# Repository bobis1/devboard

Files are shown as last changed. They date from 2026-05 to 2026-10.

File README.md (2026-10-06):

# Eduboard
A devboard with an inbuilt screen and a software platform that should help beginners learn the basics of computer science. This is a rp2040 devboard at it's core.

I made this project because I wanted some experience working with devboards before I start something more complex. I also wanted to make something where a microcontroller was on a devboard already.

### Pictures

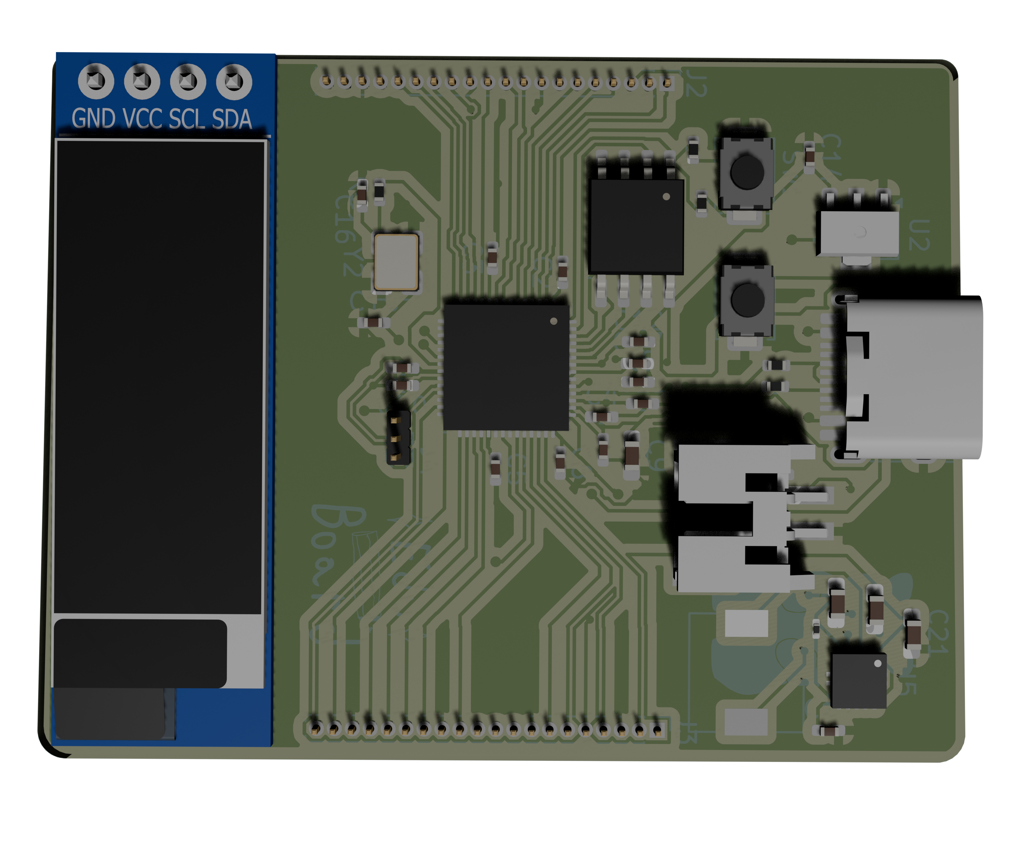
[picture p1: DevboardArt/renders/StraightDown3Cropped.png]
Render

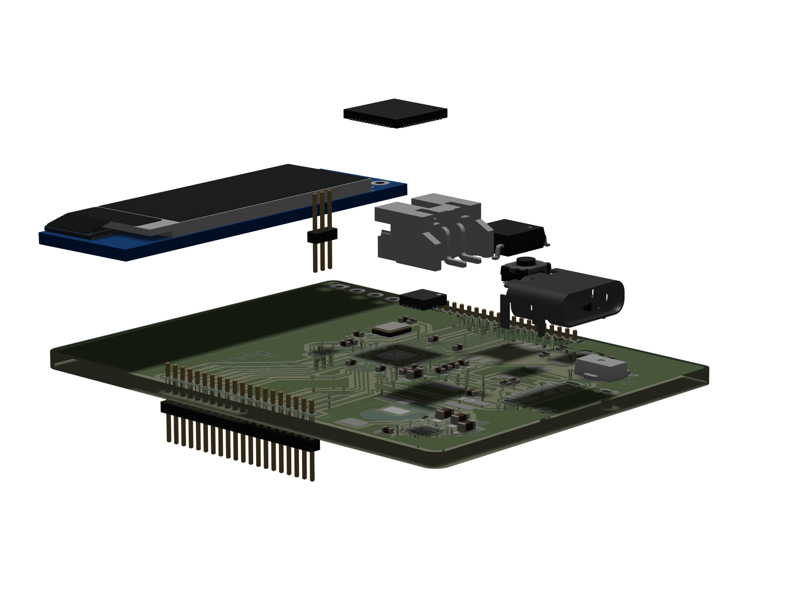
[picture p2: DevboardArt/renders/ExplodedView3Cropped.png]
Render

Above are renders made in blender.
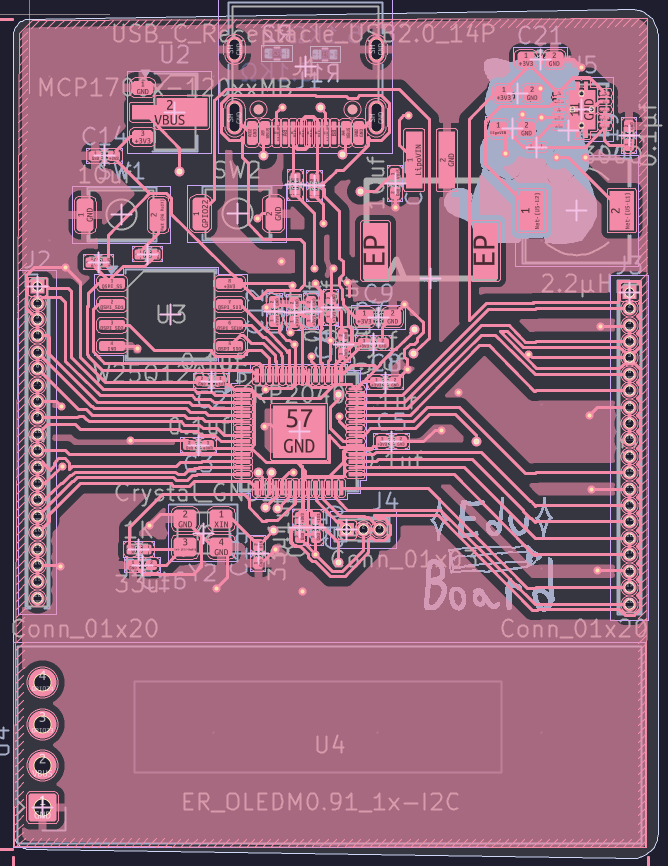
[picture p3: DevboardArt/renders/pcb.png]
pcb

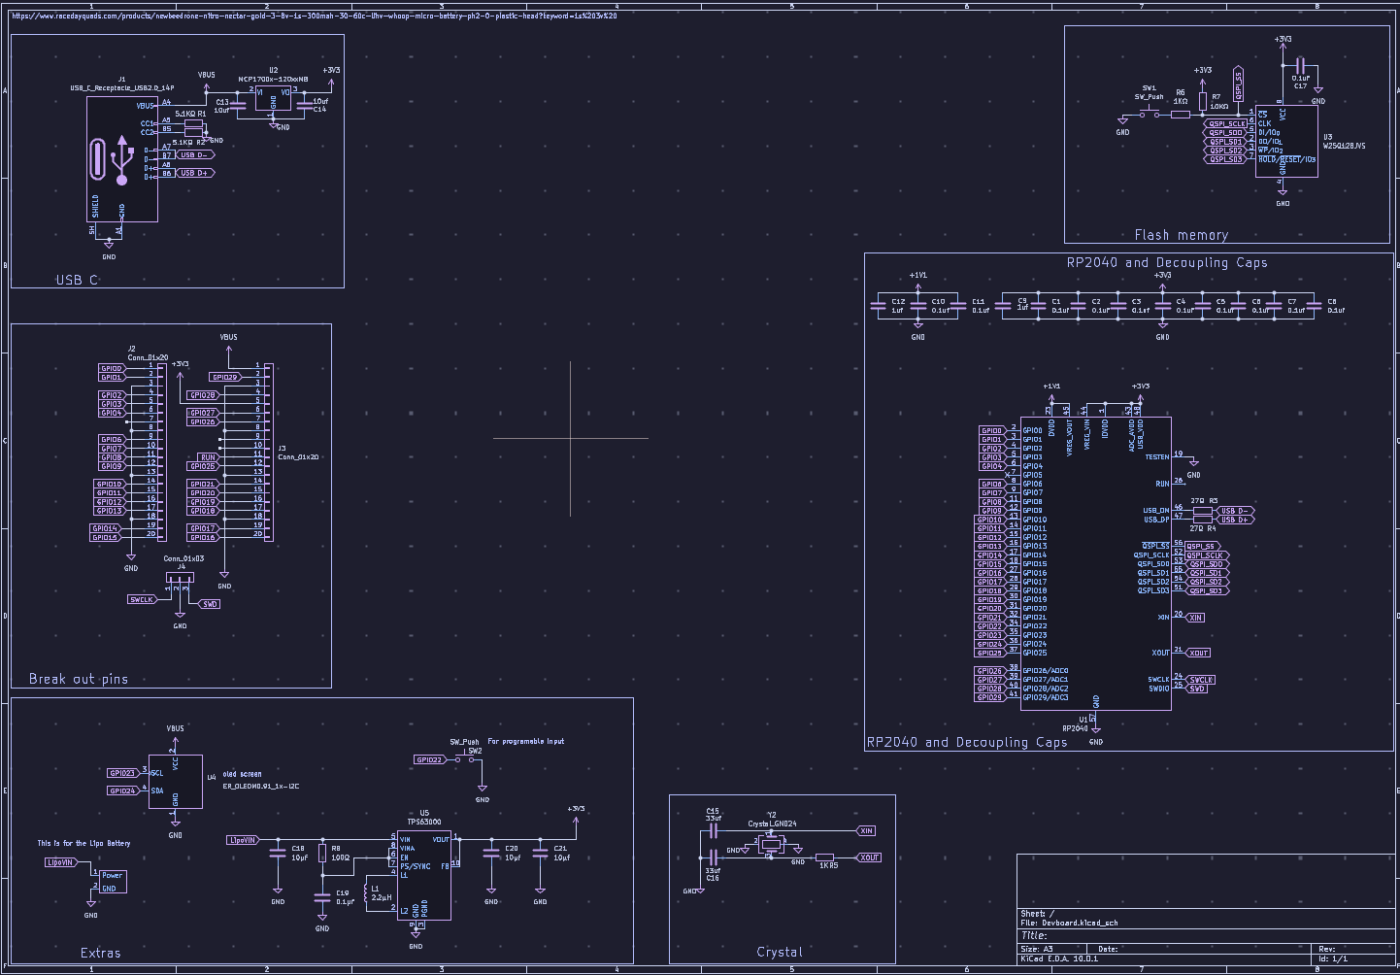
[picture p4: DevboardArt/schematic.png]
schematic


### Assembly
The assembly of the devboard is relatively straight forward. The first thing you need to do is you need to get a hotplate and some soder paste to carefully soder on all the SMD components onto the pcb(This will be new to me as I have never done it before). Then you need to soder on the header pins onto the pcb by placing your sodering iron on the joint between the pcb and the pin and putting solder into that joint.

### Flashing
The flashing of this works the same way as a normal raspberry pi pico. You need to hold down SW_1 to start the flashing process.

### BOM
This BOM is for non PCBA. To be clear, I plan on using the bill of materials labeled [BOM](BOM.csv), [BOM-PCBA](BOM-PCBA.csv) is a BOM if you want to PCBA part of it.

|Reference |Qty|Value |Footprint |Datasheet |Description |Shopping Link |Unit Price|Prices|Notes |
|---|---|---|---|---|---|---|---|---|---|
|C1,C2,C3,C4,C5,C6,C7,C8,C10,C11,C17|11 |0.1uf |C_0402_1005Metric_Pad0.74x0.62mm_HandSolder | |Unpolarized capacitor |https://www.lcsc.com/product-detail/C1591.html?s_z=s_p_CL10B104KB8NNNC |$0.00 |$0.46 |Minimum quantity: 50 |
|C9,C12 |2  |1uf |C_0603_1608Metric_Pad1.08x0.95mm_HandSolder | |Unpolarized capacitor |https://www.lcsc.com/product-detail/C59782.html?s_z=n_q_CL10B105KO8NNNC |$0.02 |$1.06 |Minimum quantity: 50 |
|C13,C14, C19 |3  |10uf |Capacitor_SMD:C_0603_1608Metric_Pad1.08x0.95mm_HandSolder | |Unpolarized capacitor |Samsung Electro-Mechanics CL10A106KP8NNNC |$0.01 |$0.54 |Minimum quantity: 50 |
|C15,C16 |2  |33uf |C_0402_1005Metric_Pad0.74x0.62mm_HandSolder | |Unpolarized capacitor |https://www.lcsc.com/product-detail/C76930.html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 |$0.01 |$0.54 |Minimum quantity: 50 |
|C18,C20,C21 |3  |10μf |C_0402_1005Metric_Pad0.74x0.62mm_HandSolder | |Unpolarized capacitor |Samsung Electro-Mechanics CL10A106KP8NNNC |$0.01 |$0.54 |Minimum quantity: 50 |
|J1 |1  |USB_C_Receptacle_USB2.0_14P|Connector_USB:USB_C_Receptacle_HRO_TYPE-C-31-M-12 |https://www.usb.org/sites/default/files/documents/usb_type-c.zip |USB 2.0-only 14P Type-C Receptacle connector |https://www.lcsc.com/product-detail/C165948.html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 |$0.17 |$0.86 | |
|J2,J3 |2  |Conn_01x20 |Connector_PinHeader_1.00mm:PinHeader_1x20_P1.00mm_Vertical| |Generic connector, single row, 01x20, script generated (kicad-library-utils/schlib/autogen/connector/) |https://www.aliexpress.us/item/3256811704196969.html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 |$2.36 |$2.36 |Minimum quantity: 5 |
|J4 |1  |Conn_01x03 |Connector_PinHeader_1.00mm:PinHeader_1x03_P1.00mm_Vertical| |Generic connector, single row, 01x03, script generated (kicad-library-utils/schlib/autogen/connector/) |https://www.aliexpress.us/item/3256811704196969.html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 |$0.00 |$0.00 | |
|L1 |1  |2.2μH |Inductor_SMD:L_6.3x6.3_H3 | |Inductor |https://www.lcsc.com/product-detail/C52722262.html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 |$0.04 |$0.41 |This comes with the above 01x20 pin headers|
|R1 |1  |5.1KΩ |Resistor_SMD:R_0402_1005Metric_Pad0.72x0.64mm | |Resistor |https://www.mouser.com/en/ProductDetail/Vishay/CRCW04025K10FKED?qs=s0g2FHNyNFj8r6Uw5EJZ%2Fw%3D%3D |$0.10 |$0.10 |Minimum quanity: 10 |
|R2 |1  |5.1KΩ |Resistor_SMD:R_0402_1005Metric_Pad0.72x0.64mm | |Resistor |https://www.mouser.com/en/ProductDetail/Vishay/CRCW04025K10FKED?qs=s0g2FHNyNFj8r6Uw5EJZ%2Fw%3D%3D |$0.10 |$0.10 | |
|R3,R4 |2  |27Ω |Resistor_SMD:R_0402_1005Metric_Pad0.72x0.64mm | |Resistor |https://www.mouser.com/en/ProductDetail/YAGEO/RC0402FR-0727RL?qs=UOUeRUa%252B8Wlb37UyFHw9Bw%3D%3D |$0.10 |$0.20 | |
|R5,R6 |2  |1KΩ |Resistor_SMD:R_0402_1005Metric_Pad0.72x0.64mm | |Resistor |https://www.mouser.com/en/ProductDetail/YAGEO/RC0402FR-071KL?qs=V1yeUXFNrknDEmWLmm5v6g%3D%3D |$0.10 |$0.20 | |
|R7 |1  |10KΩ |Resistor_SMD:R_0402_1005Metric_Pad0.72x0.64mm | |Resistor |https://www.mouser.com/en/ProductDetail/YAGEO/RC0402FR-0710KL?qs=I1mnnYJTTsxUoNwrUsQExA%3D%3D |$0.10 |$0.10 | |
|R8 |1  |100Ω |Resistor_SMD:R_0402_1005Metric_Pad0.72x0.64mm | |Resistor |https://www.mouser.com/en/ProductDetail/Vishay/CRCW0402100RFKED?qs=OlqPY1CiralT1EG%2F62gJpQ%3D%3D |$0.10 |$0.10 | |
|SW1,SW2 |2  |SW_Push |Button_Switch_SMD:SW_SPST_TS-1088-xR020 | |Push button switch, generic, two pins |https://www.lcsc.com/product-detail/C49234124.html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 |$0.02 |$0.49 | |
|U1 |1  |RP2040 |Package_DFN_QFN:QFN-56-1EP_7x7mm_P0.4mm_EP3.2x3.2mm |https://datasheets.raspberrypi.com/rp2040/rp2040-datasheet.pdf |A microcontroller by Raspberry Pi, Dual ARM Cortex-M0+, 133MHz, no flash, 264KB SRAM, 8 PIO state machines, VQFN-56|https://www.digikey.com/en/products/detail/raspberry-pi/SC0908-7/14306009?src=raspberrypi |$0.92 |$0.92 | |
|U2 |1  |MCP1700x-120xxMB |Package_TO_SOT_SMD:SOT-89-3 |http://ww1.microchip.com/downloads/en/DeviceDoc/20001826D.pdf |250mA Low Quiscent Current LDO, 1.2V output, SOT-89 |https://www.microchip.com/en-us/product/mcp1700#Purchase(3 leads, SOT-89 packaging) |$0.51 |$0.51 | |
|U3 |1  |W25Q128JVS |Package_SO:SOIC-8_5.3x5.3mm_P1.27mm |https://www.winbond.com/resource-files/w25q128jv_dtr%20revc%2003272018%20plus.pdf|128Mbit / 16MiB Serial Flash Memory, Standard/Dual/Quad SPI, 2.7-3.6V, SOIC-8 |https://www.lcsc.com/product-detail/C97521.html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 OR https://www.lcsc.com/product-detail/C97521.html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|$2.62 |$2.62 | |
|U4 |1  |ER_OLEDM0.91_1x-I2C |Display:ER_OLEDM0.91_1x-I2C |https://www.buydisplay.com/download/manual/ER-OLEDM0.91-1_Datasheet.pdf |SSD1306 OLED module, 0.91 inch, 128x32, I2C |https://www.buydisplay.com/i2c-white-0-91-inch-oled-display-module-128x32-arduino-raspberry-pi |$2.80 |$2.80 | |
|U5 |1  |TPS63000 |Package_SON:Texas_DRC0010J_ThermalVias |http://www.ti.com/lit/ds/symlink/tps63000.pdf |Buck-Boost Converter, 1.8-5.5V Input Voltage, 1.8A Switch Current, Adjustable 1.2-5.5V Output Voltage, VSON-10 |https://www.ti.com/product/TPS63000/part-details/TPS63000DRCR |$2.00 |$2.00 | |
|XT1 |1  | |JST-PH-2.:JST-PH-2 | | |https://www.adafruit.com/product/1769 |$0.75 |$0.75 | |
|Y2 |1  |Crystal_GND24 |Crystal:Crystal_SMD_3225-4Pin_3.2x2.5mm | |Four pin crystal, GND on pins 2 and 4 |https://www.lcsc.com/product-detail/C13738.html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 |$0.09 |$0.47 | |
| | | | | | | | | |Minimum quanity: 5 |
| | | | | | | | | | |
| | | | | | | | | | |
| | | |Subtotal: |$0.00 | | | | | |
| | | |PCB Fee: |$0.00 | | | | | |
| | | |Shipping: |$2.00 | | | | | |
| | | |Tariff: |$0.00 | | | | | |
| | | |PCBA fee: |$45.96 | | | | | |
| | | |Total Price |$47.96 | | | | | |

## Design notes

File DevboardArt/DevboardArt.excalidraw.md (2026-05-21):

---

excalidraw-plugin: parsed
tags: [excalidraw]

---
==⚠  Switch to EXCALIDRAW VIEW in the MORE OPTIONS menu of this document. ⚠== You can decompress Drawing data with the command palette: 'Decompress current Excalidraw file'. For more info check in plugin settings under 'Saving'

# Excalidraw Data

## Text Elements
## Embedded Files
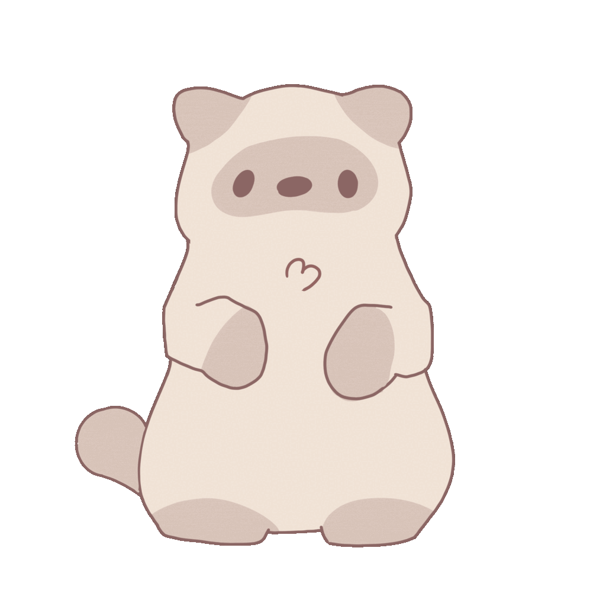
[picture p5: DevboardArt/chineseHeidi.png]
c69bee7dd71ced548cfc6c9a045980190fc850d2: 

%%
## Drawing
```compressed-json
N4KAkARALgngDgUwgLgAQQQDwMYEMA2AlgCYBOuA7hADTgQBuCpAzoQPYB2KqATLZMzYBXUtiRoIACyhQ4zZAHoFAc0JRJQgEYA6bGwC2CgF7N6hbEcK4OCtptbErHALRY8RMpWdx8Q1TdIEfARcZgRmBShcZQUebR44gEYaOiCEfQQOKGZuAG1wMFAwYogSbgg2AAUAMwBxNlrJAGsAESaAFWxsJsTqgHZNfABFACUU4shYRHLqwIRPKn4SzG5n

RL6AFm0AVgBmbb6eAA4ebaOABgBOADYNvqXIGFXr8+1znkueF7vdjY3E/4PCAUEjqbgXHaJS7nRI8DbbRLrRJHI5AyQIQjKaTcWGJHZnS7bS43K67PrbIHWZTBbjXN4bS7wj59XbnXaJa59e4FARQUhsJoIADCbHwbFI5QAxIkEDKZeMSppcN1lPyhBxiCKxRKJHzrMw4LhAlkFZBqoR8PgAMqwGkSQQeU0QZh8gUIADqoMk3D4POdrsFNpgdvQD

rKQLVWI44RyaESQLYhuwaiecfO5yBquEcAAksRY6h8hNIAANCikfTMABaRkwbHoAEF2kIAGJW6pDACqnyrEB5AF0gbNcBk89wOEJLUDCBqsOVcFbak61Rro8wCxOp36wvMcTxYcTzi9fRMGExWJxwWygYwWOwOAA5ThiHFko6IxK7E7T5gtNJQXc0GqAgwiBTRhA1ABRYIMiyAtckHP0hDgYhcAA4gcS5S5dg+HhzhOREgSIDgmnHSd8CIthukA1

BgPwUC/TgNgZ2yPIeTAItiwzdiwHOdjEOLTiJleBkjiJa4oQBI9TgeYpXhRC4JO2HhfjJbZ+NkoTijxI9tluXZ2XObYNmuI5yVk3idj+U5zg2FFjlhdTiwEiYtLAPFLg5DkCOOaFrhkni8TuTY7m2K4+muPTTg09i3LiIy+kJY4LjE7DzJ43Y3kuE5dheI5dmyjY1JiwSeKSZSir2d4WSK9LizAbZ4iJHguVU8kStcsr4hMxkTg2fczIpHi6TOPY

UWRfY0qciYXOKOLtF+AEJORDkNmkob6suHYcNOPp8PTPp32i5zNK6j5+qhS49r29kAvqz9tERCKmWuXK+mRdqTtis7GX3YlrrZRyLPWbqcKOCSwccjq5p+i7/vOG6gbKvE9L2UzIpU2rpuKWaOK6y6Adujbiy+BbDpeRIEYuwbobx+q4jha5erhAa6uLHD4kOArD0x4qvtK+nHoq/ZWRatriYmfZtH+A5Kb+T4PuxsBcbcjzXqK4l/jW/yJeKfrH

r+O53gBI4sdp1XtAI0yDk8mEot1sAGTePCwsOqH+c6+7tvfHrDkinWLL0x7POOf5EtMz6ZtOr2GSuBKJPewbA62z4CrCqE9ndqPvq93T9MM4yI4dzlts5IrVvW82eNeYyzjJNbebZiZNm0QlWVem47LNj2Yfq14vhUj5KcSe2LMO6Wjmw5FTYi+2q/q5x+4OP5/Mn9aLLE+JkQR8HPwc47s4F4s1iF5SarUizsMtz8kS/TlFfn4+8X8rkuSuEkps

vvpLcn25Tb5w+nsn7X1Mu8K6YkR4Bx4sSbQ5JvhwguCZGmPc6bHySKFfKB0joO0pplWy1wmbIkZJnA+ONo5oJ2KceBdl8FJ0CkZS2JlThwi1pXFBblnBxHevCYkLxP70O/usFSr195KxVjxZweD4RkhuHfROTdtJXAngjFknwDjYMfhMSR8R3y3E5McBEo9AqIisvsRKw857sIkZlMkSkbichuHQ+6D12TrF0v1RxkcyE52Pplfqvx0xmTXlA5xW

xbKm0CYdPypDlbkK0ZlBE5ivwTSJBfYxjV/G3HTm3LO3ij7xO0JFex4cnHFkRHSRK9kNFWIXplPaTMrjrE8TgkGplcLCMhjE8RtTYHGW3tCE4gM7plORNLKEEkCHElZmIuJxRtGm3Bq9AyWCkahIWkVHeENRGaLmZlBZBCDKsh3qskZ8kjw5RZLQrxsSfEFIuACBIiJPLa2GRMSmdIVKeRuK/cWOywDzJhP1fckkXk4LZKDCuOs/naNRiPMKuFmm

X0yo5YyU9bhsMAb3XxWUB74QZHwtJ9VTbbVsqjDxRdoVcIkmZT8b5okO0SpQhGCIcldNmf8pI6ZXEtU+Ii4aW0jLYS+EiZBmLUFaLxHhU4S0u6EuLESHRhcHnqNyTc/Jcyl4hVXvSwO/c7L7Bdsctlty5JbzCkEnVPETKwIkipK5MyTXuTeP7IqBckEKMdv3Q6CME4PxqWUwpiU0Wgosr8baHIuSM1JNc7pAbZEa0ZFJEJ7MPKv0eQ4il/qJgM1+

gTBGQyHbHHiIyI8LITjVLFfNKq8JIrktKdmxqxlcprU/PfUVeSgHZtgVCOyLNFYWRUgtAy+Lo0OvVWAOIu9hEHASP7V5xR9zS3vjhPS+VUkxvZXEQky9CRPX7YFFOfwzgrONeOvBYDoSHC+EY+6RwbV13Bna91Y7O3FDwfC/y8I931u0t/fKXx/gU0sZWjKBs7h/DMqyZ9wNv60M/J3f+G7HXIs+DCAhdtk1vLpIiZtmwCVIbPfEAqu1sHAwyV8d

4ex6V/MyscDGhJ/gYfne5LYRJ3lHqJjRodZJrospITgupelPxrQMnhTjWa32FKEYlIyYssbA0nQkNKMIRUEdfWATK0J8LrBpaO4GeIImvUOPm8TIH6pbBaiiAqH5OlgsKdSwk5IM6mY7ViiYWwS25XBspcWG9W79V01NP5jVcp6QmfuPTPFv4TJk1yE23czPysKTCSe75sKTTlRMOkvLvJ7W/WptzxRGr5V0cpf9BaLLYc+H8L8dw50vsK2AOk1V

JIcgi/w+qjaqPbFdhW1z4rijYf3HtRjkDmNbAikdEKSbT3qcaldTWxIESqYdplIunketyYAf1tyxXkkY3K0TAdltlIEJw9siTDVCkMg5FM/dgsjymWHR/bbaq5s7CpiPOLsqPV4mWZTcG/UVWzca41FqiI7KmUhcxmu1kwp2XLaq2NExGpsgRyPTyJSPWLyyv4xHIOBuO16Z+FkQ8mMOxx27E42UDKFVe8jvWkIETSRU/Iinf2Ej4WlayhrhOtjI

iKsKtnFkT6PtC1e+rXHPkkZOVo14VOPj5QKoh3n80BnmqOW7ZjOOATDvY9IpHm7ClwhuMzamHqRImVsgyaZfy4hfjMu8YjwOHavGyv5K6LxNi28u+VOEItqq+cCtLLkfxyThUl5dtWqlNYzcLc6p7vwXsFcJwZ0ynw9owh58d8kcPwn49V8Hhxwb16gbhD1zYu6Vt/JRmJf4jv8urdbicD42V7U14WrIz4Lfr2YcZ7La25jycd9OCZOR92ksfmwj

PSPiWu2MzN9M0Nlsk/4cL4LfRcJcSRfqrRxknJWoJZ26Boy7xP3LeF11XPQP88Xbn5Jw5b8nPZ7OiIpzJkfvr/ZvZ+EvXZfaUthui2T6ze0azCVSz3hwnNxwWlmOHZH6nwjpxTzclYxHneTwkb2BjeFNj2FymeQxWP3M0tinhaj+DjwsnlzWgl2A0IKSwSC/Aihfz7mLXBnJD2HelHWCw+02C+24RVxF1eF10WiPA40N0dWKzrzJFZwnzlx2DEgd

xSSC0uw+S8m80bgpzd0OlFnTGczEPHRGh6gIU23Pmxw5zwhOD4xc1AMJz/UzyEx83kwkTdyHgjmkPbWsLcjvU5EOSQI0J/nTCKSaUzXvzAC2h80nlOzehkI1VbhcIb2ryj1eHrnhHOQy2x3l3fGpyV18JrzxE/FshLz73+VeHVljmKWaVyNbgMguBZEuWgycIWhRE8iAyhSjziGMguEcwqwaKhBYVq1nlaJCIeja1qzZBwm6OYK5X+guC22QMCjC

QpkUnRSKP7ndzYLJEpiUKGK2DLiQVjxDWrmlit3lh9yGLBxRHJFJ2gIoOuwQUimoMGNoLeXmyuh61Sky1NSiQsI1gNwJ1VjpAuHwkOBmJMNd2bw9wiiplOKeN/WSxlluETQOK9mOHCj2DDgqKjzvSRDE2AP/ydQC3gPMJyKjy2lOBmNtSgyLiwK5neCjS2JhInSSNQ1S0cIe3WEz10L+ORh2BqmYV5SpK6lujWlNjuF7y5PpnQWtyIV+Pjx4U2BZ

ABBlLtz8Ta2hDgLEzxMnVO2Wlsztw8zgPJBYXINA1UnfFwUMUeI8LKkbUnmhDuAgRvW/xuwBB5l+V9z/WPRfjIKROLHAKMn2AUjbTmPpi2lpRRCPBHnUIsi2H6nLmWPFJJi2kSj6XJ2jJ5O8htgsUtIZw0x0nejJOMht2iKJ0m1hGm1BRo2fjEkLh/SJ0WVygNSowIKtN3z333DD3JAKlL062dRRMSRdxowszJH3HZF+AGOY0ain36NnwZKliU2U

halPy1wdknKeWnJoJbPZmy3bgMkLIVlrNR1XiMnWAHMuy/Fbk/WnwQ1ZN9IvJ4WTy/3czyNyk/Eng5FTKtW7TVJMjOA1ITKfNgU91MnhERnG3TMH1tjG0fL1j8UMS/HwnXQdgs0YK5CbOzPZXhEen9LiyujFKb3Sw5EijZGo0u2tXkMOGq0QQFN30KVqwuKZn4z+TuEKQOFsl+FYqO1A2slsnehBWbJzKdkMnslXTSKbyuByjymVyP03JR3kj2ml

xdxz0LJsgRzvwZIREDX2DRIISx3jy93wmpWh2goamRS/AKkOAjT5UFi+Bwnfz/mkpzOMhYvCWG0Pw+KdR8lGhOL9RCKDigxwlhGCWYyClD1Cgjw3MctgxeAbMYP4ywJUg+lOFGnpJkqKy2jUgig+AKhlJuOUvhyqT0PUxeGb2EXwikvcpx1JTljb2fT+QkkKU8ja02IqtWNLWJHZHjOMteiamPLMmygLwEJXyuFemE3HK6o8wRA91elYOnhF0lQo

sShZBERAJzJLjZB9RWzmu7Q/WrNquUO/leKDT0iMiQVRAkQM0gL7XcNWqTK3x8iCop05USm1jLTUtSrAHekejXjJKiW7IoX8pyiuuDOLE+rEiMh63+DuxRBFziAbmpWFL/OMsOGbxMj4qKM4R2EPGhAOF9WuvZRbgoxMkNP5OhokS4W3R2jwr+RbgVnhlAsev82OA4JSpzPJFooRhp3KuxzwW/J4odPQsdQignk/HYKJHHJF1MuwkF1xuBubjpE5

DRxDmaux3aMCT3OhPeqFtwVE0sLxJPg2P3F/ILWppC2IU4oXhrnkPGjXRZvxpjIZCYQepuIKkISas4OcgHCBDgECHXBEHCDYi4lkkEMNvRhakih6wjN2CDoNmhHGVfP8jZAimuGjtjnGQ5rtgVLOq4khGHJ60khmIW2js20TQ1PWCkOTvYhrhJEOl/wgxHiPGjuWmegotpIW25GztuD2jOBFLC3YpPGEkDX/ngyRBeDR2jryxJBmJ3jhHenHtHzV

NhD+AKIRnHpSLb0LLjnB3Hq93/h5RKyim3sfTw2CjLPwnHouGI1uySmIwruzsShDsGlpQRD+GjsBPTB0N6KuA+Ffp3nLjsj2nykqlfsgUfTr0czOHjEruvmrqtsnh/KjqgZymUl+gSHyiEVvoHpOE2DCkPE5AjmJFfoNRLuPvOg2EIeQf+FINuFIcIYVj0kJDEkBPWFoZDoYePRhHbswfLmHOocSSuFfu4b9iBzcUuAEdHKEelT2lEcQcEYA0kf4

Zka7qswAz6VegEaUf/SyUAwQezpniMmUa0Y5B0a4Y0ZwkMbUcUf0c0fhG0dfpwcQRhGIthH2HUasbMZsaMdce7vcdUeMdNT0e8ZUdscscCfMb8csgCYMY8Ysd0aNlCeifCfknsdskcesxUl1iSfEpSdwRDhccQeSZbScfSbsaycKbSbyd0YKdSdyYyZO1KeqecdqbBpqoaeKfyfqZycaZKZac6bacqY6aKYqcwaqd6aGf8ZGcGaadRSzyZkF0wSz

uGYGfKamaWZqe6YcdGaabiaid8bEZJzkb4ekd0fEaSsvX0cOGAfWE7qRHeFPwWf8d/vgMd0AbGYieIsNovqWlyn7s+JgZqzPkeU4d+Yfqc13MVPHroaLifvBagcOiQfblURqMgbvvsgD28Lb1nthaHrJDMqt2JCOYHu9UvqZmvs+Awc+MOGmYMlWnAW3seb3q/APthf+CuchztnZGynHsOUORtx5X9LnpAduDWiJsAfHv2YjspewnT3Hpmf2jwkO

hnuRYHraSIYpnCkpiBcsiUlDqukAwjiLuxfDy+HktJuzp61Dri2WxUQJdNVwO5eWgR1+B+csjCm7pUhym7yVxTo0ZUhG3egY0SaOJ9YIVNl3Xucsn8QoaMYSAAc/BTseYeXlL6uvCgdq3EZwkZdemMmjtztjhajwi/S0pzYtfhHGn2hiYHtynpalVp2YdTfntub/nTAHlqfOieiKWWS81smjul0Fcx1ZFbfea+xJwKjTiVdNW3mJeHluzOHJcsnf

Jro5bYoxzsmjoBAKZrM7fDcENzYGVAQ23yjXYbbEwZAWzIagZw0pdjnBk6JHm3aygvoVgorMYQRzajeRB8zFoudTZLe7oByPEDbWnfvfvEnwXhBTsvtXWyleOHMA+mfGTHOESWRToIVQ5Dcil+HGjnZEh9akLuAziKm9cNdxYkhTtjurtjoOHZHvdEiHePXgNemw4+zda/Glys0DeSbTk2SJAbqgcSU7qBOXnTARCLrbaaRajzpaiLt3Y+GMlHxH

iLrXqWJwiWyY+LsocBjLvqSLp3tdUPHtOUh07iYGUVxt3PbNZLaTtpquiLubsjruBuF1wNaHcyJZACtqbOEEY/RNfvZY8zkWQRhfINfheRHQyWvHZddRf87C6C747+YhrsnrqY9HuA/dfrxtkboTZeA93zdqabs7o+FbsWsbvbdFLVOZBs6ge1cfV1cIrMhK5gcinfGIsI6q7TvJggZa8Df8iIaKgQNG2S9IOZ0o3AXwnvZGtzqkY2y8kbsg+ui5

EnlZE1ZKNkYinQZkUboKYPFHuUjy/g+yhFrUk5aq784ZHlKJsbq9OWx9iela47rQ/Q7RKw8bp9dRQMSaJe6sfnve8nhe6U5Ukpsc5e+xcx3fLHqq8XeHvelHt+EbqQY+DVaug1bh6u4MTR2RBR6G7R8WnG/I74XT3zMM6q7x+GsnkJ+dZKMTSufozKvnUp5ZaTuQdp7y6p8Z8K//RZ8fYB+Aqo1x654Mh5+VxlbTqnoVfw6LtXRfneitawgg/Fcz

mHhjZ7au8RAGnzUKiDs9u3EIH0EnDQgQEqB9uYD9u4DogYlPEkFCHaCwCgAABkZxSIgIQIEACgABfJYIoEoMoCQFSFoAAWWIHoDEAACFlA7I/eeBCANgABHUyfASoJ0KYcQdAWYBAeYcgRYP0FYNANYeq8Gw5MGsyfcIEVMVADyAiBuVgqVCNIEEEYgMENAXKba2uWtBH+tKQDELEKAbgPxGlD5xGykDgakZP5rB25By5DqrkIEF0fkQULUcUKUO

UWUJAMCZUJoLMdUTUUUBf3UcgDgA0I0TIbvocC0a0W0ZP50UUcMbcAMD0L0H0af2/oMEMS/x0CMYQKMGMHEBMJMFMHEdMTMGqFzD5gA6p4MsBWGrC1h6wTYVsO2C7A9g+wmKCAMOFHAYQ0Am4CiH6BnDEA5wEgBcAADVlwEEYgGuA3DkRp+afNAbwFM6hZ7mZ4O8JeDQCXIbw54e8E+A4Avg0AYXQriZB/B/hgg6EU3s7zAjEDoI6QI/vBFmgQBk

IqEQQXGCwgqdzCwKIiA7zIhbhTwYoaiFQLN4IAvazEOCKAMazcQ+4fyS2s9HsruVXgxFZolDVloAEMCNwXAgPwaIB5ZixlHHAPCCTolqKd9CTl2QFrjocc1WIqDPkdID1U4hILPIxV9wh4Fu4xc2ma0MghszahVMAtgRCGIg2QFpGHIqlRpA5lyTFEquyVBI3FEqbxRCtTTeBJpwYWQqCoNX0bJRl4GtHMgKiFQBEbaLVBaFVDcGVEI6+wIDv4O1

wrc34f+f8tpC4RRJ24nVQatg1thCtohZxHRDrU5J+FiQaBHUm9RzIgxNgfNbIezi+r31DgeLenOylGTepBUPsHKudR0QSRp8dWCKpuiCi4pQ2a+Laq6j2Dg5P8duJIC3hwZjUtqmcV6itU3SaYFu8pcoR1mATHoaURtKwjmThCWxQ4rIE8suS2qvR36qlYEY6lOCIjAuurV4dcIcQqJ4sJw7ESNFk6jYwhcyPEMCQizeU8a2I7+O6ydYGI6h1wk4

J3S7pGpjKLUfzLxVZAbEd8wCarG0hlo8i70iMHrP2VRFk1nYyUTIqJTtzy04Q/pbdNyJhoLQTygRXSnqUKSLJISpwQYQzVyiTJ9ydgidMijFhQhdykIrRPbi1FsYdRvuBmBFAijWYWi2ue0XAkdEYkQieEShKbERBqEg8C8BmMBSlYOFSR46UZFg2RGUYjRGor4KG1CzqEa88tNGMdX0aIUNR7Ib0Zjl9EMkR4UmRjAuWOEq0FoqHWwcZQBDdp0R

7xcsTLA54rCa8mmA8IyHXLo1Yad7FdM2LaKIixRGoj/I4MGRwjThHkA0hVFYSdil0+KWEakNTx5k3Y2UIGgzWfpsgUoFQxItgTzrxjLUoYnYCNXejj4GR46dKq6MQL8FZRa4+CvWOMp3oDI0vEcXrXaJSQbxm4kItFjgL0MbRFVWGgiSa6I06qtFb4EtVsw5jKxZo4yntjFjsg5OVlChEmIZApi3SvlZ2IyAdrao/qdoreFK1qEPDHU/OOFiWjrT

li/oVbfYFBS4yhdPOoperBqLcQxslyWI8dLDQHaQ1IJ9E4FMZEOh7CO8HwvgjeWwkIxq+Xwy7PJE+Qi1vcxZDGrSQUiKEox6mHXMChZichFK1wq6Mkh9HBEGSJ8R7L0X8gMUEhEqQAhDUKJjD/kVZcJFcA4p60DMAGEYdyMpTho2QRmQybZNgTHA6RRZE8YpJQxUItJtZE+ICNY7MTFJYScuCOTpRYTqRNw60aEICFhSpMaGHAvTS2qIELKGaHyY

1mcAhYiETMP2FSOKKM0Qp84jhM1nDywh5WExY+PLkiE/EFhOkipKFjDg0J6iFtTGmJHeg/IHK7KZwN/GVzDwliPpWQg3Hfhr5oUd6GEJ8hhBRFApghVGHnUuKhTsp82RBFMlUkyj2p6YBWHWPfE6TUcWDM/LNPSJvBfyKIJoT5R0m0ZHccLC6XNKah1YoSl096ifC7yTwZcQw6WLc14Tu0Qi+tM7ttJaglCGiYUFyf5GVruCSi40I8TNXulEhOpx

QlCYWPiAzMnB1U2QotxNwX5npWwkBIaIITtZOhawyaudmWmE4ea8rEeKJnRkxTXyYDKillPJmwIAO8M5au5N9ZHgTq2k96rlNk5chGOl+BeEFA5HoZKJyhJqOSWcb2o0RRyW/GTM8IGx3wGbFcVtQ5HBQmJpU6BPSGagRFRh+wkURyISIhEtov8T/FtQ0nvgAp5oymIBXLiRkQxFCYScbFElDEUYrxJKCSPLEMTFyesmvPbjRi2ImCCE60dFV4lR

48En6L8NeV/Gai8xQRRmarD2T3FgpA1WUY2J7E84a8E2IxghVtFzI/xs4p8eZKLE8YSso1OiVeMPHx02cfsr6XHF+glTtcNIzyXLG8nWyDM1RHrtLOuHQjHxgErcS8DKx6RRCTcodPxM9nVid2EnGVJeKFlEZ6kXMhOVrNJB4RUi2Y64Sk28a/UEpjWO9L5BRCd0yxfhEUuyTpIKTGs38TrmJENSbSapsCHhPrganvUmpRkaKoHkEkxF4Zssbqef

MJzYY2s/rAqejRrhcoCZEMrgrdEcxuigyfhL9IPEgr4Tx0MZdYaTL1qU8ns+UbeeZJsRsFKktOWeXfMxkMhsZ11LXqeG9oxg/a8ESumuwE7d1NgXmHSkx0nY7Tp2DFcGI3VZ5GF2eK6GVixz9YEdA2uHARQGz4WosRFTaMRRch4qCKZWbeUdgfLCwcg5Fj7B3P7AmQqLiKaipRUxyPGUtXYpwKVr91hby9hJqSaViYtzoGLzFxiu+qy14wYcfUFP

btHZ29FLd/IArSXkvRFaw9YWx7ResK0vRz1pm+4FhMvWW4eTWeKURaMdzvq7srm+4W1LU0rwzNUG788zoSzoW/weMekV5vLjs5AZZ28hc+oIxI7vwbWlkSHji0AZ8ICGWLIdiSx8xktz6DSpbNLl0Vc8r6TSr4C0uJZtKb649ApXbCKV7BBlAnQpTe1GWwshlcKSZUIqvbQhqWCJQ6IMobZLKzu97SNFSw6obLVl2ymlisumVrKdltLI5fsuWWbK

FlYxA5ZcuOU3K9lscdZacrvpXKnlhyu+iW05Gn1Nlnyk+ouR+VH0P8cWf5YfS9JfKQVsLX5cCoAagqqGfymFZCsBXgqEVHypFfCrPqQrtmsiVClm23pYqjMcCPJTanxU5LcVmKpRtisJXJKsllK3JdSpJU4qiVdnAkASrpV4qKVrKslR8oZVUq6Wi7BlmJA8V+KQlAS8JcErzairY4ESq5aEu8VBLhVEqsJVKvFUL0lV8q3wSKrVUr0/FgrbxZyF

FY6qvFwrfVb4t8G6rjVWhDJZ8QfpCt8ElqzxejD1X2rDVjqi1QarNVGq7V7qwljaqdXerrV5qr1aap9Waq5V2qjVYqrDXSr/FWq6NaGsCXhqQ1kahNXGuTViqFVqqqNXPSiVlVIamysTt6kAZQh81OaotbEp9WlqYl+a+Nemt8GVq81Kq42LGrFZWKzFRiipZT1laOIkezCYLuk2o4xdSOUDH2fZDsiOIAlmvJAawF174B9ehvShYECEH0RdBfoS

3swGt6YA7eqgp3surd4e8sBVAiAAAH0Ng+A64M4AAASfQaPvQAfAAArSCO6H0DOBJAiQB8AgBzAJ8gQSfGYHMAWBOhs+qANYAcBYr8z08URctY8FpBqwwygVDhuO2BD380ACqBduDQITDSO+mIbEHGDdmq8Oiqc08FSBDCj9iEzIAURGiBb+hZ+wobfjqHQDShl+8oVfiqBXBb9tQ5QPUPv0NDGhj+foc0JaGf4X8wwGER/tRs9D19vQaAH5lRrd

CCbygwmogX4EkCkDv+foRMMqD/5phjBJQDfsAOoXFgIA4AysDWDrCNhmwbYDsN2B4C9gyFJQFAR+qoEYDpws4QDRAAXD4BFNq4L/ugPIHbhKB3ADPB/gXIsCGBXAJgRitPC3gLwj4Z8Mn11xrRmcjIPgf+Bog6CRBm/MQbBFYhoAEIQIGQfryoHskhUzJZQX6GIiO9UATmsrVREFDaDhBjEfQdlsLCOptNwkUwVlHDwmjCZFuKyGVg3G21HUQU+u

XjlETO10cVs9wbDXOR7t8CKxN4Kfjlmayek5yNekDIdmyEQU+ifmuZJPg3xhJxIBmSdKWT6oD5Ncy7DjiBTg5gSewwatTkJCDy9qIRJIs1yeSYTgFsRXRG7QG3RjAKu8FIisK2pacFaLJX+W5DWwXEqpRkmKWFiIpGiuClsxeiQvLGRIUSPQ8WUYWLw7LopHKIWNl3TxKlLs94phbuOx0Y0UiWqXyPxXZQpw3OEDOCT4OwnPUpR6GqnY6hMTjyzZ

1ibAqnHwU9S2d9uKtoVzPjrbdkRGe4rOkQXqYHogJIviCRF3/Je+wKU0c0NOExlP0TuD+QruNy7pRZkuxrEWNeoiSCFBSarD2h/HWzssGcc1tMIkQWZp4xmemjXkmkAc3YQIvWqxgMloNF51su9KdipnDyrhC8bOc2yhBALi5h6NSBJDwno0wcbhc0f6IUiJRsqcVCRI2nljU4sy5kxdErjFzdyF4jUGTMLr50sSptw291qNtT1VFyY4M36QyUHS

jsBo+xUnR8hXT1TRx2IvZALkuEp6F4dIZZM1xrLx7s5u0vOf8nJG0iBJoO60sWMpiliCRvenklm1o6Pa69dIMOA7maIfkF9XMJmB2Kz2CIaotw40tvon0Ty7ck0wnnXjbkU4ASHBWymft9x3pYxjjQ0XuOPjZYmYreLHTvMJwfAPJfwiuQvEESEVkkHQ80ayEaJGFvsxuuZIInuKT7wDkqHun1xsna4mRHcByQULPIeQeEJWWGdjm/gstYJ+Y7mT

mQ5he4m0KQtA/iG8wGcxZIRAyBWIDK8Nb5Wib+GwVhBuTsFYSLmGZC4MU4PShybnE/LINbBy0GyFEaRgkQHVDEaw7rcZSlg0Sw9FOSacvtIPsom+DBcmMGM13OA95TCSbBDXUPIZYMtzZ/D3uPj3jDYfUFXSYeILZRE4QuaSXehuz3USKDB33RJBbTHSVDmNSJA9RozpV1gNWeKdrglH1xjWp5EImtDeAshJqKUmmf8if2hHjKMRhVkzTFqAHj4A

qAKtbkglMUgoIQ+4ejVDLPV3h329TPrEjJ/w1ErBuZGeLYzGEkZ71fWH9vGQ/zscYRQeJQYJ3RGEk8lPCIyGUMi4toCtVJE4aXnmYtgL7dWGtt0MmymkAVSnT/pQIHS7UPHIuRThTgYwpu400igXsaoIxEZuhm2arz4TgxdSpFNfaqIlZSGhZS8TWJBnbykUmRQJdVplNMJJFfyVM+IUtt9JYl2CoUZKhVRtmusIal0Ww0gq6OMZAygsp+CUUTqZ

G9dhOMKI9DMq4VLKDO6kSUTKzYRHsFZS7BpRclxTijTc+XIlouObD2UGldLPpx4lsj7jlsZthy3N1QS4g1DcxJsEO3s55ISEjGM0ccprYKJM0+SZ8cYQRjUxhJ6Y41Vqj9UK9jJ5MfyeL1zZJy6E9hnUYslu5QoADE9FBPmxshUG5IT3IVLWA6RS29cDXVPs6zNZPgo+aajArmo1xB9epnRHA1sht9OjnMN+D9IqOg4xDq0N6BtLuOWGqiUc96VE

fUoWZnZMBpI0cVIJqkBTtmyABQt9o+1DBvEHtpB3Rj9sjIKdQFczn8hSobGZHWVjJi+zUci6srJWfiyuaVn5FkQjrn5DrOPtesRSXjmayyZcdGz7ZgepxwbPeYmzfHTs/2bbNqd5e+dMBIlCLrjnPIBdKc3xxnPbwKu05qxROeXMLm7Og0HYceWnObnLiQHETnxxtU9Zvk+ZK1S62PPiRgV55muJedPOL1ROgrE8wfgfNHmQl/uLw6HtE7vmion5

yrmawLUZ5JOESu1ocgdZWZ+o0nBZRSPk4ecGeyyqVggl85KdHsKne7Ypzx6IcTRBkCXm21Lq1EeztrKNvhfLo6dHm3MXYc4uOqLsKLBnKi3QpM6FRqsOnQFVZz+j/nezVylIqlETW2sClo1Rznd04vjKBLXhjjp0tc6iYFOfHCSx9CksedZLkGdzgay85n4fOKl8Rt53eCmtezUXAdV7li5mt4uhZS2YRa1Z0dbTWlDGCV3sWFclMxXNro1067ZV

uu6Tc6E61sjDxBu2DSmCN0LXjdeu8GRlvQRvPXYTma3P2Btyq7bMe6ByJkI3RitHo4rRPDuvtyVmi1INWrU7rqzwwRKHuj3TDrok+5us3ujDWxcq2wbiUAeCQBHhFxKJVLQeMPUK/qu4aNWuUzV+HiSE2IcE8rXCmnhzykUcz8OoiyxforbVeYO1LigTm4qcXZqGe0ShtbC25bPYY22NIRfBbZZUzi1q9PHmkrkwdW3LXV9VrxYjZDdxK+HW4CPF

CsDwfLuIGoudcnWuZnQOvPXgBHnWpnk+aW1dVbxt728SIS6sIHuoKCe9IA3vdALUHaDnBSAmgTsO0GIBHAAInYZwDmCOAIAWwAAaT6BWgPN36+ABf1T7p9KAAG1YHtAWgc0fyvwopCX1WA2zhOImK6EcKdYSxENEm7gP8FgTQ8RCgekoOiCw3d80ARUZ2NIlxKvI3NQ/YjfSFI0aTAYB+UTW6Hn50aIADGpfk6CVAsbiBCtjjXvwP48anQ/Gs/sG

CE1X8RNN/MTUht4By3Aw5/eTcbcU2f91wqm08OpuTCwB/+rWiALprzD6awB5YYzVALM2wDLNCApM8gPICoC1BmA08NgNwHoBcA7QTzSQO82VbfNp4HcIVqhDvxrodAqLfeG4D+sQt0W9gZwN4Ak5mUcnZLQINS31bTw4EDLTBAkF5ApB+WuQWXwUG4QuchEMrduuTvqCSgmg2rQDZXXkLGt3towRQXa3nJfWlJWsn9gbKJ1wF52/uDrEqkmY8Slk

iHHhlr0vSRIcFfre5QZhiY8CceO3I0RNEksl8weLBsLb3jyzPye8LPO6fglvI5CXexUiIepOPR/cdGG+2veljsUv6blc0a8dUgcM1JyJGlCNkz3GUTZI6UfUga6meXh8fY4hbdKkkz2/7q2wB9WM70ohSTMBfieSAtSs7oxf6DkVlSoPx4vgQx6M8qcaz+iupWD5fFKgFk4zN08UcaGOSyOSxiClGIhysbKg7FzKXIjU4eUWUbUztfo7LBzQJAxm

196WC606L9EekEeI+9yoImo6KjfcYRYyMSM51EpksQ8+Ye3rPR5F9K1u4aYolgJ2njx4B2Gpgr0R6OykSQPyG7uwU80FrD5YGMigWoNkqTyGaY18F11FES5vOq0+zEnJxYwawJ37IQciH2FJTDBg4/XQTEHomTvwHSgWPepN9ElcR/KL4QHRqwOyaFbBSNC5THklpmpPZEGiKNjUaMa+qqGAg9OFpG00HV0rQ/Jl97RoN84M9mhGhHQ5Tt93fPNl

Ex+C392aCUc8gCzM0wnksNY/JRYe1l2Q82u9oQgJMMHNMM0h0xlFox5QWDgz9mNdOmceow0PadahFdYfIZn4omcykfNDQfIoO+Uqmlo5XyEP1axZMkLESDN/Hs07Bzznga2e75SSZWdGJGPj0ZJFlAeiw+5me02QrikJ9TIOjLLWxnT0ZUx0rlgczOF0z8VeN4NrLs2EQ7ZIkA+RryhlVenMlF1ag8in5Flvx4uemIS1uDUXJ2IkKgewcc33yRjv

EuzdgneEC8tcwxcpAnnRk5K4uCXfw82hfU1p3+5jAVExoZPjD+hCWS+V0QWONMB1SI1gYYM4okEEx45xkg4K77NHQxS2NNU30Mn2YFmW0xpLZk7a/sSEzy1WIHQpwIslskiZNtbgGVZtzGUmINGNPivsU2p/aOqOn0ixR2RhyY8fBjLytoFcJ7NAzEaNF7MX/yDzGZHvpP3tI6VCGG+Q9HuCwcR4qafweBjy1R6Hsl2ftM5j5FODQc54sLWVnQFo

Uk5PmTG+LIPRKM6sWp+domwDO17OHVQkqaTfOBUCu3Ph8xlJK8pdHKuaFHshEIHBdazGQRJ0U/2Nz3XM24/XQXDqNPMnOZUXANDMpYKm8gYxyJiO+cxF0UuS6OR6nZOfp12vssSRzZuidTriweOIf3L9HdRp4g8J97nD8jLj63Z5bWYRS32xNd7ucpN8gqaOa6d7nOIY089QkZ4KSee7OoKjMZGyGS/UpkEK5cEC8VonVP5JNJ0deQf7n08uBcmn

vmizxvGAHQ0QKmAoLB1snE75CmGqucckGCJNTOMdS77cpaAydW9pk9pS2uplsU1Amiz62pwCVe8XP5xO4TzrLwahiaPDpY9p71GsdjUzxPZ157UvqJNnxPEOpdjULw9kihefzzEOsP13S7JgnUasolQaqxwaRuu0xKNGYmfJOn9qw5QxaLGPi7lifZCY3At5nMxJbwHxTtQ4gDh4S0TkTqsX3WQTgZGetWkOFV7p/11P7K8UcujzASZpuJKR/rt5

AKg7hpesCV9tGER+rHpVmT1o6z11EAydEucxtEkp3nw6VQKXNFf3Zy/D2lxT2lp45/fKHhViSX7Xtp+5TqQeIITOMkOymeN5pmctNCqBlcA2tNFt0KVgei6Rmbx0xMSdHtlUxJYMN72jCobmW0UiBt4KxLbmL0XfA5tIW4MHM6e3jbAdhOJIILSnVK68UAQKzwDu1xnjju1acvKxa4imlScoGlUPC8k7u1McbGmF0UthcA75WQXhV5RQD8qvr0l6

apCJanQo4Z0KzAP+sx80BiefKzLHD1slBwsLnVzs5yc5NcFeS9nz150TqzyAsEuQLy1l8ibEAZUWZODGWC4p2SYHJW8ekDCzMywsHIOOxFzTgRbU7C/XEoviXha2l6ZDZefHSXkDLQIat5zFnci3SevlkWaL6vxb7a106047SPE+i2r4N8a++ODFrnExbhBGcu6jF0Nlb7N/GcLfdv0K8PJt9O+zO1vwVO7+YsO+3fWRD37769/++ffFnR38H/t+

h+/fpnEP72fN/h+Xfcf6PxH9j/G/KLmv/+LRcN/p+9OJvnXy6wV+WtZfKv3swX5l/K/yfpfpX9ayl9H0y/1f+X9L6r9y+zWlfmXsX6IuN+2/Ffzv0X+7+1+m/7f/P3hZF+kX5fw/iX6P5b/j+nok/kv9P605mWnT8/yX2P5Loj/tOq/jThP439T+1/2/xf/iGX+z+iLR/nf3P738z+z/J/i/wv7F+n+D/6nWEOv4f/i/L/L/+/2L57/l+a/UvAf3

39/9d+P/or6ABDfv34gBZrBtYLY3zAjg0+DPHT5lkJZu1yUcmdCnQxWgTqGwIgO3npYHQSev1CRQObDao3iI1GTw9sVSp1JSiUcjeYh206q9YG8RvCbw7q5vDzY/Wm6n9YVaOgkDbFAINqUCHqxAOjYtAuwGwAlgAAPLVAzADwDtAMAKQCdgLYEKCdg2AJgDR8uwInx42v6pQIZ8xNjnyyus+tBw7Q0PElTU2OfLgiMIuSs1xPMZ3n6B18DfKgAC

ohorJwg6TcJhpd8//MViowvLvKYlARGiPyS2TINLaT8lGjPzy2tGovyMaK/H6Bq26/Kxqa2u/PqDcaR/Hran8cmvaC22ltnfys2UmqkFJBoYCkF+gkYMppJ2CGs7aaaZfAAJ+gntiAJTeBmkZqQCpmjAIWa8AtZqICT1vZpjgPmr3ag2LmvODtAS4O/yb8Kmm0GR2JQGnY98GyHDDZ2rAowKoAN0AXZsCsWtwDUWiCF+AV2CAC3ZfWNdqIL12Bgj

lpN2KEAVqYQSeu3YEQCGuVoR2lEFoKD2egixCj2hOK1pyQ7Wox46ewTqXA6GSbs9qMs20v8JnQcRlpgjuxlCJCGQnkKyC3ix2CHA7wj7vC5GClCBXg4siHtw5/wF9Ec5/BxuHHpIUX1NjR5eZbu9QlE3hHXD5On5Lqy4OYxK+4Mk2Ibk5c0xcIwiL0bBLeLtaM6L66fB+jkGIJAABhF6HE9pMsK8eYAE/r6MCjlu7sobwWDThUwTv3DIiWbGg7mi

eqHhCt86bu5AGYKWHyagukMvSCKkGXkKJvIa2BnbJkDgUqEi0aiAihYmLGIf5h0Gwvs4jSZuhV73Qa+qFzeGMCtCjy461Ju4GhoyGZSDGqDG546S8kF8gH4wMvdBBGuHudo6QnRBKby6i6Hii4Eqzol6E4+tOgxPStZIOhVWVbHk6TuAYddj3IJOkUSkw4CNoRRCHHtlI0iZPIyAcSZUPeJ7A7oS9LxQFGAnSYEGUG7I4McxgO5ceXRFDoaYYOPY

EWmCTjpJTaRBrFTNhHzj2iRkh2Ce4466KG+Kj6MRqm6vwY0lvbbuW6O6zZuQHu5g7EcsKBJ+OgQsig5u0ZPeI865IVO7rIStGqFFYXxoa5Ke27kKZUOj9gaFOUwiPixI67gmEg2w9BDa4rk94uXKshQeusi64jwcxj+QneDoQf4yYX9I7EV6JQwQylWFaE8E7Yka46SYhrajA6eIfVCk2TaHHCbGDbmBioUKTghE7ErhI3ioRdGB15RkUWGvpeY3

9pcZ/SjaJniBcKslFhbQiXIp6+mUYa4FmIqHAuHFAJwG8ABkp2hc6BCzWNqEbw4UjcD98tXn9It6kCK44OwxKOli1o9Jm+Hv6sBMh66u4kfLRZCSdDm7Qo6YujDR6zGGZD+E4Jr17naFSIg7muEwCiCQgdpE05qRxBLdDlk2OpPDSwC5LN7KGFkQ4bnGT4ZfD9wEDoZEyRbBtgSG07HniTQgrcPKSUUzxn9KCI5DtzYTAnkFJikROkkyLusPYf5G

w0vaH+6hRmoqbAFsUDkihoms7PkKmhsBhWI6K8hpfALEYjuc4Ru3kaFhnYNeqPqMgTJjOgsh2XvlGVR4WKBHQI2GIu6pwfLudqEGB4Npa0uDsDcAmu8hO/IDul8oFzXyxTgNF/o+LEsj7u0KJfJNexYNlCwISeP7hGU80Q1SXWqCqO40R0PNRIdhL0uwa/miocDDpgKMpgoNwApr1J/oySAwy6mp0Z6FEuexqlHnStUCiGnR+Yc2wk05on1KBRaw

pBEaeZSO8ALQxIS9JYkw2J5HChyKBB4Du4MZl6ZR9CHUhpQhZhJ7uCe8n24nR9CDGRKyn7hCFRhe8rMaMO9CGDjbw5MMV4TSXQotRPIa7m8gMIgqnpBiRFMVTCO0YzoohrYDGPdre6aMbEYrwyxsFTAxRNJFCtoEjjpIX6vMcF73QZ0VybiQaNF0hje9AZN7NagdBew2qYdFKKR0a7Iz6V8xmIKprsG1k/hMI7IGuzvsvwsvBIStCjFYMK6MHgxr

shrOdAnUOPj2y3eX0TMQ7Q11odb/Aw6DPREgmZibGfsDNs4prRP3pkKVSESg2yh6VGCpxTK2dDdZfod1urymwpAUpxl01KJPykB2LOQE9YlAT2z5mzIR4ilhPbFj5AyKop2Q5spZo5zskHImXH1mKnMeRI8oVrmLjKpuMKh1s2dCpwM8XJrUS7kBAazydxOLESqM+qkMaxL0O3vEqEUEODUQ5sc3nTbVkA8ShZdwdkFFBMcSeCt7AUs6HUptxfse

kwBxb7BaxowbfEei7xR9PvGOIh8T+zVsTuNZgRKVbPyo1sV8cWxYqnllNwPxFKk/HvwxbPmb7eAHB/FXcX8RWymou7NVAFsCIEWypsMqsZiFsPWDmzgJwCSLS1MtiMZwnmLeBFqVszKtujLi5hNAkMWSCZzg7eaCTgmYJYCdgnwyuCVgmIJJCYQltx+CRQkoJACZ0odwXyA5A5s9CSd7d4dVmTDEJGCbQmWQCCTb4EJ3Cc9oNKrCUwlEJ5CVwlYB

Qif9EiJbcSwlSJFgTImSJjCfImVssiUonsJR3jtLCJyiXQmlK7rHSoNxxHHolL6zCbomZs/QiYnpsRieYmpshiWYnZsNiaYmCq1iTImOJ+ibQoJsdpMQarsM3lUqdkM9MKiPWoBM9Yzqc6grGfW1dswHrqv1t3YcBxQO7zA2B6uUAtgyELgCdgDYM4DKAFABsA5gTQOklWgF6sIHtAwgbby8ap4D+oSABNv+pAggGix5LI7br6wJUwalBo58TlCK

h/hG2IChWqLNtYFnA+IGTFgSq6p3zYaqAPVQiIQbqwZi2w/LSA+B4/ORqy2ptkEHsaEgMrbL8qtmvwb8GoNEHoAnGjrbxBJ/AJrW2yQW/wLJgoOJrWB0moEFW2htjbbHJp4HkH9BZfD/waartlpqAC2YF7bpmhmr7Y1B0AuZpwCVmjZpICLQY5op2XvJ0F4C7QIQK9BXmg7YDBFAjRCVusElzgzBkwW5wopMWhwJxaJLDUKRCywasERJkALXZQQm

wU1q5aSELsEt2RWooId2xwd3ZVaGgjVpV2y6pcFbBSsepi3BvEO1o+whDprg9OpqJVCvafMUiFbWv7hfbMEUkNF4UO9wXVhDS2OlS6CqdEa8HdQ2nizoZhlIWSHEkT2o0T74aMs2ETYM6DQ5KpsXh6SKkF4eVGmoOsHC7FkSZJMiloy7u1r6I1rgMmSx98qhjShCruyk2o2DA9pOhXCK+QRkioe1rQg1WMJJ4UwMBNijOkYW5Bu4w8mlismZGMzI

04nEealOox5OmHBUn4lVDSieUU6ifIA3r9ijGUcpgY5pf2O+Ch4CZprqLohih27Gun7Cy6pSZUPFAweM5Mp4nYGyCZyJGg6I1QOGZHjyKgazUETH0wFSNlwYEqHu9RbohIX5Heuf6Cyyj4BVNgor470j3hcOb6FYLGwuFC2kCUmNADINpu+B5DU8ZiClHqUVkFMTY6YaGAjHgGsuZLNYjkFamLOHmC/DIuK+prRZQwYZrpN8GeF5jrRhOl9Tgyhs

rG5voT+gSRh4sHgySZuleBq58pnqL0iYIjkpdgpwmRIiCYx5mM/AbY6pEJGFikqLgjW0Fob6QJI6iCLbVi7JoaQsmuGe5iNoCQEfJCeB2mThGResIIidRq4Xp4gxL3ttFIUT+oWbHRB0VsLy0hsPJSYenWCJCYIlNJumnC6rtpZ72HqMpCnSz6VsK+6mRIlwjyK5JOgJaZUdbI2pGjoDEo4durO4Z4oJHbiBhn6JBl4kPWJjS+Wi0Io516z8Lqkm

Z7UVkKwmXEQi6To7FM2mFSIGsCjmIekX6ILEuYtXLFkvSe0hOpTGXQ6qmwxjxAoabogOyqpWeq4HCU6nqPoKo8NDV65hv+jOm/AEGFRH1QxVEzBvkh6XjFxQpLmSxUOsXnnyzmmZEg4MGOkKSBN6RRPVS4EZkHHEixWTs/AAM8EcWCjJ4xICSaus5HUjaWxaplntZwsuBjb49EWDo7EwnMCHDQSBhyJmRfIchh96AkZdGa6xVKbA6wRpGs6zkLhg

5ATZWmYNhWC1CNyZMUSRFJHbaK5LYG2kV9PlmUulMXCygeUmS4b0U/nn0Yoy0kElSTZnWP1JsYQISeEYU+nrPrpOHxiuRp6H0CiFMUHyMZiuZRRKZk6Es7F66pGl8ruhjQd2SuR1ItRHgEVO5knZAc2NRh9LKZ26VdCoxTFAsbfAp6VDlYZ4CEaY1p6lP8H2ZyaVJn/BacD6ZJuGlECghsIFIkZOw5zHeygxjlC6KkZu2Y7DsGZafamEm7JoVCUm

UGcxSze5SPIbBYsFEyDhk72b6T6eUoUYTEUUaeFl26CUIFSsxjsPxEqYT6B6l+mrcNaL6KSue5g/CxrMuleRRWI2gC8AooiHCuS6N8y9pwWM1jaUgOaGgSi4se4bqU5Iqkg1ZMrrBhUInDjbkNQw6Zzi7pW5MHB2pXUb5SwYeJpIZ4kYaBdb7RV0eIT9Ss8D9QSx7MJOigO3WTzLRYZZN9GrY81JjitSRuSibTR6IlW6xef+tejwoJecFhYkK6PF

n72B1OdKv6GuZ1h7yDCt0I+hJMMW5b4v+HBm+ULhguzMRdGROg7E8Xt+lj5kICzjVhEpLERzZ46L0kV4u8M6kkw8uOjBfYYruZLr56BO9GpOo7NLRjpjlC4ZLIOmI7mBQEovoyielebtjj5XuJPmFSIMA5AO0x9oSbP5PqEE7BUBhD8B8GT2epQ/5KkSxHuQYOAfgIesmdSZE6VmG84z2Q5Ka7vk9BiAUVi8BfSK/YNiDLZfazOXAVromBTgh/i/

6Y5mg4+Bf0LX6+mHISAYXJiFFoFXmAQWUF9CK6lSh9OimkBZfeaLAD5kUSAgpM6uY1ENQe8j7LBu+jkrg7C3GbAVomVCGAYMoTJsIgJeAhb0kIU9+o45ZYHNqSCusNId/nbiKhTGYSEwFMllDhShaOHuUk5OnD/h7TrtgHUl6PlARhRRPzgfQtKHNGEmB1JVCxk3Jkw5lyoeYoXWFO8EfaqusNAtgIIdBTzIt50hWRkLop0hsY85khXvAiUAufFA

nmhhXLFIC43lQrpmtwYITDmlGQwpD0tCvmZ1wCUMKyPefzGm7v0YkBBzEWwPq3ig+sjL+QhwZ8dnQGGX6M2xi0nRERylKNSuwmQ4Q3OgRFm9iU0Uk8ZZlRwY8Q5iLzwYawhFB4+qLAT7sczZsRStmPHGOZ7mQnDuZHmT5leZnm35nmwfmL3hxa2sx7LsWQ0IFoBYSc9PrAFPQ8Af96JCy1uBYs+0nLcUTx9xXxxs+cnH0gecrxUDgywUFt9zs+7x

T8Vvcfxd8UvF0FkCXSWiQqCVvFwJRCW/FUJeCW9mnxRz58ckAUnqfoOlrawoliFjAHIlpXFAFolyFriWolSFopyElWJeiUusmJdAHklsOKSVUlBJayx4lxJTiUMlRJdiUQBtJfiUklLJWSX0lz0IyVslvZpSWclzJXyWsl1JVZAclTJRAFc+IiKpyc+WTNz5ylyJeD476yHMqX8+EPoL58+CHJqVqlu/lv5v+d/jf4r++pU/77+n/mAG9+2fvr5p

+Zvqn50W1pZn6m+kfkH5J+CfqxaTI7FiBaWcnpQTAsWXpGxZ+lfHFxbmoPHCBYhlucidY1w/FmOSCWHHDGUOcYlrZwiWsZUmUyWLnHJbKW6ZZfSSWWZWayKWbnIbTOcOZZmVFlMlqpbGsEmRpYk4WlslB9qIsKFwGWQ6vmUhcAXOFxF0F3o7iFkfXB2W6cCXKZbJczsWlwfsg/giaQclluax5+CJpDwjpGeHTzJYM5dJBzleXE952WFXHlarl5XG

3Q2WzdGuXblbXLZZblDlh3SCszIHqz1cbXAr61cIbBuVXlPBDeUlcd5eeW3lOrPeX6sjljvRNcOTEJYWp73l+VdcjdB7EeWA3IBW9cwFV5aAVPlq0Wjc4pSrzQV/lrNzisU3CgqZc45fQSTlzivTaG0feWHAnkgSVII0Bs6m9ZhJFwd9ZRJrATEnO8nAYUCJJEgC2D0AJELgBVgtQFABsAbAPgK28F6g2AjAQge6BHqFAEcAqB0wBUl/qGgdUk+g

CMCjJdS18mnC3AhgUBrvktFFhB+wzRGui185tnnxZCAwmM5OBwyYRRNQ1RLdaJwdAl4HcAghKPQAMNuKAitQzNpck0aSyfRpL8TGuEHrJUQcEExBXGofwmg+yQbYv8CmqkFnJkmhbYnJCAFkGv81/Hckf8+QbCmPJamr/wvJJQe7blB1wRABDAGwMwCSAk8LgCaA+ApUDR8+APoBDAMAAgBGA7QA2BCg+gE0FBJwKacFYC4KbHb4APQbkHECDyfS

lDB/mmgCKQRLgwzopLgTaz0ChdnMFxgp+TQgJAeKUylMBhKRsHiCrKWSmngzdgilt2CsCnEqC/1nCnVa5wYwFD2JQExBXB6ZtGnj2d7tyziF8uvtk8EhyIJ53uoUCs5w5NxIgivkopkiH0MW0cV7Uk/ccpBXpSIehoC4snl1BjGHDBeKWFhxBcDRFHOcWi9R6GSlnRpHrlVR/5qIeAg4ZP2S1qtwhYQEibGlWB9gzyQNcwSLYaNc4L6Ob0ItSnZQ

aemBfocNadEBil3m9rmS5Josjn2LbgZioop7LeHtahDhBJipZSPqng42XEpkOpt2OUbuUoyL+YBIU6UiHHVS2fvZhihwBRTX67WpJCw6uuQiIJURfBCIDu7kWNxRSRRBAYG03ORhnb2Vjmzm/Vu+KxKjSTOT9H2hCcF84yuUjohxaYcOova9IFmTKHs2VDBDqE5DtR96k542Pp6RClEUen610HNbBZiY4R6Re4CCgIW6SgYmXAeF4WQfYy1+RimH

X5rUdabXYPKZdV/SkqAK7tksjjpAOISxgEaJ1h0DflZZtGL5BTOC9hnXpCEaBXm1kJcArn9Z/tdu5amfRCkZjwQUK4iBpHtUlBHSALiDR+IGWY3W9SvJjJj8F87qGQhwgYpZn61ntaPXiR64Qt7RZSob9AhGeDhvBg4GbJJSapOkoGE0FNdR6i2RocmAWoFL0vNT85NUTwat4h2SmEk5s9ZfAUe3pN3nAIabk6HAxO8HEYUSYea9JpY++EKmnRvG

dQw+EAEZ2GaipBFOLBUJiDcojRP0arTskOhJyE4YIeKJjNuKaRjQNIWoW1lvIoyJDE7ak6JUiuU3BeMJ/iraOBjPRV0s7BXWKZFPmcGwcCJjiOpBVGHrhF1SIVOOoZGtCJ5GOe4K0YYDmUhLOxEpej75nDU1AamwmMWiLUvjjmnaIuOV47kYa3IbkoNXDcI0fO0kRHUKNUGVJCNEfUCzGP1BSBFiywv9fMSToeJovW7hRjMsjMNbyH8CxGE0JgoF

1f0sijvkDmYgV969yH1TzpK7ouQe4bjeGm+6iykY3+hf0lwhHexdWUiom8lNSxsF0DVZCx0Ust57aQ0mahzxETWTOGY1b8DmFr2rSSJgN1V2fuI2MfWsjlkYGSOhpMe2jfnJ2RCuZJk4IflEthI8gOU5K5NyUPk2BQ7mexSdczpk5JVs+CDY6VNk0mJjgh9DRwj2ioDTTFxNEorLAss5MedqBNCIcnUhN+nh7h9RMRYNqzh9SIrgEaITTYgIFP0X

giG0HjOAVoEf0ayAdpUNVzq6N+ZDnkWNORiqLlEj+Sc2z6ZzbrnrsKMgCDFpQ4dojlIY3PgY4I7NsEahpomYNoRyQSGAoHh7kNoFkuPqfI3kNtcFl7BUUsHvBS0rLk5Ic8INYvVeOeRIXCqOkTYb5aE+NU45MiswtDxT1yTfpDhuv2IOh9IiTf01XiqdDE1OhUIK3Cxp5XkjWBCsNLXANN5udpDOhCyIE6qRkzfEAbu+oTPZFiuuFjI4RvLY04Bk

5IfpjoIGUoS29SNIiXmnRNETwhuhx9du6oZ+yFvm0xF+niKb2o2T3Kze3wEwWSxczZQwiwZYWq2cwZ9YLXgoIcbGE/ReREXUzNtMTSKrRcZBtkB1sZDU4rpoRKGSaZerZp4OcXtQNHKieWIBgVZHoY7W4uHqFfB8GsOV/l/SFtVcwcNl8IuI91STUPVSYpjbyl4kJkWYxEuI2WrVLoWNPK61km8M8wYu5tQbU88UecZETYIEdOEZtakP1BHC8+sW

BsRw6ESDheEdUkS54+bLc48QEIDVZ/NgQiJCzo1bYkbjwRJEA361PUMGkltHqFyDxA6AeznHN7UstBLI2bfO4kxsnIB6qtGbZ2RRtDKP3XJR2TYQqBtt9VFh/izCA/UR1z5EtAbphUkzD2YosHmzp5gQjvXV1MdVlkzpONGG17tg2ne2+wYacNAAkQhA/koNH7dHWwhg2GIYBEE2tCgOtgWO5Q/htRM/UQdj0I63AtxVK1Cj4yequ3AISdcC0KoP

BG4YlNFkmib3tYWR9na6bjQh1V1UHbE0NQhTeNDmk/7e+30dtBYx1OUDuFFn+N29exGf6PHrF7SZK6KDLHutrhx171SFL628d7rRa0uSRWYW5WoWJGhiuebHYpKPRzDj4bRkLTi+YqiEhYNpnIukCQZ4uXCIly1Y9YZW31ISbdw2SwJsmFBO1Nze1KJI9dL8Fe5HCbaZe4g9YZ0gxUGVLAOckCJ/lydGbdaGbOAGRph2OsEvZ53uzbOfhL5iZKXB

zpceSSGS23mA8TeuWJGuQpGctYbCNIulAOgkxYcB0jBZNwURhNEKBYVIJABUTgxEhetTmSCEzRA52K1kqAGRAEEzVqni1nXjggzpDFCgaO6R1YpCZUSnfdAF6gYjdj01KaThyGIl3sM2GhzTIK6Yh9XSHjTddhTC2cwTeXe7fVCRs2EmIdpMzy9iWqSDVHNPbjySLUW+LLlR4nMCKTl6UGdyGFQO6XV2nCyWHqEKtUWIAToaz1AnXGuOBB9VpN87

o0SbYgqrzUxCKYgxgIxWWfiCvyQ3cAXjpyWFPkfIpaKjAmd4BpjQMEkOly6BRckjIWFChsC7QPt9hQbBjsf7WHkZIeTsFCTRy+HhridXVJQhaUTYZqTYEH4DOigZL6WxTPYrbc/Ydw78AW3mik0uWh9NtZGciexCoky3qYpJNQzAot1T0R2Wg4cXJLwjimpl+EronwzahNeOJL9CK4VBm6ShZoaKHtlRF2Tnu+XtcJLcgJAK3WyyKI+jIgCkebJa

NAhTWJCxi+ZtSyihXL5ZCh5nkhmqeA4mnL1wqXot1iZxuEGi/NJpnY61owRlfVDEvupcig1zYRjQ8dr8nx3jpNcHLBSE8XUJKIWaHfHqKYx6GFjMeKMLgSGkN7TFkGwt3NK7HyycrmIi5kjmMhd0ImSaZJESVKTW0dj+oAQIE7qYL30tzzcI45pSzkQizuVHoLBmMDSO4Hd97DidWVpF5IkjoSrJjRigiSbFA2oh1oidQjeKaZoYtoY6lI3DQZNq

ezGZ2CgnlH6qrtlh9c3evh2SwvuiTjYQFDn5iAYU8PbLY17MCbIRIDcms20x7EThSORpFGi3/Q8BBFEctLFIXybtqRi1kEhpYVQ1JRAteaKtGUekmGa6NYqY2Dy9PZjl1I7zY42/Y+nqlD5EWhdEYBOs7Mrotu5Inij7AwdWB6Nuy1blFr2WJJegYcFTUxQHGRxnkYc1OXtfBwoacLe7RG9ToxJ6yBTqfauhrImHnWocRgtwVNA6AzArQeWHDVMU

n2R8HetCIp+jkwgcu/YES7BiiRWY+7gOhVYBXJiYppzFJd5PGjHT66GYw5O7XRGe8gETMh0ToWh7yA6fpmkUvuvATUsXMU656iUES0YSiYmGexFhu+CJCzMLKGakQDAqMRRbaN2jWGWRk2G6hOdvpKSQNZ1IQLmMGSYgdyKpfgyHi2qbrqGh1ta0Qn0CUSZKfTmGvYRRkWEemW+2VGh6GTz9tu+Nli7ccCNj2EmPbejm2db6KS64YVGdUNLoizib

Kaw4eGZ5QSNcLKXsUNbXrBmCj2ArVkdoTT5iMtY4e0STUBMkiaKF9oenCtZMZpY2owjCp3W+U3Qypy9DHOcVj+IqNHDnBYSfYPKUZHPXrDONA8Bf29G1OURi4dl/VahF5PFOI1DhTsFfoeD/xouma1mOePVZUoSuc2HhCePQRv2J/XrBP6LpGA0rk5JrVgLd07QJT9S2lpC7Nh0mbLD0DlLeZjzYYja5HhZQ3gdz46Cg0gqtheBHvork0xlfHFdO

aYLahQjnQeTMdZpJpGADtFLC5QEDA0VjXGvTXdIQD5lUnR5Z/mUyJ4ES2KK0MGNEUhk7c7LQ1CXyNRMQq8js5NYUtou1JeEExmCrrUAjGmKB1JiYQweSjNpbpCMaGHyOO7QGmugqjCcteQqNzkuBN+IRFDUEq3cIWlDAX+Oj0GrkYR8qA/1muYeYwbBG5oQLnFU1LDZ0F5ZBvFCFMUg4+3y453RXWzkMaf3rgdHqHnx51Xw77njpt1D8D/DeJPVQ

M8brWR1/6mQj8BojWWXn3Hd++ivkPVMhZViM1R3FTnjpSkYsRfhxcM46XE4yTmkIizXO4XQdTWOyZpwDWV13KkL9gsjxj34XggroFfcl3jpSUehG653VLZSDGXbVnoGYNRDCGMd3VOBgdEoTvHr9wSYngzJtw0EnIMKc+YWKsNB0PEWj6twI9D5Egov61lIvurtA7jyHRZjRUlOcO1S6hBr72yOrGBcKdj1YgtmIk2OnuNOYw7s4WLCtXEVHDQsH

cZ3xy1suNlFj3rZFD0gCdC+QxRynmthnABfSCOVYk5HxmGp5vfSBWebo2Dik+2Y0RmNETNGa3w9GSNZgOcstVHh2uIzp2RDj0Eo91s6IkBnjgIQQ1lnYYhDkCjE18GSvjOMWEE05gRZMAlTA9xss7DJk0LcXDFuE3bz0VujVNVHIdlutWnXjF8klIf1tWbBhEuyEnf1qFkhMhE4tWWEyK5KeDkBJM0uEFJ2VYhBmVhZNSI0lglZ0WDDkzdwXQRKI

iLCLoMGhJcOHAYtqRvuONDRw01jWFhkFwWFDjWB8hF8wUdOO2B19lBOs0aJq7rLulWKSSZ4yLRkPsoT+lHKeSAjZFPRR84ep366NEzyjKN34SnAHA8zj4b69rqDGwU9UWFkXw4yTtGNbCplKlOFSpNhBgTR9tYsKNMjnFL0IR9PHj3v9QxNhgjUQHd62k2k9RK1b1ynliTBQZ2K9VRYOkKxzVjQ4f6KzorBFbUMoLXUgj55NY1x5vyjLuNM4TD9t

F1+iXDZsQS5eJJ9SjVznjyIhY2Yf30g0LWZMjehPk7/roxAGEb0IRFYZ9V24pJAUTHUi0c3BJALVvO0KGZplhCyYBDR9T24+kNPA6TZ5IY3nIoclPnI01FuHVuO98jz0Mo7JgSDDiizWeik992qs0eBn00yZLImzQoZcji1F50MjH1O+inOyPQoZeEXOMg0LtKGLRNZTChuL004ezgdN740sfJOY5NE4GLfZo+iyDSwF/X30w9AlJyhqGtZHzNws

WbF3kCF+sLlPP0D033VVEYtPW1Hj7mDzQt0F7ZhHYE1LFjMkjyFI+j4a2M8UAtwdWLtD0jpk4uHE4GOD9NjwQEfmyFhp7eRlw93qQ4NRYq5CQ0NtBEuwPCFGpmzS1ojiApESDXQn6NFEQtC3Vgz0RuwbkT2OkLR/sd0aPkMkWOaZ5wo60whH9SCCLHT5TpFDRE9ezw83CZdRxh0ZdDlwz0bGpT+o4K7NaUyibPkgMDtmj6EIGfgC4yRVBITjks8V

NEoOkDjTn51Juyb+IkQudPGRSQMkhmDmA+pQRyk2JUjP9rEVn0U6tjaPMm5sYrUa3d/OJgEktUEkBHJjRRJvCdz6beIQTUYvITA5tHyEZhnD2Iyqb2YUw50MbwpDqWzCGCo0HChdwscWQH1yka/mKF6YotyrzKbSDG7QU0wfkAk57XaORR5UJ2Rl0fY5FRLtLLtnWa6MbUNyQTJXVYX4gCtLu2FSg0YmXKoXo9SYWT2ldjpXQfLRHRm9UEtFji5G

Y0tHJGHuOVPDDR0TOhRzRRDAj6I1MdZNr5RCxq2Gz7kDCAfhC2DVThDKOAtFIL5NYjHOorHST14tVrb9i2QgBDlCQ4IU9SbZYv8FE5Cj7yIBS2IkeVRNr5/8yPWALiiJHMjpoOYSZr6Y7dt09uYRJKnnDPMu1Hooj84K25198Ogs5ppmV/254XjcYhUuEaMSNGF5xAL2/Y9vRenOTwWBNj4MTi84hr6u+lDMk92MUzyJuXi59m04lo9wtFYmmOHR

oE2ncYilG7iOZGEmtGA5HAd90KGF4E9k+wXtEiOSYWktXCMdT1jVo2vlhi3ipxOBQZLfXh5YXc+ITPw2ltZARTtS5AUGUZAwfmehwrDUs5LAJBnKnzoOPsOyYx0wphF5ESChFZzbaUa1OOd6O1RfZyOUxTzLMOk11ypEBpfr4zyy1hReGYXS24cw6TN5ArtDw3+g5ZdRE6HkGkTpoWi9YBNlgQJMjjAMnOYUO24yTfOE1K5TiuQLkiNzUELGZzbA

zzGZTp2dI08kYo40s4jdkWbUCYI0PVFu9qRiQPAoXSwJgJ5B7YBOpGUbtg0CY4Mb/DXalcygRrY+kMuN1DILa9OQ5mOVSi1oAM/LrqNtUB1QxeCo/rD2xAHKvXzEeZNn3GNpFJoRZL3rQ8iM0eaP13RGsOGSh9LnNQkiKQuDsWNkGoxrXOC1ljS47tUG41k535DkKKktu1qBND8y0oyv189goZfPzE/UsJjJz1gwwbsGs+pTBSzwVMxTI+uxh7Nn

oUjtDwwxv2Jzmuu6SwwZVYthYitkY+2RZ1YONGHbkguBESN15EUtMf1DhjBmui54eHek0JIKWCqPgGeCFTGyxlTYSMOIy/bY7MyyC8E5OUPjk+GVkxYjexGUBTR64ikHU7OQtdUODbojdfejNKOjAhdrU1cFC5mvbk/VPPY2rCLmETU4RNIOkhNl8loSrd4onqKYB5Y2RhYkB+MdN24B+oc1G1ITQKiYBoMxKubodmf0msLGOJjQRY3TtNM7EI5N

Bwb9loT20Z9PIqKuv2SmUW5u4K0CvNtNzokGw0L/+X9iZCzU/G1WZ/hF3ENjXkNwRnjC45SFp5MA/VQQIMiJGtteAMLaZArgUD+EZwB4P+vViXhKpIywGs2Ug/h7ouG3Ken4oH3pdOCD+EWsG3Z1N6i7SPcP/5W6NRzZdUeF1MMc+Pf/ndj20rV0KjJco5BR6HM2hveO3uF8hfdhYg+MFD36zYgz0oCOytDEVKF/TIMwq1hj4rnUnDPViF1KNDHh

cDt1RJ0hi8XJotKQyBt1IhtfytgZsCHk6oziRkYw2o47QqO95rWBJO/YUm0puqLRVEyb1ImHZJv9GidHhMk9f9grRt9Bm34h2oAObK3IYeoowW5z2kN1QSc7CunV16gFJSvsbGHYxuprfadph+wdrfRvsRFG6LUd4w5NlC4hMZm1g/w08hYVKpnXQGtwb7RJQG+DSoS53moqgyBsMw1kEJ0KjJ8FrCjcKc3Bs4GDDBW3uu4rQlvfrjNef0QbdocQ

QfVNlL3VYYVgotBfrSqUd1Nzw62MhMNGC2zq9IsK2RiEG9yGKHedLEvfJgwhGWRgGEIS9SM49zRKAamjV1p87PNTQzNDyxC6v7SVBwkD2xoBeHP6wDFA9EHH6Kv3qHEbe9TFt7d0yvA9wg102JiwxxucaPiycA8cOa1xLKNwhTxpXICQdEWcfAlbxk0JGgWJI7FYnnb/KU94fgjYv/GnWgViIj/KcbAD59mixYOZNFCPiDVI+1UGRydK9HF8xqcw

5hjsP+QpVKWClKpUhxE+LpdEWW+LvgmXhwTnDJatlg6uwnNQIDF2W49zVhZboVqMM4r5cZXEVz7FWrH+XOW7YqBUUM4FWhiIVk3Nz0kys3FGwKKC5E0lasc3CoiTCUZWFb7MEVjZSjlqdVYxJW6sFOUG73dEbt90m3KUzbcwnPOV+zWeOlZHc43GlaHcRpk7uo+Du67ubcUXGdwkNeVirwrQSY91z+7N3MEZB7T2xhzo4yXK9w24ZVpNZjGwlDHv

d0ce9Hvd4Se39z2M1VkpjNlFVv9wjOtVunsJhgPNnsWp2O5nv57EPLntF77CWXAZ7ee0DwV7te1XsF7y4nXvF7WrKXut71ex3tN7De4Xs1W9ex3Td7/e23v1Wle8Ptd7Y+1ntd7IPCPTtWwPK1az74PB3S5xYNDjycKXagTyOQAuyTzdq5POvtp0u+1vv77H8Jvu9qxPPBb9WvCufvtsl+7bt9WTPANbX71PA/tX7HdPfs8Kd+xfsv7n+zfvf7LP

F/sf7/+7/uAHnCgAcDIr+8qzv74Bz/vP7IB0/ts80B5zzvMAvDgRC8xPPzxeY0iJlaU8GB4LzYH6a5PRmGWnuwkT0eUEQeKswvIQfysxB4NanbsirCxfcdByNZ30324opVRmigoreY7Bwwc1xbBxoo8Hqinwdw+LB7wdcH/B3YqtqkrBNYtqY1lIcWKEh7IeGK0h6NYN9ch+VafEpimoeTWeiqodKH8h4SyaHeh+oeVKhhzYraHph+2oyHuh2YdW

HErEYfmHkh/Ye2H1ipYcqHdhzYduHLh8ocKH1h64c+H7h34cGHjhx4f+HXh/ocaHwR4EcRHihyEdBHMR1EcmHkR94dxHvh8kfRHqR+EeJH8R2kdZHGR8Yfy4FhzkcFHSR5kfFH2R6UfdoJR/keVH5R9Uc6HAR0Uc1HeRw4e1HLR80fOH41hUf1HYR3UeFHXR30e9HVR20cNH/R0McdHWh+MdOHnh50eDHrR5MexH6RyMd1HrB2IfCHhLCsfqKax5

8QbHOihwfT4qx7oo7H3ByIeCHBx3sfaKxx+seiHmx4cfXHuxwIdaKQh7cenHNx/McJHZR+0fTHEx18dTHoRzMfDHPR+YeuKSw7NYmKwJwr1CqdiuCdVQmVGKzQn7is4pdS01iCewnYJ8icQniJ76puqquwGM1qyqhmpNqWan4r1q21sSfzWuaqSd1q5J2Wolq1J1Wpcsy1ryyF6QilrG2mzJwyfcsTJ2tYcnPLGyfcnS1gsoJKXkPOW1E89EKdJK

XLIKeZUwp8krxK0pxKfMsAO0BgcsmyihYb0yPiQfvs3aUKytxhLAX4susdGOrsq+jLSpcqmSmirQqAiRzZ3KFyr0o7S/Ss0pYs8LHakYsJB9gHosSLD/S3eTyK6GTWBO58yeezijURD0/9LmpEqZpM3Q3MhqPeyWyodGAyzu2iREzveY0HAwYcr9B7E1WaDH7DpnCPi474MfpycxJFSjN+zHMxFiQzoSLDJAhsMTDBEp2xvDCIxeMOzMEz9MPTJM

x2MqPrMxgwQIe2d487YnARWnZVv2oKsVA+wmDnIsMOdjQo53BUox5eKFb5mfRe8DFmiDNOec4s56/T5WeGPBinY65w9ybnacD0rLnu56jT7nTHHTWoce50lCnnG58eeXnr9D6wbIPqES53nX3A+ezwG8Zgz3nmuEUh+nn5wdDfnz526yvn/54gy/nj5++f+M2OxDhhdQZ5BdSQwsTBeGsC2K7DgciDJ1aJcFxGWmv0aF5kRBIup/4zYX9upheoXH

sTheu6WFyReEXeFxEzznAEkaeIMJPKGxrcsiK/QMXZ3LcII7noVWZsXCHFhcq8tF9UcHyvRfxd+nNF7+R0XujKJd9QAl5JfpzvF0JdiX0l3xcKXIl0pdSXKl/JdqX5F71ykXRFxJcUXGF1RfyQBFwZe1nxl7hemX+l+ZdaXFDDpeGXyW9peUXFlw5cmX1l+dC2XTlzZeOXrl71BeXxF85dWXfl55cuXgV25e+Xel/5dkXIVz5fBX4V0FcBXsV6Fc

xXmDGZeRXCV9FfxXyV5ZepXmVxFe6XOV3FfZX+F1ld5XRV7ld2XUXIlcZXpVwVclX1F8VflXMl+JfJXql7JeoXLV01f4X7VwJesXnuDxf0XXF71fMX/VyLzcXQ17ow9XTFxxc8OI14NdTXa8DNeTXgbPNeT0o13NcTX7F0tfrXfV+NfwW4YYeC5QLF7tcC8+16edcKe14sqnXR19yMuSh1+2znXN1/RdXXJLA9c7Xd18dcXXt11cz3XB149dvX11

z9evXX1+9cvXmDGdfA3AN6DdPXJ159ezw4N5dd/Xz1xDf+MYN/9fw3QN6jcw3GHBje/X6N4jdo3sN9jeA3BN3jeY331/jdY3JN/Rdc8w2IxwA4LF9TdXML5AOdFxjN1AP037zDTdM3MZyzfQKdN1Tcc3rN3zfjXDN7zfM3It7Tdi3At6Lfc34t1zfs3xGJzds3/NwreC3ktyrfS38t7aaq3Mt1LcS3Ot+rd63mt4CyG3yt1rca3pt8bdy3Ft4rdC

3oN7LdK3wt7rdW3jtwbfO3dt07cO37t67ee3pqEMXIB1HKOc83Jty7dm3wd+ELlx6PitDR0ft5HeJnbuBHflmUd1Awx3id3HceuSAbHfsJKdyMVp32d5nRZ3CdzncF3Gd6nfF3aPqXfR3hd/neV3Jd0XdG3Nt2reh3bt8jf23tty3ce3bdxExB3zd13et3jd5bc+3vdx3f93Dd/rdN3g956F93Y9wPed38d7XfV3yd1XcB3pN3De9lv9P2VJcKHL

0XwV7RcOrvbcEgXHTeXENQEvWRFXQH7bpFRbwsBW6mtW0QVFXEn7qUdoeojAHAFWCQQd6tcDQQtQDmA5JowLUD0Ad6pgC7AF6rgBCV+NqJVE24lVJq2Ro6p/oLa+CPJU5SfiElCXE1RLBKUaVgUFWWNFK5EvM2vNs4FcCCGatmNe3npMkhg5lQdB4oZLDURxGqQVslK2TlWEE12rlRrbuV2ydrZxB3lXxqJBhydkG3JQwbfyBVD/CFVhV/lc1VKa

DyYUHxVpfL5ZvJyEB8mHbJQGlUZVWVTlV5VBVUVUlVZVRVVVVUgjVXrVUdvVVua+AFCniPMKWQLtBzoB1Vl8K0JDBhQvVZ1XwlkADnacARdsnyh4XMIeDjVdWsynhB01VlqSCeWhSmLVBwctVLUq1RVptVkAP3YTV21cmYj2+1dXCHVWqZ9s3Yv48wQsurTRUuepCCBqwibcnpCTih1YvNowbmi+R1ko/DSz24ySWejXqSpIMtOhrS6AePBN2Egx

TgbUqaRQYdpNRBsaiJaMP1GFXQs1vXDPSKHBdw+09emBo8sFXjhd2iDQgIDSNH/ZL9jrlzoNOBC38gCo/8Ncuj6MKEchrPW4nOWlD2KLZ6zZcSyC3zaLyyabdjbpttMsbWUOMRry2z2Z0IEGa+Z7LtU60JI59ZHc6FTw4q960nwi5DkPTTe6zURe97Ug+JeUxE36JS1U/aaO8mVPU33eZQsClBhjMBATnPQFXQIU4idk+ctxhdUZSywr465zAOIa

E2OGUI9pPP3n6VRJzLeTy2aDChUD6zGO0UxEgJtGzsRpBggDTo5KhCoqiDutLRrpn1Qtb4M3VEcRnzVQUzzFUxoYqkp5oDPDExak/7ijWTjPnfEPT002AETuIvOhrLTih7hdoyJMhBo4fbOQLZ6GK16FoNIst50GTo4IinY6/USs4iXMTRjRYRwukMBFLhr+YrbZ5Kcvrsf3YWgmyDiJ0QItZ5MNPEKLwsC0cw0PBDAJR2CveLzjq2I2heQ647FP

IY94kdBvZMQ4f3hKAjTRhbZq2Z7kZQSZG+RqdTo3vLZUbDaivRkRW//Su5gb2Bg1bnjlagcb7BJPWr56mB85/ahnnqnFYSeuz2trjWB84b6GL+NguGvJ6Q1ZOFSPi2aD9OT/CLK1A2eQojN8N4UTkyKPqhXWLq7ORp6l6ZwOa5IMQAxj9SbmGhZxLT4yN/2apLBOzzWTlK/XTuoy4YuSSXfAsZQpSxGfzTycEOgprXmaWsYO/0KrXhjMaYQ7x9jC

22uxEQ8NJOPtrErggUvzfVQ5ywQbZViCY3CDZh3v9MJnlIumq+GPTGQ4gBLGbIWTyTvrxcHm72IPM0m6Do5wgQsITJrpegMMg0/CKzhdUiq8MTzqNMyobduDhyHLEW1xOlslUEQM+6JuS+0Vpkk3ZGbPnH9WJMiDC2+N96d6/v1fPcb/tC19tWfNiBDuK/MTMy2DCG+7jBerGw6zQ4bCAoyO5Be7FwYhgglpe+vbJh0T8PZa6a9Q4aMbP0iU9kvt

Z9jS8GiT1uPq8NjP65ehGwymy+kbIfSMs+ZjZNsPQ8tqElBh5jpoyhqZNKq1oPOwsvSuSXyB3bORNPDuU61HvbnG13SL2ImTBHoDz6YUPpFeGKId45HByBrLUOQE47vEtdbKnSfn+AXSZ8hK5JCz/Id1DNcQ+FPkaU8FB9DduO2l4MKe8aVagpwbVGZLuCt68XksvguR1JqKO8+x1e6H08cOcwMbNi2YfUYV9Pbw7EiTOYUbSJZY5rvLcrhHG+jV

Mb+YEyCJOCNXcNVil9TLiNgPLA7opu70oL76TiSaGom+BCFmPZC/zq2DOsswTGw7NzIWEbcL5Lxzgu6hLEdWIabYYyxlD3OdGPZ+5uaJpBi0ZhUmGgPiJX2D9AoosID/G1sBCHLuvZEczJZPBoX/r3w+W2e/buWwyiv5dxYadJOyUCwO7FYvUM2i8vPzpqIu0fvYNqrSPz63XT6ESNvPmzcyDxHNfxWc2EIiuYvKu3fikthiGQ5S5j9boAWL5bmD

FkTpjpZVHSTBmvscBa8R1HyKm+j6/og7hJ6HT8JEQL5g8DCle/PSyPuCSv1+84IveU+mnPzgIxOAMY4910GwMrc2/ZSgv3LDBFjHQbpKYQbZL9C/Tv06EWYY/Bl8/RDPwRvMrOS9gT/wgeWD+6Bc69yvFHGcF1kSN+P2iRlvWsr+YDQAc+doF6WaUnlaRQsCGmMfqf5m2VlvEZv1TwtPxqP0/Vjgj+HPKOEyYZ/YP9VY0zqIW/BQEB8ztoeYbF7K

la1P8OQsFfzf+fPFqOL117HkyyJ89/fr6Vb0652OiIOMcAkbj+9SCSAFTh0lW8/ZlY4IhL+8tEOFFCtfYJJIwckNXwB1fSrP/dKsZ7XRG1Si8hQWsNEyO8QHODS3ak/7h2z5oTEzbP06jWiSGRlvGSKp/VMSvqXx+zC/gUti54E1NQoYtZrfN3JDUIjlgG8tXOlgbGrrkZJEP9McmxMb6mU9Y+sbB5FjcsUTIM8/1sM8KEKJBxdFU8P7LOZjlp6J

75M89xBujoQoDyMnevuI3yDo5cHkBJdiOQCZnoY0rrAFt6cHtsPrNcFMig9JyOORMo4od5vtkLpQ9ACACAiEoRCKb0+8EkR54iKRBVAecqEsex7lnAl42HNw3CkiAFECJBTysmQiGEjdEdlGxkdrGxAOFmZUsDBwuYCnR9uPUlIfFvcoKn5Zd7ljs1TrjtrigPQOzunRU7vjs6OAGdGOPMUuzAOYH/PYpBONuZDzABZafGcUEAiCVYSl8UnHhSVJ

SgKUMSjKU0LLz5N/GaVDSrhZjSsf58/F/56/Kr4tfLn56LGH43Sp746ds75cgbb4A/BZwPSp/ogysUCAyr6V/oP6VSCIGUqgcGUG2NxYwyrZwGgaGV1VJxYWgZGVwyh0CeLF0DpmI0C2gXxZugU0D6gX0DWgVrt6ovL8xgb0DJgZ0DmgaMDZgSMCZgT0C5gUsDhgWaxGdnGVkykbAIYGgsfypFwMykpYyyvmUKygrQ6yizt+1I2VAuCPtV1pzsu6

Nzs17jXQN7s8sHgT9066M8C4uH2UTLJvcquEOVasCOU49r8DAxMJtUKnQwJyvzsQQYbQwQdZYfgWhV0mOCCfgYuUcuJSxMuIiDcIMiCEQUPRZyrlwUQZiClytiCMQXGQ8QeiCTyoeVhdhuVSQfZYRdtOVcQUiDbdpuUyQTuUCuEeUqQZm1dysyDyQWyCGQQeVOQZSCOQUyCuQSSCeQeuVGQULteQSKCW6GKDuQfyDJQYKDpQcKCpQaKD5QbKDFQf

uVlQRKClQcqwsuESDbdlqDaQSuUKQRqDfygaDVQcqx6QTKDTQcaDjyhaChQSaCLUrqC0QXSDLQSyDBduqDbQaLsnQS+UauG+ULymqC9ylaCjQTaD/Qe6DAwc6CzQYaDgwXKC3QSUQwwVGDWQZGCgwdGCPQeKC/QaGCkwQqDXQQmC4wSqDMwS6CUwXyDswamCQwfmCMwc6D7QcuUcQYSC9QRWCOqNqC8uGWD8QR3R6wcSDNQaiDywQSCawVWCfgbd

5hysCD1SjqVVSjTt7AXUUM9CwgMmPhVp+KfdQkhfctqmiBr7mwFB7NRVuAmDYIAJ2BEgJIAeALUA4AJ2AhgEIARgOmAHwBeohgOcAI+MHwuQGA81AoTZM+KeBANG9ANGoPJi1MthyWBABS+JIgkyJRgsqCAsWXOpV0grwB/Nrg80QEMl+bGXxr4P6w0XujIyHsnwKHvmg7fNZVaHiFV6HislnKsw91bJvx6HjslOHqUk7NDw9rkkckIqgI8zbD+C

Lkk/xeHuFUTbJFUJHgUEnki7YZHqUFTwMlVPkso9MqpcBsqrlV8qoVViqqVVyqpVUQ7Po8e7IMEOgjgJXNAQAcbGY9E7DFUonlY8aIFKFfzHCxpNC48wtFMFu2H6B5IW48cQOR9sVF0lCAL+AUtD49JqhAAiUsQBMtA3ZtgkE9ZBCE9itB5kkbhAATggY8+7IyldIXE8IALtVZqi1pknil1nquM1NWjEQdCCosFRm7hUagjREjDrhPcH60k3AZhf

8KvJ+5gAkgcDS40Zgi5P7GqRIvjcQ4jB7kXNrNtKGGjB9NjAR2SJJx+DCfZC9Av8ACLcIGYkh149H+DCoU6hiofqpEQvxBWARN4Dtmyk5IGuwZVECgxfoGxLtklRrtkrx62L3FK3rToc2GPFRpjQhr4uXEm6MOc12N4Cflk0gD5OODteCEliKtOC77r48r7uRUb7uwF77mAB4klwFaKugBrgNHw2AH0A71H+B8BJcAhQIQAL1NHwhgC0BCAEIAqw

EcBsAAABNc8EiVdQKQPLPg98MCaRkfs4VQCmCIPCAzY0OCjsEbLgYPc2wmRTbBwNKFy6VICEgaI4yEDcbZ+gUypoAKCGWVah4qIMZgyaOfhsPBh6hBNZIoQzZJYw9CFeVTCFmgbCF+VHIKp2QR7m2IiHUaUR7kwkoD3JSiFxVZ5I0QpKpACBR6NQyACMQ1R6sQjR4cQ7R7cQoFJh2BzS1VQx6CQ+cCVVaFJiQix78QySFUCAPCsyOSETBBSFaEdF

KqQuMBh4IpRLBLATaQyuwOQ9LTEpGaqkpHYJmQwrRLVSyFPgmyF8Qs4ID2GcENaPaqKPG4JuQrEJLtYUxFPG4hTSAlzo9Nr5VCbzYLvMEgOdIFoqzGIhdkeUioxG4jEIaqFBjZ2EbhBohupCJrFPUyDubEmax9RNB8FBqaxfVeRt6PWg4OfrhQOLghs9VfDAtQdz+YfrZTLEIjNYfYAmvEXCk9Fny8DAQoSiN0QBpV/7s/ZH44/T/7RiP7BOYcb6

Mdc37XwXia3PIxiUdGz5aICpAYxAzrRiUnoJ0cFrY4EaCh6a9aQbPpL6qIdommUbpnTHf4sSYWRLUZnp/PGMh+FPtbfCE7BH1S54h4ImgYrJUQrRAbJLeDVjHGQj6tCOsJdrbhwpEeJw3TMHQTTK5rWzN7qDwRMI7hbAwNUdqbDw1iId9foRcLFfqzhaxyivQKDxrPKa2hM8h7INbzWbYJz9SNYQfNGBEMGe8IotVJxWsdMYpfM9DLzVXi9pAdDg

6crIKfVsgXkQYwEtGUK8ib6qFvWtY2IdkLYQT+bBDF2hRIW4yhrMBGFwLpqhoCOQ2LRFa5rW6Q3wfMZA/LeCBIAAYvTWAiecFVqFSGIx0YTMQr/P0RDvEWCfCBYZ/Ye+D3TOn4sSFEbHzWj54ZbAi2oclzZPOhxSISZDSkWLyWNFbQZRRDZbCGnSCuUjZIUaYzwYQz4BeWaaErDUyWNJ6AHvKOFbCCbCh4XYRT5QWwC4bV6P/ExAokNTyCIlDJjI

T759/BZ5oMX1j7rdzqNUeQYKjPvQHIZl4yhPt4XEE+aGjL1I1oF2akI/2CPYOlaafIajlfKfL15UNiIzLlJvgewIYNBdCNodajZpIcJJEJpC9fLgZzKcD5apCGpJQ2/KBoXZy8Io6rNIo74gbDDqcGVLYShOHpv5MQy/QUqHFPLybz9BTArRdzgxbGIS49U3Ay/F/pnbPrqzfFAhlfdNLiRE7DwEV8bSzEuHmILv6yFU3Ay5TxHsoWRabfb4ZNYf

marLWerrPX8KG9VQpFYLeA3sU2Ql/aMTYhIViqhUl60gnbaFiS0STQCT7t/bBgKUEbbRiEaBR9LCbHYXeBevGL5DTJRaYArtA59eT5h5OlrkwW95QZdkyQIaVbx6S6aD/DBGCwW2CWYfqJtjdDCFhJv5N4NfrWfV5ZxQCbDCcJSDNwjTCMIdLIntR/4+uc8LybHsi0kHJx2/X/T+DE6gtIzfpk9QcZkdHvoQRcAYDRB9iOLMBYaGLjx6/N2HMFDK

hmzFfoeYI4zz/GV6d6QwbufMgxGTQS4EIwKCEGDlFaDPVB4MEBKdbLFzLdPRC2IpigTpb3BPvafRDDaWbFYM5ZGokMgt9HfqpGCZycxCb4aYTTAHaDiYCo3bBfGFAarYG9Jc3H+G+UfoxKCOdxPfQCiUNEnpNSaZrAtQWwA8MLwlrHmTdfE7x7faMgVwteFDLP+R59JdaS5YT5NIELZ1UND6/tAd7sZFfDAA69ILuYaiMZSXK+vE85/LNDwBjG7A

j5ERzy9X+B2oy7CfUNuBpPBL4NQKwSq8DpLpwzWgTYA+RT/XXJY5LDhlYclGDo28aKZH/pDfdlgmTFNKMoC/qLkb17RkWDrLYd2ZBwrkJ5kTtjLw+wprYADDriJZaE6aGKMwOcTjYIKBeQHtIhFHMgSRGhDR9ZPKvTaeF3ifTyS8akbudHaDITO8TbkK3IXo62o7fQuZ4eEdZHuQJbhOZEKocU5G1Q1IphJdgGaxRk7aWHWKxA7OhevGqibsAUT3

scOIwcYrTRxFRLOna1hOsfAIA+Z2KCob4BZIR7z2KOHaveFOgexaNgo7PQHy8LqF2A/lKBWQ2jriGoqoBQs4jgxor2A9HbccTHZiYvSyXA8J4A+OCqWAhRhNFaHzeYWHyg+bHaWeTego+XxIkcbopoXTM65iaQH2AvO4Y+QYr6xNhoawbopcKcDCzeazDOAyDiuAzQFczFwE4+NwFjFSegTFTHDE7fHxscL1hDmesyk7Mcwk+JcyF0DcwCcLcwHm

dnZ3mPTou+Q4q/mPYonFAIEcGHjEusRnx3FJ1gPFe1hPFdLHBAwEpwlD4qQlUIH5YkIFIlGEq5YwrEAlG3BglIrFlYkrEIlArG1YjEoRA8Up9Ibkp0lLkqilHkrtYhCxtYnLGVYvLFdYs7idYkUrdY4UrslVrGjYwUpNY3kojYinZRAhUqyldCzIlaIE8+NTgoWRUqLY6UrzYmIGrY5bFKlCAJU7MwF9g+NADgoXwf+IAKF+b/x2lDIG2ldYFDAg

YGRcE4HqWLsGpcP4G9gxsGtghsHKsICq5wmXbRWcKwJwPXZx7bKzncTkDN7HKA97ZfaHWRHg9WUA7AHRA6cKXA6oHfA7CKGRTMHFI5LHIE7onGE6QnH1SBqHxShWGWpPQBayUnQlisnVaz8sRU6ssUAGZwZHFyncGQKnCNSZqFNSw42A7w4v7E67AHHHzasEcuB0EecRcxzmSaxpsSHZ2Ja6xkBWdxZxOBizQ1OyTghaEfWS+6RJDdRrQhcEP3BJ

JP3coBCAU8Y5gd0BCgHgAcAEYBSBTADbAI9QPQ/ARDAZgAlgZ6Ep8CB5Xg5YBs2T4ATwCBBQ4FmCKYkoAvgsCZssA7S8IZhHfg6wKC2FlC1vDnpQw//iESNxai2RGGoAZGFUPJMRow2yq38BCGMPXGGRBVh4OVaAAcPImEJBA5I4Qvh54Q3kAEQ85KZBEiFiPciH22AsBSPZmFu2OR56aBiHpVJiEsQ9R7sQrR5cQ3R5DgIWGtBK2F1VMWF4CfQB

NVciHmPEWHtVBFJLQLGS8CZSFKw8EBnAVWFDVGwI5ZWyjQgbx7y4qap12Q2GBPclImw/YIWQmfwWwulKgpaJ72QhfFOQhJ4Owg6rVwdrQr1BkJ3yL5Af4eD45pJkjGvY9Z1PRm41rGmpSVNlYVrChDTUBHCRvJUKTQN150bQai8uaqbdtTGjvPAAhCERjAmvVrZo5VNyvdB7Cw3Gd4JtQKJNteDHuYeeQ2wDYalbLDIh6WxEY1fY6k4ETZ0dKDDw

4bRHGRTUTCkfeEphCiTOzf1EmISaA1WZWYDuP7Da+KhpduI4QVIlMJISfvJUrPnr30CHC45Ojo6OHUaC1MIg7AyjavNWvD3ILn6akZGYb5QjL8EqggIGQtCZ5fRFm/FGDyEgTLswM5C0GBmZyEidzvpLhCBjHt5RhQowAAu5x2RYCghrCTqUEnJH+o2Vw7iQHB8EigmkoNigoovWB5EGNjX9ZjYn1YRHrpNZF6wO3T5SA7RvouVr7jbiTAbczAmp

apYho2OG1EA2ZQZFnKpQUFHewsliWo8Lp7AU6SK9VrZ9UPtruTIOAKQVFAGvfWo10dWZlPbLKQOSxEZtfSDCcQ8bnjLoTYLIAmVE7CijokuBHIWKFbI8/4Pndgijo0myrvfWoNIB9G1PBCK0YWqDWReonfkDD7NhFuAOYQWZFojhDyQDlj8ZV5EfUPFqXFStEphb6R1vBCImyR1EcNOjoAKEF4UAttrsOMgi4Fe1pCNGyiPVDeDrhDZTtI/jpOle

iZttELCGKR7IzE64Q+5GyKTbBeQXrSupvEzeajGXCikoVXoUExJDWExjpRRRhhh0DtFeEiLA+EgBGhETTAuuFd5REueR7Euhq1kQkASlClrodJDIK/Udzg5IHqmLeTqDGDYlLRIyZucFmZJE69CWLaNpWGT8LcbCNpZEltrAtGBBlkMkiiIj2rzEkDF31PuFxpK/77teuDQEwb6+WBqi5ZfX6tbPokU2DSaKIFGCGVRrKP/FjyHCRH6kLYCQA4aN

H8ddYnuTQaIVQS7JykzAkwk71pXwBWDaYeOEEEpwlZw0dzOEfKjyo3f5WE96aMdbSJFeHBGKSP7DAk20kGhTeCJwAij2vdgm29LSLtENgjMol+E9ycMgGjA6ajGOjBZQujqThRljKohCLy0TIhT2IIm7/GEQDEkGix6C6KtjVf4R0VokTE/2SOIBp44NTvCSSL9ztZSz4lYLzxm/YjKQ4beGPtRSbj8FiZ2NU6QGIKuF/jVMLlrf97ZSPxBuwILp

vjdkyTLOKEdkj1zpZG7oJjAo4BsAgF3hNEwE5UlZnZFaKM2ftw/RD3SgydbLY6EDQEQaHgEfBcko1LrqBwebAS4sxqQoxSQZIQ1by6VpIq1ORHluIWJlGTr6dYDZpKYSF6NSNCQMzQOBXOfckSNa4y9rFqYRDC8hBeduEC/fwjVEj1DaDJ3Btksjq/RWTrY6TCiYKQwxfE2KJ1yLGruUTCgQmImrmta6ISlG/rIZHRGWWWkiAow6LAST2L6/aMg2

IMGCeLdwSRzNLA2GYsj6wQgbnk3CnKvFwmOwZ9FSo6frdRQAjR44lFXfP+zLYOdGgU2whsUt/F2dOyLKrCikoNA6ghbdzpxMSKHrwxSS8Urjb8Ut9AijP+AgUiOp/oK4bropvjfAEHIKvbdwqUkua5DE1wJvdslRhMilbovVyM9BAG/k7KTRYWwqhE+4mSwe8JO4MYajRfmY+k1bC0YSMjWrE9FgUv95npdkyGKY8kqTfKLlIaagXE4Ibldfz4Pk

8MgAU0vI9UZdCfNCyKEIPujqEyWDRg5P45ffSIViQVAgEjTBWCVBhKIgKlj6T+xzMBbZlQdKgZ+KAGgUrYYDbIn6fdN77/ILrAKkUdLhdItAuwWAFg/XIyEFAdBF5CMmduLcksozMJpoflFm/fVLMIuuHeuZxqYIVqnQoKNwBUQuYFdFiiEeR0kDk/6ABTTH6HkP6CmorZr2YLqT8bShFYRdCnjw3yTvuVFiXwhdDIUBZyRNUrAfzf1GDoF5hbPB

sLFoKHDF/StL91Bl4WtKMkkUwhEGwdFG3tbwl/QXwkToPPJDwTjpm/FbhHITonAtKrrmoT5C6tJVLvkGJaMI5fKrQcuqGE6GqgIDewV/a1GDIS2o7Ey7pWcWPKsLKtItmVgZ+bIebK/fexu4BGTQYmIRLYfVCStMqCUEA3JVvLVz3ENijjkgdCW4JtDjkwoQDqQDH004ODQcPZbhfIVCb5ZdY5TALAmQWpqEmKyCJwfMk4IJMgRmZ+RNQeGRPjHX

5JSbBEIfEGh1fSH7BOTNyVY1YkhEZ3SuoQuFwOcXqocYD71w0zaXfRgbDYHjhLIvia5KIpAfw30L7jIVBTjU542yLWA/VPobuQUMjabTT63rRqktuUkgnkbMmafeNw6mcxoZuLeBGmUQnFyJORSEFT5CE53KvhO3oaoldBsbJOlR6dWklpYrAv6NuZlIN8EtjA6n66PvTmEQyhyUn2knYMOp5wqPCEGR87FLQtBZFEYgcvO3ouGdCQCeSOmMkZyk

lQmqG+4aMrfwmpEToDnBJQT5YnoxdC54dsRM/emD7pBSDNtI1Z16CdIGoT6rCDD7AesGGnx6fDKNEiGmlLcEak/IfR6iMfAp071x74F6iV9OvRqfB5CANZ6mqbQVw4rMPKkwN0R4E8HokwCzB2ze8njpBdwnvNzoCOEPBwEBhEwU8dIt5czHDk71weYE2AyePVGboCZwnmQJFxhELA7wL6I9E+EShka9EN0uam/4EpH30h/osIEwnT6SpB9zKSm9

vJexsUBpZNU0fjywFyk0YeXAqcXiifk3pzFoRxjBzbBSSoM+ASkztLy0WthsZXNboiPBR00odJDUGT7YKRIp8IDAYJFMKLPLIRa1rP0k4DPNFlQS+QK0fmSQksgxSICJBAkW5G8iXeDrEXunrORBokLcZy46V1AovGfrEEcMwamItBLkwvoKGM6kM2fOn6M5T61bQciupW8IDoeZaAhVJGnPWFoScRc7wTEqk3CAuY+rWd7JYUBRZQxwaZwUdY4U

sgyQFbvCHvbKkHiKDC9fX1ZLtYtRSLVhZLOMPC64VeaJMmKjDdA5wViCjDu4RankyOpFSiRb7vOGdGCdSQnYKLrA8oJNFa1fVw2MbIhfIlt7FM3SIebNVzBwfoSe/UhSoY/bboYi9gVXBmxrCOWA9sd7wUMvgyPoF+ImnN+LgXF1gbAtMqNg2EFWWE3byY6tIpQAKxK7afAq7ZqzO7cc7wyMHFl7AfYVWGfac2JfaQHDfZk8I/YMHEXjkHcXgPHT

g6vHH44LHSpQxqIk5xKRk58nCnF30ObzKnEnGfEb5mbo5HE2AthotYHaypKVHQ1QAnEdnPawQs8ehanV7RkEaVT6nQkCGnOo5IsnjgmwbQ56+AVRMsD5T0sPBRSAvlS70fFk4szJR4spNIksz4hYs4lk44ylk8qNlTkqE06cqJlQ0qJln0qDlSkqZll0ss060s9lmMqNlmMsjln8sllSCs407Csvlmis7JTishllis3lTSsyVmys7lS8shVmZKLl

mcspVn0sxVkCsqVm4s/lTUsxE4sskVlys007Msi075kFFTmnMFToqAFSWsy063Kc5S7KM5SPKE5TvKQlivKZ1l2sp1n3KR1k0uL1kvKG04Osv1n2s55Sus/1nBsiljjKYZRzKMZTbAyNnWweZQRs2ZRxs6NkLyRNnFKaZQJst4hJs9Nkxs1NlkY8Nk5szNlpsl5QZskZTxsgtmls5NmcyXNllslNmFsvNmVKGZR1smtlVsptmVsiZRZs4tnlsqNn

Zs2tkVsntktsvtmds3tndsodkDskdmusktnjs/NnDsjtkTsrtmzs6dljshdkNsydnLs/JSrsotlzsmdmbsxdntsndkrs+dn7s9dmHs+tnHs7dmns7HIns5tl7si9n8yK9lts2NlHsy9nns69mPs29mNswdlbspdlPsu9kvsh5Q+s207es65SAcwNmeskDkWsuFS2s2FTH0KDmIqG1lmsq06TYeDnfKaDlAqBDnWsyDnociVnGsoVnysjVkqs9Vnc

sypQGs7VkEcrVnKsnlnkc/DmUcmVnUc4jmqs3Dk4c7Dmss5jmGszVm0cojk75Bjmsc0jk0cvDmcc4lSEctVlUcgTnMqfjnCcjjkSc8TmMcljlGs2Tnsc6Tk8cijn0coTkyctjlkcyTlqc3jkqckTlScpjlyc9Tl8c/TkKc4zkacxTkGc7Tlcc1TlKcujlWc3Tlac5Tl2czTk2c0TkkcxzmCc+zkucvTnycszmmcozk+cylmmslDnoHZA6YHXniS7

dyw/YrY5D+JIFX+CNjDgoD6iY01BnWA7jhcNBig4yugn3eaHn3OXG2wlaGK4+cFbVRcE7QiADXAFsC1AIUAwAHMDMANKpQAYPjB8TQB+8CgC2gDgBHqZIC42YSpW416E24yACAaOuBfScmBXAyqR0CF8EcgdiJWYYTB6BMbg+4oKpKFMtC7cQBZB4pgQ0iZlD9zCCFmVG0aUPGCE0PdGF2VePE4w5jRJ41CEEwtPG62Hyq0w/h654t0BCPDIIiPQ

vF0wyAAMwmKpl46iEV4soJswioIcw1Ko147mH14zR6cQnR48Q1vEgpSx7R2ISH6AUx694qWH94gQDWPJ5AWUUE6RaMfFMCF1nOPJWFqwsvgX9W0y/kefF5cxUD+PYyGFgY2F7BeQShPc2ERPGHnWQvfF48+J72wjmHH4kwQxdZ5A2CNpkxpcZA2ZYuQYdS37/UjwTDxV0kppGkTBTVhYseLyDdUt9yUk5JbIkolwKkfuFZOfmYbEH8mk6QXnC02Q

lS055qFFTukY0SSCJU9RHqYHqIIjDqnqSXqBRItXrbQVpaTzcjpkkQjonomsSlvQn6TESMZj/Vul1MdUbj9bTDmUlMZYZSuGB0xZx8tREydDO3BbDX/G2Ut5E+wewYAMsgyjtTkwGTAdrPtRc68fcAwRpAqEyvFbn9OBF6GvezBLoyUlnPQFYoUgiTy9bHEHErDBSYe7TmbMDwcbZ6gmInbq+vNf7evJig7EAsw+8y9y14W5h18l4xYUAiAc8wtB

gMmjL4E6ZZf0bnmwk5qnvIBIZFzbL7pGWElpM+yLTk4LBuyK9B21XXJhoXfTV6C7q+UeNzf03fBYkDqIgMtkxXrWxmuEkPBjwwMmdYdfkFbczDXSDJGCvXyhz8136wbdzC36WoYHk4ZYsZTyGsLEYZG0hxnTLI2AWEKKENQP1KLcWNbw5FGRUOcVFQ5Upx+1WqnYPRvnH5TrAIZE5GPIj/rXwcTaj8mD7sRQtH0rfuAD8tUQamPcYgUAXh9IxJy2

bepDxwwybXYCrbz0rJyq0Ceg5bSrDzLQhyNUI/5ZOeO6w1GOFZZTNwYFd+nwiIXKgLVhZPtEmQGUlMaEjIqYlE5LzQUgxG/6SghmrGb7NhEuDwoSxlO6F3kQjZbL4DF7zhU5TwhYclqkM4sh7jNrBNccgk8bA2Dc9dJ6DZOL6HyEd5bCEohbfe0ZTvRxEfie+RZISFaBwTpzw0iPkYUKoSFWL/G6oPlqhQsqFksJmCXvBCn4eAUTYCktICdWRFCj

P3HpZFhYSNAo4Vo7z7sweZYHpUUmr/cKKxeaH6nsaIaeUszrKTQbw+jNrDTDHbR1IEFGJrTqkgQlJTF0qMIxkVDDOE9dEIiCaDCCiymVCjmzQhKJEr0k0TVQSL64RRLgc0Z+nW06SohC15p25UXnGC4vmCuF3KJkwIQq5FyJeQw0KhKHXRqCvH48kc6QxknhpazSBTp8l6Rg4boUNfFBY8OKyagU7xEtCj1FttIWwOkjWlaIaUyGkUPSwk7LBTwd

aho6BsmdtHfmBwEPCyYCGGlbA+wMEHJkoE/BA4kRgVN1ZboVQBPnx4RroIkEEbtafew8kSNKYvMpr5C3VYPYXRBpwxoXbIq9CFcO/kAEcmCKdQhloAyIR01eIWc9N2qQMx1C+6SjDeM2bpBQW0yLxOjaVEA3wGEuBzBwKsYx/MOko1XghJUgAjvwQL5vvdQU2jBciDU9vpUUNRFNM/XS1k5kBhEpTFGkm55IohmJtLcVJnYRJGafUMhlpNDCsCpD

yO8oVJ9eC75F8mIiBUHRwICv0SFGZcT5PBoj+IfBrH8kmDxublBxIkGRd0Sam+4c9CaJRprtSfoWsIrPSd6T6Sg/XURjCvzyxebXpuIezYnTL6gokR0K//FGR2kWplZ6JKIjkCBHtSWdBUE2TJ1Q9IoOwjgEz0Rg4SKUXEvnORYTqYdRFxSNBUEC9nucdGBEBajgsgweLS0EKBWnG+K70O+KY4c7w2qK7wzM1QEF+NuDIMRzFHEYTGJclC5Y7VMW

o4yRSY+f04uY1sXiY7syrYqbHVA+UiVAlkGgcR4FfA94HvYmkG842XaUsZCoK7aKwaMc3bxWE7je7HKwXcXvYt7CHHKsTqzQ45HjwHbhRs4lg78KHsV7Aj44Y4h1SA4bE4E4rE5BqB8UknWnHvM8nG3ssnF8sD8VSnenH/4SQVU4n5mAspU4As1U7JMdU4gs5lhgS2wGvbQlhQs8FnpZUFnjIaFkIS5li7WeCUv0VCVgsuXQYSr5loS7CWQsvCXp

KRCUCRdCUESrCVESzCVIS0iXESwsz4SmiXISnCWwSwiX7WeiXUSyiUkSuiXsS2iUUS3CXkSliVcShiVkSqiWcS3iXCSniVMSviUwsgSVsS0SUcS8SV/M5iVSS2SXcS/iXKSwSWsSkSWwSqCXAsreiQSrJjgS3SVfM7SWaYkg5AskyWr0YyUanCyX6S6CWmSyyUQSoyU2SnSUwSv5n2SwyUSSsSWqSjyVySryUKSySUoStSUyS7yUqSpSXBS9SXSS

zSV+SzyWhSz4hws8ZAIs2FlicbU4JSiKXySzlJTqGXE5c+qH74tdQFcyiq7qFXHbQtXESAMKBHqZgANgS4DR8F0BCgEsAtgS4DEAO9R+8DYBNAMrkSgDrngPbrmaBEZJSwO0gPIFmCYILpKjcrtJ2kShjywRsozcnEBHzFcYW8QCE4gWVbSowfhTJJGGbc6CFWVHbmx46jT7clWyHcjZJsaHfjsPWILp487n3cy7kYwtIL54u7lZ40iF22aKql4q

iHFBWR7vc95KfcrSDfclR7MQtR5sQ/7n8w5vF8aYHmU8sHniwkSFQ81qo742WESVGbJZuBx5TBROKj40LQY86qFLcSmC48paF6QgyFGQ2arE8ylJmwzfEU82yG74zaqoyxyHOQ0lKuQk/F3uW2AuCxjpMkPvjyjIpEhSd+oh8ypTNEc2mc81DjWQaZHxULBiEOL8Z+bRpAMdTH5VCX2p3pMqGtQ+QhMyrhCbfdCWEfR2qYwcZ5N4dFAPBOkmw9FB

gP/PFxfUJZ6eEsgwgxSjDwU8MYO4y85KMjQzzUx3rhdFwylhYbCjUwAHYMbsrXkvl5okeOBgrFt7N4FaC39QWo4GfGkkjLp7pkllH29diQZ6cok2TKgityNpkgwbuhxUzp7pwONqquOlqVwzWAAAwoRD9Ab6UInuYvNOAE/jUdGkwMGSr849Ie9R2VNUwQy/rR6oQKW+lWy0NAutIka4bKCRyEEP6HImVyuBbdAD6cQW7YRERufDnJeoZyLzDfKl

yfSonsUi2YpeEiLnCwbDuCq1GOwfka8iid409ZkDbwav6BwGMjiFMHqByxVzso4SlSZJqTLIROHhzBkhr6R9DKE2uqSoaqCnvZEWb9XAggZUCZ4fJBlXIgPqHgVDakChFDrSDHJASFCgZM/1GfUNtxxzJ/l/yECHKi8ArGzIzCyklNLlDIuny6IWj/YTpYfSSoSd9UaYzC98C5jbCIioI4CVCFmAIIFulaRAvSbEeLbUiwdE6IXqD4iYFraRALrD

yOuWVCKjiulRIwBRWyia7aLKVCemL9PUdz4bIEhiCxOF4eIjC/4JuUGhdEkZ2OFDBixBU/pFTi9C4oCDRIRANM0Jy8Kg2kHiNGCg/S+CTSBQhVDcRULIIAqxeGBA408RW4MfFFgoKuiWdaBwv86/E9ueKAEyHiYEk6nQsURJRc2WLzGBeBWjfMXolUI0XGtLoQSbMKFNI3VEabSSoBUUUiTy03li0W/llPTYhjyddZy9FfDG092VVZAlx5Q/Z5XC

7AnOLBGakdO3q51EKEhU5xD24T5jqK/Xoc6RLawDQ6iPfSojEKV+RuyrxZ5ufYlWK/XRXOA/AmfN/JjcgDjTvW9GuyDmz4k8xVjcwEjaiJEkjIQAjHCzBoKU2fL8/YpUXkGOmi1fTCeGQFpi8wsScoIv66ffTCleDojWSIkXRiBmCJ0WRDRipxxWCQELVK4ZUsEGN4KYHSDl4OBYlpe3Dd4CDFEFZ+CvkJ/HYTeZpXU535VdTgo3E5Tz6EquUKYW

jDpOe5AqK1ZUqY2EZr2BEQKeF6qFMxOTzaOD5sZBTCwdPGaEFITxeWGhHBUHERIRLCbAqxzi4DGeykwO1BCxFD5suU7CNddEXuQDRnP0XpbNK9UL2YQHCC00lrhGLOIS0tKFS6DZxSqJKaQIkSA3GYmnQTFGrEIX34CYM0wO4OelmiixrF9UPZn/e6AHLTN5R4IcjfyB+HaQDmCko6QWafQkat83/kiNawTakgXnTGel4xysNARCdt4iqsmAjEmF

pzNfNDmOL57zy5JnyyrxwLZVRD5pasRLhBOm1bLxwLuPQKTRLOS9IVFCDIzlW2EKh7mC1XTimV4ja/SBFP6TODdk1On+YL9AnPGeyyucbrrbVAGqwDzCeY3ZHhpL1B4YR9HViScjDof5w6vdmyAoR5CJrGvCPEmyDwizmo0iHBj+UsKGFNDxAkvGVb24ETDLoxYR2EAMkwDfWCYbQsQSEQ2Wjy3XDN8JJaoIwsTlSasiHDYFqKkWolu/IjZ8taaW

c1Fv7MUgwUs4aWr78ljD3hIVBpU3bY9MtgEZFZqHHsVqEOQQNijM9ihqEfFAEBQVhFiohAo+NjE6A7TB6Ai7zQcTshGA+HzEcLoormfRRrmELE3FTLHM+bLH5lA4GFlMIGJgosGQVFooKY2Co7MjKzjcIfZT7FnEIHZniUHMg7UHCg6PM947/6NNT4nN5mcnD5m3s/5kipVU6KSgKV6nPeLIswFB1HKlnksmlk6c5zlAct5QesgDkBsr9k3soRT0

JB06GYz4hHq9JzlKEpTpsGpQUap079qF06enWjVosRFhHGCFggsEBIUSRiW/MXTiA+K9B2XcOC/0HjWAsCFjcag1C8a6VR/MQTXDYL07AcH05f0P07OxWTW8oaTXv0RTXf0RBgKaz+hKa9TXenTTVqa3Rgaa1DBaa/TU6awzV6azBgGa307Kaj+ima+TX2YgcXoas5B2ahjjfMH+hOaonZBnZzHOahzVpOOhgOY7zX9irzUeatzWBnVzW+a+zVBa

sLWBa0LXY+KLXqa4LWMcCLUxa9zXRau9jhalLWE7ELVxayLXJarLVJazLX6a+LUua3LWpa2LUFa7LX5a8zWFa/zWeanLVlavLUJa9LV+axLUla2rWVa8rUNa4rUZajrV1alrUVah5hVa5rVdaorU9aobXVagbWNatLWdaprUTa0rVta+rXDaubW9a7rWLa0bWDa6bVTaybUja9bVbazbVtaDKXZc96zZSmnlSAOcH5SwGyFSmirFS9AAPQqsDOAI

YC4AEYCEAbYAtgSQBDATAC7gvoAtgaPiQQHgDMAL9R+gcpJdcy8FdStYCkwS6B2wCWlCcQaU4gVEwroCqSGGPUolATB498SMXLscMKYBLpL4PPSp11KeFMRWgSLS8h50PLGGIQph6KgFh7HclPGEws7ncPTPFkw06V2VG7mxVCmE0wk6U54iABPcu6VMw17mvJJ6XyPF6XsQCAAAAKTgAzgHwApAHoAcAGTA+AGwAd6mj4IwGj4D4EwATQHwE8fF

+lp4F4hEkMBlXeJMeCdlBllj2GC6sMKgEMSfB8kJGC/VRUhU+K2V0iGh2pQB1hKwVie+sMMhJKRXx81WCepsK7enMmmodAkthEkJieesLthLkPHQHKT4gR1ULCEZHOwuwnPME6CsgeiHSiUjCdYJkAhFLaCIQDCL/pxfFAwz9AnmzXDxMZLHuC18gQw/QmEwhIBeFMP2bitKDwISIQMQCPH1QfSCTwshTeImsHbI+vnhweeuQYf8EL1der8wl3gL

mfUSJcPACT1KmFtIBqDyc6eqD+B5jgQ+LH1Qh0AH1QYgWWaeoi47kGcakTh9gaiEcwtISqoVHGDS1dE1YXdN5+BLnuqCND5qGUJNEQSCWoc7ABp6BXhwV2hbwGwEqRyyFTgi516aO+t5EkQjGSK8GRVuwA7wsmDKwi8VN6jiHLlE8BHIGlNngKiA7wTVGSQkkl+g5+tiGdFj/gnBnZAsWxxioelmY+bFR5b6GLchcBrQoXAcMxTzKINYPcVnUlDQ

6VDwCHwVIItKA7wHBGxJoCAdIFSkdgWW3SYSelLCNUA7waWHxeDDGoY5JT1ychDJwZLAWU1wBPs0aBI27ZBEQ0nWDgByE3OUoVCwJ9kPsjGFNwyMTCBDUFYwmau0s50AzwJ9kgUBimCgvkAX1IGkWoHyzic4GBPswUDHIRsHSy7yHCYTWDV0p3hdgWVE5AJ9lhyrFAO4X8PrZH1CdM6GGXgedCCQJ9n8FmcEfwVMG4SH1GawM9GIFAHCMgJ9kUgU

kEEsKmJ31sCsqxWlArwl2i4w+0GeaMaoYKzrC5Cn2VeIlwjycXIC4wY+EiyIKKzYE+OgQeyA+ESeDfAA7H71/7lQ6+UlJANfGgQeLRUQwMIFw6wG5pCWgYoZaAci5+rlgOEjfIo3BbQVRtQkyvjOwJWEP0O+o/AOiGZAzKCMIdkC4IN2FY4H7C+igIGMQYhhhkOjlbytwCAkwUEqQp+GXstBtxAVRBXg9eEcKOECQVB2mUB3HnoICmAlE/gqEQJu

Gtg/Br4VjGAwIOjnRCXjhgix0VRQdcAOALCpbaL5AB+XKAsNJOCagSGNncddCeRFMFaWRjSi64aVrwS8RwYriBuApvN3ggODGSh6XGN1qHhkRpNxADxqM+alg6GpCoxNJqRyhOlAmitclLQH+CZuI5HDSMDloie7A7gt+vDkp0gdwtJCKaHRDIw7dXsQreFfgfQEtVLpFU8mcJtw4xvhGA0Fniz9B6wlqoCJAuB0oWBu6N0mTdSUkCyEoSkGNlav

paE1NHIPmENEZGGQexsHhkzyEmoDniEwUkFYo7WFhlI3XxWAOFf1o7FONtdNA0+RHvgLUjMsEBTWwT8XOkDSAYIfXhawOsH2wgIW1N7ERAoEcGLyV0AMyNowsxgKHFynGriaZplJAvgQGNjxv1F4JFGwhAw4inq1iMhNGZQLaCJAbY1FCPaFJ84NHDYLGHYMUBsIQFFDOAuoiZAguDNWmsEXO4aQ8WpNWAplLE/1vuAIm4q0cQ4WBZA4aREGW60V

IQOBtNfogL0eDC1gYtFgmKbHugaRlcQHDnzWsIHPhp23vgQrAJWpqpp+AnBXk8pHPh+AIEJ1kik1kCJsQRahsY6Jl+Aa5tJws8E6Il9FRa7yNSwwFDPMTZqUcEXwA47qIPABZuoaaTwH5/iVNgh5tsoTXGqyo+qccQa2VwrBFtItpnPh59nkozKFhM+mDzcKmAYI0bAKgM5r9Yc5qONmgNlCFYXSypnmRVKpvHS4LgbI5qHRQthVOiDMCVwKWELI

S3HLNwsDXW1ZuT8kUQL0/CuOJdUkuAbY2RZd1AJkCIXP19uMhwVzAh1edESAB8JSgHiAb6VkzXqis1QcZ5TotvuFUJXWTQwEOBwgY8FDIYJoTgUrGl4TH0uGmVGNYV1iewY8HtwSekTo5AWnwfXj76hpH2QB3ALNpkAvICShdQCUHQtcmVgISf28IeDErhlWCK2p+FuwOlFp0NeBEWEdGkgvaGMOTHUCi/9Hi2imWEwDniJYfRDyyHCnRGPsIZsG

fioQvJqjwVFqVo/2iJcfgN9ImeVHYv0GGoONEtVoowzwTuFFFtBtaMPBAKIOWU6JQngIgPqFsKvGAKg7nTbMTPgYRrBFrkTRH1Q2wuqsqQ3sMQUXVid4trkLtBIwgriMwFhsYMrfPMJdMjsN+z0IowJOXEWhAsNGjLPsnmMW4SJq3EjCi7IQyG4QhaHaiC8Qw4lHCKgTyNsobrwEB0iXNFP8CeQsMwjQ05p/SKRAhImRH8FnBv9EzzQ12I1Ca4s1

vEVf3m5aoV2OAwMAlEMugEig60ZNdgpFo/XGlQC2kfN2GDAQHwk/CERCAky3lJQnbSwYo0C8c20EGZNiwEifZuPSw2DUgZpAxg4kCoK22zG4fCHRIicpCW7cDFG92NCIHfXOg+nWtw74Cok5RqPQnglPiGNSWKrkjRwKhr7S4DKow99DQwgFJYoQHCr1ASCGMHeB24prRsg4lGgNxuD4MYfQgQFhGvNKXS5gNUHjlBGQOABXkFQvKGQVe2gstIXU

zgqFiRyEWAR2lkHVYVNWltZWCPArW0yhRfBqwzzV2tshEuI28GpQb5G1gIlsrqrXTvNx0VROOTSKQaXRxoxYro6jnGeWqDEYYQMIloO3ymgplhI6TkhwYmAWdVzUGNY1cN0RL3mMIxhBVtSzT5Etplm8w0J9Bx8AkIk0AWQr+s7IgjTDoHQwW4ogz2BBVOZwH4EXoVYX2Au4XQw4TVYIyKoUNv0RsgOA3jMlGUJAu4Wg475CNgccA5oIuBUpKWE3

y5SCuYU1NgIVKnmuRjFoNehg+wakAByokEwU/doHMOlA5o1LBmZ/yAFQtOlZaocUigqEU9iZ7A4RDuALNzgFGM+cQYUoeGMR/dudVkWT0aYMEdMK+H4aPIVUZXFp6p5xLZy6WXdMFhtB1KMghgWTFSg/wF3CfVAjo6UQBC7OFF+d+MwUsEhUgu4Rztfwipwoezmo07nCgNttwopbBQxT1jSKisS0gHAKe8gqCFw/VGYUqsVngEdAhgR7F7iRCEIG

gVE1iVyhvYjSDrgFsQ0YVsX1EzCjQSGDpmhw6loxiuGytFFssg6FTbYXsVCgk1lTVDjHu24pVjiy2DV4UjDNNF2zOu6WBckiCBzYpigfNI0pXVkvDXVJAVTYg0PAsWuxXicdDXiVDkFxWLOrFdl128yn2a4B3mYSiiVO86iWwClGLwC8CQu8JZviZk1iA4t3lA4D3hoxigML121PjYkPGba9pBkwb3iYxEOBYxAPlh2vjtnYb3ibFFsqlYj3hCdG

gNB8agObFthvCdGG1CdrYvhIR9BidYTv8dETpbFUTvSdsTrSd8TsidcTuSdCTsyduToyd+TpfgKTsSd0TsKdpTpqZeTpydBTtqdTRUqdDTvsBTTpKddTrKdVTvadNTradjTqydqTt6dxTuydAzvqdPTpadfToqdpRU+8CFBKKunDKKX3n8dkzrRF0zoWdszqmdFRRWdv9DmdyzqaKm6qm5SslYxSOz2dqOx2dhzsYk+zoB8uzrOdxzvsBKXJngq0

CusrGOx2F1hlgoVjqKCvD+8KPkLO7zpu2APi+d3GM+dVRQc6IPkqKQPiBdgmN+dgLoExvCBBdJdGqK0Lt+du6rJ47BBUgEHERdhgJRdCLofoe6uRdO6qxdSLtg4qLrxd6LsA4CXIaKnYqHB7YrJdtTBNtudBEx5Lv5SpLoCU1LsZdo4KEx4rDpdzLspdTLrZdtLo7FnLvZdfLp5dlLA5dqAWDY4YkwCorq+4bOTDYkrrdY0roldAPjQC8rtGKTRS

Vd4rpVdQ4LFdGAQ1dDLq1dYoxo4aru1dBrr1dMrsVdJroVdTRSHFngNB8JgIF8iOv5SymIj2z3Hh8ZkuR8iAXLuOd0rM4xW5gnmJPVSVDPV+u1b0apBEBsXXnKtzpTiIngy5uGLodcloYdx9321tAUO1DASJls4NWhhXKJlxXKu1EAESAzgAehQwHwEPAD94guqgAQoBbAwgT4qZIGYAmgBLAmACFAluNDsnUqgeClTB1h4FUt9xGKKfoBkec5DM

4ipttGE0rjAsCvaEu5DiYZVAAhfNjUhFYhENy9QfEtCXW5SMKJ1KeJJ1ieN2laENO5eyRp1vlSNs9OsphP4IQ0dlQu5bOo51jthKARQQSqj0rohH3JSqwutF14usl1FoBl1cuoV1SupV1CfCB5I4GFh+MtKARjxHAEsNEheuplhBupsewOnzIJuuR5qAEIGk+MxSOIAiQSbBpZtuv4E9uv916wSXxAT0bspkJJ5rdg912XAdweMvbxDKUJlawR2q

h+Pp5ST3JlKTwHYpIHbdZLAFEWBFEwHGArwZVBHgE9lGmuKB0wPFAZAx2H205hFGgiCCyorW2oOU0AMx08pBCYsHDty1TDocdpHapcAjgfRFNtiZ1ZR+KEc42dSXpuUEyJI/JfIjPGEkBZqHIVsQYcgXGRAdHSQQxBgVgEGE8gaZF5FDlP/Q0tF5tWcS/EYCCW4MrnxAUFsBwUBCa4hQjyJgNDTS+XyUof8FlgCHEQIX1u3lJrhe8CWhPIEtKj1X

YkAKB+CJVV1lN59cRG+twk+Ab1Rn8fUDxQ+fGTVK0TitUcp5GWBDlgo0yaIZmzJAilueWSHIS0p+BI1/jAbqj7CMwY0G4teKFwgP9tWcNxBqM++ux+YWDEVdelcGicPRCOsGkQ7sMfC5MAsoMbAFE3DNHIxCjMQH9Cj1OOBZMJnmBIo2BowXCCtgwho/mUxWNFSDUcgukFwgcKEcZPHCEwOwg2II9oRMWsDqwZZgBwChngZ08sHg+kHk9lOBWgPq

Erh8Mi1gdTk7wtpH0Q3wBZQMwgqk5aGfovKAlNHrySZdsFWyw1DGqDRAUgB3EjIAyBaWDrwkWx4HLQySDxQgOjRyqkkbIWQltta7wvIyHi9wzjC1touBGKHLkoGsiESZZVCLqeBD7IC+pkk83VagWSHBejjI6oFAVOBkCBzEB4E0NkaDfIxjNqwAkUgtFxnP1GNC/YgWCwgdY2h9RSHrwjgg4YPEj9toCG2k1zF7QxIAKM82hyKbiDSwuZlt0bLz

LQSGQqgtkCYoeCFWyneSN1UbsjcZNg7Ygw1kMEtpaMRZp5SmsCWK6RuLhX2RwGfsHBgwWH0JAkU0tzyzM9Kvvb1hTA3s3yGCwcUWWQG9p8NSWhV9XdFhczywiMt9t8ombgKIwEQr6OGIN9yloCoOBAjQKIDqo2vtmYuuEXoVgLj9hZgT9ZNThYdVBeIraARVZZB3t/i3oIA0Fz9yfv2oDIsTogMAc6FXuTc0DCANE0E9tpvpuo82ibQBMlEgd7BF

w/pgVgyrhdoVMmpoNOSSofCF24U3t79TfrycSkFb9+NBCoLpGVwICR6gPfsb9raGb90/upoOaAokBcBHK1von9q/qn9g/sHRpdQLMVuEGQSXpV9npNYoLJUC9mtE0w/JNfk6Uk4NOUk5gi8TFgBkmEwHXtv9HNkRN8rG6t1vs6c3CEHk9yF1YaPq/9icGpkZPE+2ndpwmUFqUgY3Heg1NBgikzkzwqcGgDtnuBhW5gSgSNABI3yCX01TR9i0hlU2

TPU8aq2URA1NEzcXjNvS032gDERBwCcRSHieHntwnOA9G9pDDwIuGd0ZPHvyU0lWgeHi6wu3FuwKJAIQ7AYw693Sqsockk96mBMiEBAh9crEPYEiEvyeLByyqbkmg6zxfEokFOw7ZED9C8G9y6EkkouDmOA6zxjIUcWDSuIChAIxn9NSuhwIU0jMg6z2iwnftQOPXGL1EiDPEx4EiEhlRnQavUKMQUTiEna3MD6XNDoW+1dEavQmoRsDK4/rDJM6

yACwmOG5NYMDV6I0AcM5KGXEtKAvthiF0F35Dzo8ZswyXqD4KJpyJcO9pMQHQp0cgONl9JE37qE3JZQGdneAc1BYZpgWf+jN1yIqOBvEAGHroOhGqDFYiOseUGgUM/rZ0dLUusF1SPoDBDaDOjlnGWuDB8fsg8gDNhsYKjDOBQsmsyv5lQ48/qK9bRB5oPGEaQflvr9pphtQ/6CSgeoVwQfsg1REMXY16dLaDoQ1k4DXoiw3QZmVREWSsOmHyobQ

YsIKomvyMsDLNbRF+c28C5aCBGt9JiHsg6aE4MroRv9WwiLQ5mM79waVEg9wZ7wwpwTo1WD9kNEVD9oxDsGO+s2DPwcSUfwa/oAIdOEEBlcMvGuagoWDaDu6PWoP5C+iLYmlJwQqRYowTxDxGAJDRFDAQLYl8pfkAactsvBDNVkhD/wZbEa2BugLkjW47BApDqGEpIS5NADlU3Gy66sBgREi+DE42ZDsEVZD4cnIw7ojQIam2ft3wYhDkobRDLYl

nhseCyQW+Ckt51HFDvwdxQ0IfDkSCLLgcLCBCNWCZDuoahDcIBbE94jgIprRpQncB5DYmHwQ/IZbEmbkcwcZV8gPPt26jnEkBcyvuIWclUBYW1acrHCm9Wn39I1kgfNrtCzkzcnzaDGFdgTgaFkSQF8sAxH5JwUCzk7RBoQsvjYVC9pftEaASg/0Bfg/8CzkXbgO+FaLGgCoYF0SejQI/9Gio4fpY2jaAToZpBu4L1vOoLLSt66drsmhqqtenBjQ

I6WAMQc1GIy3yDAYw5GFYWcgFQ67C4Vp7FzE/YY9cnZDhhp7GRZyas7hdRq0odxqgdbLyoIYvsUyUaocK78HNQVduoxQsj8kreGnYTlsyD6gv080iCswvngbIa4ZNwfZCTwsiERt6gpuNiykpJW+E9D2BXf9jiEGgJLDTEzck0a1ZEBCZIDXDzz2oBlGS/Qn/p4y0xlgmqkDLDgThAjcWH6EU6Adwz4308qiEY9ESF9Ya4Ydlx5yEww6DTEY7hUQ

5aAJCWgafgCSCFV9DCFNBttrpkqAlu6xPg1EqEU2XCoMoOwjgYrlslIgGDJI1lPZwODmEoUoSlQLwfc8V6ObYwiCegjMDXD3L03syuAGQrluQo2nmL9opC+DmmCRdl4xvYK8FctuUnFW/rEGGc1HCk3hHlIwRjdglwZvGVWCWG92mDSJZyfgUnmbQR0HYmxrFct6Hj0Q/sDMCOrupEyFAw8H+LrwewFctmXTyWHFHBk7OGmMuDisDn6HrwZ4a2E4

8HDIeJhnQNenyDShpqtGulTgmwFctYREZYJ5GmYX4POoYhjIIwiC3wpIEgjYmVSjECDYIscEyjQsmyjprWvc+UYQdQSSQdDUJQd0dDjg1zM0KDnHnV2DvDoEjPnV+pxEIpGkDiTDrbwg8FYdS9l6K8cWEdDcW8B/grJYT0CniBTEkBS8SniePCOW68UFxoOy/YzikCsH7G3i4O1TY+p2+Yp8XpdPCW0dl8RrF58Vvix0d0dNKmmZWjs/iBju/iP7

Buj/7CmuejtLYt0aejMCSqooCSoSnCWQSEiWO8ciXUSVjvrFguL+Ykeg2k60ZBjcCDBjN3nsd93gYxNGOdiDjrhjTRQTYHjqLqiymqd6gNGdMO0WdWmG2dNztOdHGO+8V2xDi3UKaKfGLhdNwCFdZJEFdZrqld6rpo4VrtHMxgI7OdrsHB/KT84+liuB5gOfVqzJdxDrvysKmMj23rG7Fw1l7FTRT0xqDAMxoPmMxrkacxVWq9d7mJ9dtZjcxeUA

8xysY7M3rprMq3o7M/mIkxD/iix1PiPMiWOAsA2P5KzWNf8t/jHFdWFKBdQNux8wOWB5wIbKbZUMsmoMWZGFQa4n5XF2V4oD6PMbaK03PZxw5F12XOJO47uxd2ezM3FSDB92uVmKsCe1T2H3Ah4xzLB4OJ2w2qrEcYSPC12v7Gx49eGP2+PAuZZ+zf2YB1/VJ4tv2SB2IwKBywOfPFC5eB02UVZhuZLkq1YWPnLj4XJC5ZcbC5aBzf2iOIrjCOKr

jSOMrjrcerj3cf7jvccHjPOgHjLcdHjw8auZVB2notzJYO1zIA1s8fWOF4tFj3seEdjxzOOQGsaOSJzc+KJ281MqklU92OoZP4pRDIpzglkUsqUaLJRZmLKC5EKlHZBGvPozpw9OLGthYF3lBYHGrnONWr61bzHcdzzFgjP9B/jADD/jiDFh2HBGjOwDAV88Z0Ico52TOG+ngY6Z164+mPQY8CYoYiCezOG2tm1/nMM56UqeshFSnBuXJTdZFTyl

t91iSm0MfuXvEPUDYAAePQA4ADYDgAiQE0ACACPU9AFIAd6hzAuwHwEwfEF1hAHrdlSTEq70OQ0LXWg4edFCgv+HkqBxro9yxD6oxe26SQVTyIe8GFQMOSZRlGix1QEKsEbDSjqIdPillGnDx7tj25xOoTxO0rcqlOrXdXD3V1pMK3dbOoZ15tj3dxEKulRePphUVUke90rPdtEJ00l7s+S17rF1Euql1D7vl1iuuV1qurfd4dk/dWutjs+gAh5u

uqTsEkMA9JOBZp+aGhlJuEg9xdhrQQnU0hduvxSy0Px5KHsJ5c1RKAC1Xd14juw96JWsh2+Msefuv3xJMuuCDPPjdxrnOwCibtgSifdh6icAwmic7g0VvHViDrQxU6sy5CbrPuSbsXUx2tyl0SWITG0K2hl2vITMwDvUD0JKqQgHRs1QE0AuwHwAwgXoAxABgAjIAvU2wGECZEJKAgOobdwOqbdMMMZYwukY4Qgc7de4FnsjMG1gUiYQ0yOsb4Wn

2Cpy8C1CXdDHdBDzL4/OAowrBGBIyemk0OiYXd+0uxh20pcqeML2litip167rMTtOosT2yau5pyWsTBeLsTD3PZ1jicZhTtmkeb3Ivdz0qvdIuq8Td7ul1sur8Tz7sCTgsPfdbeM1137v0AXAElh/7vhSVAjktRhHsecMui08wVhASSZH4s4aYQKMsI9i+INhqHpMhq+Iw9VKXbgAHGKTPurBl5SeO1lScSefcCdhuMmcYkNFGWurC3N4qQ6ImVD

gUjys19l3Vd9vCApI1onP9GTzRgMimTN+5hYN9IdE85rAYK4cJ8w1LFc4VKIFDRuFIICVDisAyEWQWBBsRFElUkaOGYQ9ht7QR3mAozjAX18UBaassGqwlSHCjtXxryUtAB4WPX2NDVGUGl5pJkCQAnsYsH/pTRG+AGbFReLsFT2GLN16rW1kN95S0ID/oLNGlvREfghCgqnodqFHysmdeXrRBbhPM8cvaTtxLwCZlB3g5rEqQlPRiJpuDemgYjo

64ayngPmAPtVQdAwDChfIeDHh5T2CckrohAouEG5gY6gsN2MT3cOmDWEVmF3CBIDqwo0tdYGLqIISHOqg/GvK6/dvREtqjBk+1zTIFhAkRH/osIa9tz+hPjF9aOF8Dn5FPT6UXPT/kgsi4NCYQcphJwLKfxC2VEyojiFYo0+vSpQqCocs6FfkvmN5RaJHdEqNAgYiLToJZBCzwX2HP1rGADiRWRvibIDo6M0kkBR1qgInBvsRCPBNEoe38FJ9h+e

1oVlmncWXwHuD/NZVFo2ekEqEw1DywDZBygpNRBCPCDuGRiiZoYaZ6DZMCQyWZxsYguE49G2A2IJCDiMBgaZNMeC0wkOHD+8toVopVqf8czFctOCow4y2Ba+QJvm0h3zQYE1mUgxXsNMRJGhJB4cGKBMlnxkck8g3Fvvo13SvIARrUT51njebGDaTnosz2kyGdIdwEGo/uGvkZfq0Nu5ED5DDKMM21O2kU3tUBopCh1yLLlghLylIDpqtiD4lu0I

2ErhzbSLtCAfdIJrmpQBkj7iiIZ0gSQbbwvUG8wb5ub6jGzUQ/pHiZW1DMYVMEhILUQM9vuHdylrFTT2vOt9fpMxwRpMHgFxDbG2esXiafsgssokM1B8h62/bB5ESSttQNW0dwFVq50jSEt6KRPIkIZuxaBIHTtDfz9tJsFZ9atChwG1r7pJ2BGt9HCBFPPp2convQ4cKFCgilovSH+DfkS0D9ttiCl4LKH/gB+E9N69CF+ZtNj9BSFKjfkFD05c

BhAB8OflWeHgo17Al9ZNsXIriF6ITHubNB4iwNVVFJqU3qQGF0XJgw0LDgwWaETFjtQYLWZ6QP9TI0kJGpwChmxCuCF4oQSB4Ey/vSyDDEzTbHnYzuCLjMiEg4+9UWX95ASLquUwMQjgme9L3nyj1a36oy/qR4qjDnSbnECMqPTCZSeBBIkdqkIe6OnwPDPtR9mDnCCROFQUCUr0k2D0yC3ARw2UBoG6yCNMPUC6NIuH/kVMCp8FEhwIYOTbFVYX

/gY6h3tSv3yNaNL4KPqINgo4Lk4QcVlzneE4toegNQvRD2GS7UXi9dEvQC3yNzPXDwzXcEWoiesJMaLSFiRCubRrDoKpz1E+QUBh5QK6Fn5sREDMiyEcE26CNzECEeQU4QoodqfEIe+ATpSXyuYGueNzimY0kNiIkDxuWew+HBXk+Uh59femCsIUNFIHIjdy1fQDwXIeHkRueqI4/HqShee0KHpIVY6weXgRucOGtiDTCB5jqobuC/KI4RJw0Odk

iEaDnQTCEZgMFuUIBmF1YqJFTcLbCNzveaig/ebHw0ef0IOxE86EZHaE0XIKpmYYVzGOq6ofkyV8pODfAggMr0vCAVYwJE9wX6DqoAJCHoVs0dweqdki2FEusq8DeIJWfLhf6Axwb0xsgtqCNz1+c4j1ZEyIdVESFi/SPQl6Bv0zJvRet+YgYBUcdQT7Tc4hYSR6XlEjtF/SL45Nku84uar94SEdScgsTgy/vRgwfuFY91Xz9X0jiYY/EIGu/qIw

7yFtQAucNoVaKUqPwCZOXuGX9e6ANMQOz/gaeb/k8JPhQNQm9QCsD9tTRAQQDuV8gHwDqo+ipaNv8DGgyZD9tN2YjIurEMgtYefk1cxQVwLMmgftpuslcN3yENHNExVDDgF9BdQb0GftPNFC4htGFiI2eUIMEzNWIVhejclQGzhVgLmvlsZA5BZcamHBrQDhHkLWAe2GaXMkLq1A+JcOwhgRmAOzAgNATDtEBCDac1oTpnEgN7BLcV2dF0ohduE6

4wezR/pWiS9Fo8Puet9Fpqvx3I0CouRsHRkBQFe2FhtiXOn/QD4lb436aRoHAc6k78F0wFOE0w/eY0k8Odk4eHkEIVuHTgIpFnMy/qrZZLH9IpwNAL46EHdboQl6z2GftDhTv0c6VjSjBc8IuKIiw1+CFYI9oWIWeAowaMBNYeHjcpUqlLezecaLFMGaL0xe0seHn5whIZ9QWhqf9vRdwQ/RYYLvAdEao5CO4ByApwhEmFIp1Fyci8UYDQbGg25y

BJ9ftvADsHtBzrRsJ0lkmfoRCA+Cb2YyyiMB9O32YNptAybI4SErwq2bhIvaF+LX2dAx/mBFoovPMR3xfBLmnEhLeHjCIenuMDC3EeL6q3tITbB4I/hZaE7REYYwrGbQ03UeLWdpRiVbBVJ6z3BcZ+E2whyCCBPSByLtiDk4+RfWeFSAMUUXUntWheaF3vJxIjjHyg6z1DIsMKZqB+HWd9Jfek+qEToPBdnzUujOirBYc4QBDYaftthzFRbygVRc

SI+Fut0HMR3gI9rKLhZmVLFvknkYSAv6MxrLJIPtFLlFG4L70ilL6UwOkrppZwqkEVL5RdqIKpabtapcVQYWE1LUSGX9LaCNLyuHVg7wE8DXQnMok0DnKTMGX9dIRvgfnrvYLpaGIZ0UusS/xNg+jB6Lc22tifeQZsOObF6NqUUjdWGd9tOfXYyxYXYhPvgyrjLgQjkGDSb0EjtCFFdQADEFU/xcLE7C1GonNI2IpoaFz6eCBkouaaIbRelL76D3

ojmDq4U3rlzNsu+QiufhAwQZp+H7EfY1hkbzn2gSRnNFizMZY0F1kHRIB70RD7Aysqt0FgkgkbrLIkSfQZdG7UduYvoGCG3iH4DV6ikygIbcBCgSeiNz3uZdo4ugOCk8lsIp2DS6okHjDskUcEOGCt6vVyhAavXkyz0Ak4lxAIDQBmDgbfANWnIeMj6UzHeh3wrgWRugD+nFhcCFEMQ6Ieom+pg/MRWULIvhmFO8WzLY+EcSIP5Y5Ms7iNMwgYmQ

aUBt8cbNE20YL90eOkXoI9s8MzbC7ondBkjJExpEYXAug3qDKjIZiIrqwaCLpYVyIhEghZVuEIolMfkDB4lorr8kDanZeKVWJFfgdUjJtTptHtUcmpmHRHUTLhdOE/oiT26EkKgkkF8MK8BEI9uhPY4ldTw49I2+zNFgiz9ujelsv+yhiGEzPGyQGNlEJCCMmt96MTP9vrAHS0ZeGVaxgUZPqDG4U3t7yPg1CziSkGLtSyGwXZGgOAe2EDyfy/oR

3BqZfskP6OsjEwkHx59sGMVwf7DGIiFZmVB1AzYLEaumI+O0DNowfNyVewrPGy2GPMGEdpSvMDwkk7oKpeEQ/UD9kiQt9c8LWFi0AfbgNQmGwopAdoLYgyIPaHQ06iCoIRud7odzqtwcytpDJuUNJmeqGMU3okIyxhyRbomUrbOjDQ70ndMUaGIw41ZBNDnoUTVZewcoHR0IFBmHgmwCJzARChwXOEImYFdTwHznRgLeEgUdUzDLwJAjLz3gJA2D

iimBlkB8HRB59Q5GILlUmZRtZeU8MRj0Q/2X6toRa10SpadL+pajDk5IowS0F24Gwb2QGbEZLvcy2zPKvigXkA2IRcDkDPSENah0k+zdDDTDqmxU4ZZJfgquy10rqBEZjDB6t82e2Im9Kqg29qPoXhaR4PhcLCJOCLDA9oF4iWfOgU2f/owJFmzYfKzkB0htwVbENOhALazFxhZYnWa5r3XggYkejXgU3qbGzKJNwqvENEhqvlocUjW4iiJrt/sn

jo9lCSgzue2IcBm3MgujBgDNFIYsmCWgd7GTIWcgBMb4DKo7Qt3z+4gNrC3SUg39tHDRbUowv5AiLPPpzQS9Ftrxtdcr6gtMcPElm8A/0vz2EgRouFAWwM8GTVsytjo8hDLobMdKavIopg7btUgx1dVgTlEKYbTyq+ARoxouKqdk6rxqIyat4ysWB64+RADrouhdgvbTHIyrhmrE8PmW43tDgi0hEdBSDRrH2anwZBaI2E0zikR0HScZxedQkxcH

kb0DWLRG0CaWxYYk2sBerX0l1THcEFr/paI2O5sfTUrA2wB0Yb903QMxysnoIaYijcFH2MmmHGX91DplNYOwigq9cA+COlYofXCTLxOa3M12nJzRGwL0EGCdY3pkNgFZckICdJrLz41nhquT9zaJEjtIeV+ayfTChe42vQqDEMj4m0jtWJrk42XAOgZAanr/MyDQAONPYPPpacOO0rCYDYrrUuh/C3pbM2waT6gkdq7gTVEjQxYqQbJdMjmWyu7D

Qv0jt+Qy/oYkbVkQn0pVGXin93wDfzQMI/zd+f0rqsE+okaEWU9SBAi/ZZtG45GnzHcFkjX1HX0xvIVIABYrzzICrzXwFct8QfYIASF2Inud7hfVYa8MPESgPkYPEgyBASE812rEiAqQDcnsQ1CyFQQn3So5XCBwj7DQNBVPDz7WGroreCd08kBnxLkkRMpyYX0b5YERojaeQTun3S7yHZeTFkRDsGBHq2pAxzg+Yj6xGRbwS2EZYU3u8bWmF8b8

sH8bhYnygH2Hj5eInK90Ad6I46mEImhad0ATlmmuqeOoPPuhGGkRarRwisLmJBCwWbDzg92kPugFfTosmDisSEitLqeE3gjVBZQHVECcSkPKb0HlRoT6Qd9mJAWiz1bf634E0bi2YjzP0ijzTunvEqFBNOUqFQDfTevLOjelqejad0pXhqzBphOo+Nd7hoCDHIv5Emgx5ZJIOVKusnsRHI1zpHhxuCZr8WCdz6Zf10AUUz12eZyYI9vUcrMkzwlG

XbgJLlzqlmFhcOwmybsQiS+iHHOQYRpJIIg0mg13CloyvsAr2xofEnzdAQJXh5o2TErhaaGgDCBAYzMlXerJLgicISI3qPIUarkM2Ng8pBNwqVal0y0VtI0qCzSJomgDtJANaGZGerTHyeEUvsCQiXBMbvcIGQN8BSU3yG8jfdN7J+fAxC6WDDznsIwVXuEsbfdMaDAfrwaalT6bqzcPLGzfAbfokkqHwQZssvj7DQrYPLhDiPLYrbr0+EA6k/Rr

xbI9rjJaOHlborbwbEgqCMfUvkcX7CvL2jd9zd5YMyqxCJYVycdwOedtkPudvLszdEtDrUUDYeFFgV5d5d1HCazpzd/0JiFfgbDTrCWe33LmrfWbbGEVb46S0+bolYLCtBbQK5dnJ1Mfdbgqk9bcUC0+RLgCwSINCb6P27o1sC5aB5tEtrGAlwtjZXmaAbHI6whqEpNVxLjwmywTNCP6+WzTbsLbtQ8LdnQBmQmci/QQ43VZhbSgm+yCVAbbolof

6yZCg4RplNLx8H6kH+Py+MJdSg3wh+Ed0TitXhjRbuTcMjWLe+EQUcHhBgI6u+URNwkBb9ewQu+Egv0nE9cCzYVtcHb3UEWwDMRpwxFC3b9LUisGEk0ZiTfTtUmfub1EahedgexUnbWmr1vpubaxBEjGyATbjaXlpCKxcytV3+Qb7dYIH7Yebdoq8GdU20rs7AEM2UXfb2FJA7O0wdahrkH+/ruvbtzeA797br0HMBpWGBFagtfvLzeebdEBefEb

doqTk3ZvhoDFBIbhijIbQiAobypB2IgYjOkRCB3tpPU4jp8lwbypHOI7Ci+YlA0jtDyBlgibBXDl6Z2me2ABki3EaQ89eLh+pvzLYdVegypBOGzM3MoJnvQLQHY19rUh1bcUHPIcYk8kHwiPQiIYOkTaEfr9hD1INEyOQP3XbdhBcaVB1Y9YuuD1IqaGFQv+CDQ0dYb9GBdkwWBc8sepA1C3Ch2N55bDL3YiEQy9ZAdvuEwoUXTdgSCSSgXpeezb

0j9LAVfpgaq3rguFEhI7RvC7Y9d9LASGi7L9KkcZXGebS2HRz8sCNoj3pckepCUG0dWVw1FPH9TOCzOX8JqsidYEcWjfNQRjdb0z9s3zR+ngwYhTU7NXbGQyTgRIwVbtz3PC8MH3jwwepFzpfWZroEBCJbPjcCcfjZqbDKI6WhCHXEd2ag7wLZxYopC+bPIksaPeAhrOpmwgNAfMEzAeGoF0D1I5Qx10LtH5l0AcyoV/uuFkJG+b3mRuNJyKETJL

GftQ7b+BvyxXmU3YEc8tJkhM9Cgtabd1CQHdg76HYwtt5gHCP5CoQNdqkcSsmCMc7U7IgfIdas5gLrOes4bZja5b+2le79MA0oVAOio9zzhYAbbWbSDAYFgfMCK21tF9ukF6rByH6rijZR7JMFRM2NGmhPHtkrCOVPDi50r51XdR7fqTMQpGjGb5ee3QU+CEz5uebNoIhEwgCdnQ3iXz03aGw7gVB/xfwED5IWATQpWG8YPHdjIVYdE9k1BOmzWD

QwMDNnQRsRV9p9cuI59cE759NeM+ijOwdxCS7PpYKZDcED5fPW1gKery6nddoLreiB6JwAt7CM3hCSsnW82Rehrs8FhrYLlJImHCgqVeol9Xhj6DJLBSLZbbJEa6U1tBLkLI5PpwUBMlQoyTMJqSojTwLYvoIPsEFzPSHmJUZ18L9NdKzdCIBkmQmGDIhexot2fELw8CVEqxqlYF1RDYrzC103EnTgQGdE6PIjAmeiBZcomE/S8JfRrTdc+r8IgI

QQ229EcYfVg7fcbrfxcb78jJrQzRGLUDNkH7EJcxrpWd90zOAyiGLAD7MqFbQchlTcSojPEwQt54x6EBz3aGBzgOFFGrxaUcNRdb5OvfclBSCeLWJZeLofZYkfU2tew8jIk2pa5LUUB5LFJfdILWXC9ylvlgoJc4L4peHIlpfHWmS1U8LexlqJJdLCZJbVYfJfdIVr3cV1hluEnJZLrTJfTGK0HP0zjkusfBRIyGoljravYYUrqHP07BiJgzzy8g

IYaSkDAprQjSS77m6CvggTlywCRJBu5ttd8QMm36ozxempy0TQD+t5Ig1DbEFMGVwv1CsrdehgQYbG5wcCCZopQhVTcXRRImXioZ9ytbd3oX19yrDLg3yE8QJGCoZk5HWoVmDXg9cDBIERCsJb9Bvg2LaIZBeisY4tu6EWBEewzIT/ry70yzDBgYQGjGMHLreDwZg+YQGMEsHAIYTFyDqPuA9GpcXPDVzCisajJgPYmkJdCswqJW8vrECHjUbQCh

sAZs2sc8H/g9CHdDFCsl7AbYZDoPYE0MASyQ+79F7HFY17H3YGQ9wx2RRnoRRk17eQ6Li4GCFxa7HyHpQ7yKF7AqHuRXLgqQ9IdOQ+KNuGOPYitDPYGGM5OWGO49zChNiZgzIB86oGZWEEOM11jed/zo28qPm4BUAeHU/uyEdD1mHUYuLYIY0FIjyXJ32lHrC4I0KQCY0KriqbEYOWSAniDhikdBSmbiTdCEBebBDdZ+HnKpYrMY5Yp2808ROoYp

qPiL8BPiwFAOjgiT+jaiTcdIZxqBybFxdIDGxdBLsVdXLtZdtMbld9Mdld9kGVdxrrpjRruMBJOz1jNrthHw4phHuscRHaOwRH1ruZjB2K1KaOxZjupWjrO9hxHJ2OMB0mOdjNruJHg6iJHrOybK3MeG4vMdsdKzL9jdI+3uCmMZHFgNpHKHAFjTrqKsLrrcl3pXtKWfiuxGfm18RvmuxDpQFHOfhuxsfmyB9OwKB3viGjv2aj80o7N8JQOs43pS

lH+QKVHFQJtjk4rmZzOxbKFwJJH1exjBOYNPK15XfKJ5SfKdXA3KTljMCEuw/K3HBtH3sfYu9o+/KrljAqUXOS4YuwdHro6l27o49jzo4Aqdo464Xo79HQY5dHEXPbEvo6q432IsR0XMsFbo5jHg3HjHhkUTHPo4TH4Y764aY6jHSY5AqUY9ZHfsdfVW4pBxfuxGjIewYUXu0jj24rkHWVkLHvu3LH6TCjjO4tSsNY+jjVXGD2rGTLHrY5LH7Y8d

HbY8D2l3C7HfY87Ht1lLHPY4HHJfX2Zne0x44KNX22caq4K+wc6s47f25zJ7UyzJ32p+1XHy4732c49R4M49ljeoh3HC473Hmcd3H43HnH6PFPHB4/PHU44Vyh49x4m48uZS44P264+3294/zjZzKfHeceWZZ47X2c46hxacZhxv49Tj3VmPFkOKAnx1jysh4v/HIE4PFf4+AnGccgncE4gnsE/An146HkV48Anbeqgn8E8vHP4+X2OE8XH8g7HH

kDqq4gVmV2IVkXFP82JkM3FzHvsZgq43CZHvMdgq0Y+TH6Y+l2sY5L5nseDHgY4yzYY+4n/5Rcsj5VfKz5RDHPE4DHJ5WtHvE/EnnE8knX2OzHEFSzHqY5YnCk8i5mY47ozE5zHak7knv2Kkn/o4Enyk4jHqk9knik40nRk5UnSk7UneY7onFE8cN03GuBks0TQZE8xgiuw4dmzPInJE7oY83E12eVlW4nOKisHdB8n63H12WSlisxuwF2iVhSTF

uwjj9Y8rHeVmBxtY6inwCKLHm3FDjuzPwOduzleqU6d2zY8bHyrDinLY6bHFY6SnCU9RQRU4Kn0U9KnuU+ynVY5xMVU+LHw4+7HQeyInHY/u4TU9HH9U8HHLU/an44+KnDY+qnvOa6nxE86nccRHHjU4GnzU/kH4eye4XI7KniU/inM05Knc08qnhU8WnFqTynOU9WntU7rHs0/ynS0/KnK0+rHy052nG08On604One06OnZ0+2np05qnJ076nTX

FunsU82nQ4+GnDU+Sn5HA924cdSsVuwR4Nuz24305JA3+st2NVGt2gM5O4/0524tuy24P09BnX0+Bn0M924QM/uq8M8hn4M9+niM88syM7+ncM4BnCM7Bn2M4hnWM6RnOM8dBj6vTBeYOTB7IIpnAoOtB8YMLBtM+9Kyo69KKwLDFCwLtjqwMPji+m2Boll1HullvV8lmLK+5FLK96uoKmljUsVZXLKos8rKMweEsXM9TKPM74sKZV2B8ZTux4wI

jKDsfKBNQInF0wJZn6s5ln1nTln3sd/a+s6VnAs4GgQs4UsfM7zKulkex4s+OBks9aLvnB9KWo+1nThN1nCs9lnJs+zKgs8OBws8849s6exds5rKYs+lntrDJHTZXZ2Yc6G5HZQfoXOxqwLvk7KdwLjn0c9uBlnh7KHwPXuM4of8xljeBWc5jnic7TnRljznqc+TjHMZkxLsdDnlI6jnEs6DnUs+axhrFrKdc8tnRwMp2GpUJHS2K2xK2PlKbeHW

xoRcFWHc72xgpV2xG2Mmx42NmxKWPqx/xT8xLZjhHeZgzOksaQTNiQoxCggsdj2zQ4z2wRZdViy5ibpIqgydO1IyYKlpCdVxEyYkAfvCrAHACAe0fGD4QwB4Ad6k7ApAGwgwfB4AkEEggRgCMAygB4T1uJB1AODScbFEeVfk9dxPfCPAU7zFG0VFjO/bojxn9j7Qx4EUR4GDoEKiZxA6QjeIl2jp6zYcI04tkghfycVsS7sMTyeP+TYKdMTWEMhT

NyUsTO7usCNiZZ1CKdOlR7rjAziZZhlePZhr0s8Tt7p8T+KafdASdfdxKeCTeHrBSneLCTHAEh5Dib6CUSbBlgHvHODCPdspuqk0DKaR58Mst1kMbGgnKYJS+kIJ5mMvQ92Mqw9wqe91pSZlh4qYITw9jp5WkGqTe2oQJlUgug0C+07XJlMHP3XSifO27wrW1MXpiv7UBQ8fNiC4kRti74HysDcH9UY8HyXITY5lEHNpkClxQwUyl/SfCSmScgAQ

yYoq+8/O1h86Klx8/QAIwGiA+AnOA+gAbAfQH0AR6nRsJYGalMgAfADYHwEygF7A7UovBVSX4TClSUQzvoL6oDa1Dp4FL47cGAXOujm7V2ZkTCC6s2lmfOR1KBeTwyRGVfWenYBhh+T6C7MqmC5CCgKeQhR3PxhxicOl1OohTm7uIX0KbOljOvIXsmlZ18y+oXTOpPdaKZ51GKb51WKZvd3ifvdrC/8TL7rV1dmn+lISfJTbAEiT4kJEXcPP1Qtq

K6Ski94A0i5KAFuqg9w1UAUSHMUX4S+UX2SdUX/KfUXhSc0XuHt911PL0XRHoMXZMsZ5xrjaXGlY6XrkdTS1i+QXJ5g8XuMhhXgYjhXRaawoDhhrmEOBfgFlq8XfTOViNSaCSuCdlxR2rBXES73n60IPnYyaXBh6iOAgutt4d6mqAlQCxAlQGECmSVt4lQBLAsAGrAuwGD4H88bdZS7WAyrYvov844Y/8+aS4HpsHojaRrgqCceLS4FsbET26zKJ

O90mngXjfHxW8226MI5E41c7ojxwy+WSBiaBT4y5BTWtimX4KcIXsy9wh8y6sTu7vhTdOsPdyKee5tC/RTbicxTHiexTzC4OXj7qOXRKeaCZy+4XAkJjsbmn0A7FSuX0sJpTk0q7o3uFZA0MuC0jKdmCby9QAkOHQwTk+1hCHoyTaMpUXRsLUX5kI3lQK67st9xBXBHqUXkqaPxpHqhXKXWIMCOmcjt0FMLXsFn0CFG0Hw8FFIuacj74SHoYTKwb

XujDirYCB6go5Hut/HTFgmMBHIhcHzIFhprgSEeCrAQcQLldTxM9MXDI16AHYNxFhcE0DjgpQMTTDtWsD6YzwYrnyowNnjZqWCLRqHIAoNjcrW4EtbLp/+Ow9RxlNWiBDS7PwoxMocAPAOGHyDp0gYR+YjwC1OC/bEPUwUasSCi7H32EhiAU87vLjSMnZ/SeoalEkANHYaIg/tTxMTyAPEqIr8kOMASMUd+4jxQ98DtS+jCMwlqokts7Cpk2uR3t

sNGaDL2ic8PGAy9EdFgmMbFXg/sEwHmTUItNzDrgCgrLgCVFYogwyqziIjlmV/uUqkA4TN+6+Q18Af+rGNB+kq8gaywqD1746XwyV6vGgJnE5LGCtxA10ELCnUkpeUziZAAHGScB2bGr1ZGPQGdh+Nv8LO4DMXXEb50czKzznQ8rAo9fGwW918Acg1+TNyoJcLMocgU850CzNgTMswVkyLql3gl9yZGjtl1lyy0PpfI08mutsmJ6QuATfgW+DvZP

6/v6/Mx19l0Ehgy+eLhxsHntnZDriFPehcsNuIFKXh2EndZnjA8CImtaB5ze65GwPxBSgy/plrRA4LYocCu7Cc0QzDtGbacYhxoXpcugghZyw1UAlz+HHDwzOCq+L5YuFSQ3TjU8BugBTf+WImC1gRFCCQlsi9LT2f63LXAtz0prlIx1FWgW9ZcohrQq4dwADzEZCZAuq47Ii297Qy27PY1/bmwE4yLbvJyaHBvtc4K0GNCeDCYbYVuHEOHYNMbA

cr0TocuQaMcFwD69tyVRAvztfoJ47OfgIBrU5+n9pcK3BsxbBLVwQmDekQEOoQc0kGCw/g0hjVCCgWy1aLqna90QbJrbzyquVpWe3uIb+eW8iiPV+k8DqogvJ/Te6o/LE+aZo92mGF5NoMLKNQ1glyCmQO0Ebz2qaAjshuDNyhFcCnvZBq3xoALnnDBMLRs5MJ+ZMZi3Fdl3eEa7wpP8XHDFYISwYfzlO5ng31GXYYeex9+CFjDq2+UIQLizSYws

TgABZpwAPDWIEYn23F8ksF+fQUI6TB3tyK04M+aDaw9pA39Wf0uQKpYtI0AeBQY3DSgCsH3A1NCG8EBCj6SkBrbbDEvDY0AGgiAZWi+8TcGCkAe7583ZrMhIS01NHiDu8DkNCJHi3k0lrQ/OxY7mtbQ8Z/Q7Y8ZfqNOVcFchFDwCRXSZbBtP+CY+B9giSmFIwgfrW5GsBCBkhuLfDFgzeLc9M1HE2w6iEEGr265CrGGdbERkhosjYf6rrgD01UAZ

AeHmhRbljYwbCoVD7kUThAoiBkGdrw8C0SUsIgLQY5PtBMXUn7CC3B0cV26JQu0VkH41ohobQcDwo0Ae91L3WeBouxt1kkBICoelJy1KBIY7E2N8GUCKGu3fo1Tln3TFctU64gXIicEMDX0nsg5W8wCXwc+FPRg12FhBZLNo39wwpHaoikGnDGuGskG9v1Qje8Gi93Q+ExRbd9CYcDQs5gHYLnsnrxsjeD1sGVNn6OnDgoVRg9Aqf8k8hxMy0AvQ

ZZFMINiADKoISitqW6lJuMytcexcqkCEZSRwTeIQavS3Q/a7Y8V6AArZEb8MMB6LqSyEb3xgSaI3MDOwzccPDzMgoZOqU5wGmcSIqxvUQM0nxQUjDXDCokdwiuAGQLIDiDIKwe03eFtQIYaqckivyN8lH0HqeEkqk+pYQPiNnFnB9dpz5b5KXuDV62c1jI6Th7Qcbqsj4Ey3wB3HlCKK7HEOkCL17Hy4jPEebwKxfw4/gja7iSuSww8TNu70l0jz

h7zUg0gCwPFd8+S5K6yS3Akj70ge0R4luzDQa557cEn6qhCSP/h9SPEZFyIf6CBIzCG/6UogkjGbEsP/4gRguRC8IS3H+YLpCps51Dv9mMD3VlR513C4jCIZdhNOtOGSzOh8wOBKkXO4wcQJYdV8LqC84PRW8LCwPZsNfsnJoUUHqQAbDrr1Il6yYh8mPsmH2DS7WtwD2iBIumcYjqdRASoSq/XkW7eQOIkcWxGCkkuSmwja1moOkWT4PvIgeCtl

CUsLhrWAs/2+YDyE/SiyBqrp0gcc+KGPAQm4eg4YXbIaILvghx/GEqUc/MZlC7OH4e2gLx94tZaAIQxIc/swNqG9C8RAj7PKfrSS2Z7PDVwai3Ehou+lOnFkgve4mzQI7GpbEdHZ2EIFFGqI9r+PAvABPbx7hP4ciUijbxEwtBiUjXB/GIPB9EwVoaWFEWBhL78UaPoh98LKx8kPQxFlcLG+95ECH2bix/5PEx4xgUx55V44g1Y/cXeQ+7Z2Pa3D

qwL2cBQX5Z5VDhSFIoEI+aZR+aPZPFaPItZsoaUA9GTuB6Pfh6mLAR7SPPKs/EitFURSsk9D/OG4H2sBCERwjaPQapp0eDFHSVuC1h5UaHQSYYgYS+jLtMVsjFcaT2i1fbWAShsEu/Ek8aHp6aaa2CwbtsAVtslft6d7A1g7MvrHyasIMCPCv1wNqf9NYmzWC2g/A1sgVQERHm4deErwyWfKZXUhO02NH+3nU1dz+Xz1YQOC+D2UbyWmOEYIDFc6

mV6N0LUyFUybZ7ZROWU7Pz12X3cGwLRyC+tjHZqyjQ55bt/MkPAY56wwXIwXoT7dnQER60wo/v0Q5ij4P4BaXIrtLWscUdU298C5M8lb6Q7Ef3GBYapwzdAiPRZ9BkJZ6E+WX2aIHQ0usER7trGZ/Q0WZ9rpC2UC4VHAlYRdYskD4zA2yjHfqBh8i8ghGUBjepCEPa4lQ7kebRbivhkTunxLGbEuQflNMIzp9kPIhDR6iu4j6eyCT+5WzwIIYfQv

wmEwvxtvjPt6AR6oCjHUilYiPvwqiPbh8XP2kBMiOpDtSGdl+gCh87IwFH6Ploa2bPSu0jOsRFIa4fGPGEnsiQp83GiYcjrT2GVWFx/9IVx94PJLnRWVZ3j69kDXDA7CTo9pC+Yx1qGIg0QsoCrDg02XzXDH/v5IF4k4MJLnmWodGytRFE9DLB4fcHwRjXje9XkLtLmYRRh6rLYZWiEyBOIKuysHSreI3s+iWIdqEysFklbDf5q+Q2FDIv2+W8Ru

eCeQHNCmQ04Zh+guhG3QrCY+YTcz3AiOAo04fQqPxB/3WeiUQjXhJzAvFnYeIfu0HZdF9LUAMyLrWMw5lFncox4lQdkkS43ElJtvG6syk6GDJegp/qnofv3gDEf3MbHvzVmS2FHMozwW+3yDwsiarspm1yBmUvkqNBNwtOCbUbQduguZtYKJGQMySZHh9lqIORyWbyIuzdfEbDQF43wjmJnsSXK65Pav/EwDIYA+eWqGedEW6Hy+oWHLmDnQvt3u

Gag4i5tEwJ4BpqOCRyToalEyWcpVKiEfBKRqCP5ouDy3PnGQpvT8D40Bb4S9HjM3wnBi16EYItzFyH2RhcU22Xw4LfD+v2aCWcs7msk/abSwvhk9wbO45lJh9o7moj3DBedDzQlaoIYmEzZXTnY7A6zNKtPwPVOVY6QRyE9pRIWVILhiDQtDNm8YsFO7ikAwI1mAB+z163wL/uQS8PywYjVbSw5+EmoF/TCv2aEFss7aXJs3lt3mQgEPPBKd3gXf

0+T2HGalfCg76rAowYgxnoDF+nyAJHmEP05+I//ubw0Na134uD1I/gxHoHa3Tgsu9KoPUChaUt9OpKcFpLhFuUK9t6rYjt5sYzt4nQ0mQzol3jns/WYX07dfoxCu99vhombwlZ/KDM8CvLB7whcCwfOv/ZtcC28EbeOFztzNOE9wou/0jgfPYMOWXnD3V9NvWjITvZ2CTv59KTIX6787hiGjbl1nEzC5FwojV5LGzSyKUfXDJiHO6sDnhvRIh/dX

0lrlr58OFeIGd5yNFMEG94u9X0NpgYwlJqyNQu+LvWQkTvGJ96cB1CPIW61puABZnvihdo2SojLmGsC+N4OGWbrJfYIJd43v7pHkgoqgBwUtutbod/l3Tt/HWhjS7gFBk2wkZtMbcu+9v3EnHWjQbcGKBVJwRLbX6gZxn3KN4XQi7Ub6rWRe8U/EIDdu6Vvju//vE6EZQd25KGpKCBwMLbV+F2e7oCIHP0GRATgssmrQMLc93Y0G93PV8AZXDUhB

ONCGdB7e9Qpdo2wC5H5vxKDG6I/JqEiFtHt7iHj3TVET3gDN4yrh8OCGcDCrDZEZvlOY5Pj+hFGr4i+Uf2yErWVFcQoUA9Dc6869NEU1gO2/KQw860Q17wqvFN+vkL0xURPskqGreGEDGe4/Pl1kbNL0xZakGA29nbcRDCgYFwUyDTv/N9qiKlpNDUhEEr6e+9QT+CWK10Bem8tHGt61G8gj2EIr1FOaYg3MOAL0wJiUCd7mfkFMrtFGuW4UFYL9

l5gQaOCVkeAXuNWj4cfvGBccVR60cKcF7t9iDYayWNjMxTdGg4T+5bVDI0tRWc+QgEe8rSwpUQzKCSfvt6gwJjPJ0bHs7sOVbgeM6ZNElBhUHzQqoQ26F+RJT4afmsCafGsCoZJYQ+aedE0kwga5McTj7Ts6aoZkQySokH2HrJT5GfrrDGfi3ErIKWc3NocFwcdj5DMJe7xYraCI7lWUMaDCI+gthUc7o9s2fIjO+Yz19gkAnSUg8pBxY6z4UfgU

TBbylE0alT5BgoCw1ql0BM3C8HF69zsVti3DpPlWQrv6EndMOHXMDGPdTTb4GXgC3snQH5azypci2M/mD2PNGSOCChgREhsQDIIaezDtNh44yg3y+GhQW9i985i/8GvkIYcsFFxgCI0tR6KM/RCo+qhtgpYkpPO9X18DFG5NM/RTcwpAI3PaRODZ3sJo+cFQfsCOhRKHhvYl6GAj2ofe3vGArwUjA1T6zl2iqFB8RVzBF2gV6HQVsUXOS0ESvZ5C

qMU1DMQLpAWP8r/C4YxeYQaXEHInZMGQ5WAE8yWa3QFiyn6CJAv6g5GHS4MhbQeK4VDnZIYPbcCYPqr68I50DL8o6sEveRmEvEh8b3hA2lpHGDYaDZhovTCDovAuHcPyGCa+S0Dcoo+FTPRF+kbbp5novqxUyzyFGoOFAVDhI0DPuiH6EIZ8ScHndFgbgWWN/p4YIAtLhQCZagf/Qi9SSGQTzDEbcjRxABkkTcTQpkF9WbqJ+3pwIDIER7eI+sw/

NiuEqfzTQMxaMBwNr5/TPN5YAaxkF9WrhSMMRmC5s1Z6kwfs/sQY79AvGUAVQUoVJqSYkHggLacPb59HfkbCXfZQxyprsQdwcBFn3ts2+INuyEQdTiYDCGCj0VY4AvkSiWoxZ/cRdTnIjXKFrgF5egvdb9vPH9BPIdTkbcUzx2G4dBvPM1BPPa8DPPZ5B77k2AlpnmNfg6590yvllfXFFDqc3uQjD6/SVTT8FRw67EZsdRdm8dTlGMFFALDcDGnP

QslRw0vDGg3XoG7HrwuokbLiMUODmok5Cv0kC0CcDkAdedSCyICXewQ7OA0FI1H3wu6DDwDrzT+EDEki2uTo/rwq4kfWmIpDrwBIGOpl97H09DNpBakrfU+Dfr5gfIQhsg1HCPEIn7YIPFDSg31ArfbEW9I+5jfOnoZtMxL1wod8CY3gb3Ij3to4iMJzmoKhHuL4NBKjEr82ySvzbLgqhwbdn/uRDhCoIPXAC7HhjMvQMn2gKD61fufBeci5HEfs

E0CMtEYzPKhuBIc1DCimtuar/sG7vWTntxXt8NoOTi1g8X+LQzDpyU/qXnv9Q3to+8nzY70miHEqEvk8rC0YwjCPQgRirWeUFEg2jC+DhR8zEitrrgEm8lWTIjUQ0AWLUzTafgB1GbohsEsvf3r5GrjNX9eQZtlc1AJii9FLbjTGevLaFiMtiEhjiMGSzUXhfylZqgw+t5EwWFHjoMsERYk3+/9RfyRaaOCOy/OFq4rF5e8XwarrrUnCbr2SOyY7

38o+VBroIYdJIfMkctzjBjYR2WINVdt8sVz7mosIfuvG296wBRnQQjZF3QjVC+D9nWn9bqT/rBRiqFQB/bsCZhhoDXRHqXPdQYTO+iMIMDLsSgYPzQm9UrtN8DqvRF9vkND/s/WTSUxPbJoRl3BrG4nBo1GdIoqlaDFkaCkgg/g5QHc013cOsBMje6BQHNi7gztebYRG9nsHBDXLvGHtRJH+uY4SCLSMNGfg61JvgJOCCDdP8zyi7gBebvdDE0eB

H3pbDJPe799I5jMp0ckgJy5Pqq6319491WBkRWvvyUy8ByyLqBHtVXW6/c2ZNwNdC19fiCj0pVGo3mT84QhS1b5aWbE3c37DQ/9a5agKEePVXWuYfUBNgGTi19A5oAwsDxEQktahfbO6FQEOEkfLRj7CDWX1UX9BOsHKCkQbGA1qLMBz3Cc3PIaDEB80e//PnCFowTpbrgb0QQoWvrCI7uDe90lWVP+cmPaHcHdTVvQgGLtWba4NC09g6dDEdSHt

ixCnYdm39aMBG053q8k9EYSF47ThWQV9fJgmXZFnE0qGftdQvFPi8Xlg64jm/mFBc6n6BEZ8W4RED6EKm4ZLLI9fPYMZDel+3CElrjQbNwVBFHIfn4TmLOQe9nvd2HMNHJ+lIbNILx+bf+xjFyhrXMK1G5hoLejCwjwJ9tkvf2MJMSJwgWEXmBf/sNWL6LgMgeANAw9rP9gHLCFwEsO+ciTbHwYC1riPpz+vSQGeHj0FpBz/pHMHTQGIL2gAIBg5

GYITZbXosygMNBCFBEIhao/AE+GAlAoNmCYrvaqIqQBB9Ko1A/6LCBg5PYimkgbtLBIMNDj1BPqnUhjkM2wYOSo4MKgZPDDoHigktbsClZ4swiYBJt+PfadWqYqaGCd/mggNqTz7ulEU5IRvkgoPfb4sM7IzfbMgFwB726koILorWCa/vfyHeT1XsBEeWClFouMyUDBGJQ+idBg5IkK9SA70P9kgOY72I9gwbayIKpIEgyCEKHg/GyqUHK+kiDUM

vgsCPAE5AheLxj+QjB4eRjLNv9CLugQMObgXl5m+ma88tS8oEBw2paLiFNeDHD5SBIMwMxuBuJMj7gS0JKgiXBQ5jCI23ovGNr6Dh5M7JEQeQHLdFEOB2jNtFA+PwBqmlp+zeqIhks4seogJCIwVwASDBGkbGDL2IDgZX67IBdQuYovMF2QYkASDCFg4axSjN1gpRYeQB1Qt2CwNDJgc35C0NZIPlyhcN561iA+jBXgdEwS0oxwEgx3LBJwlUAOC

jj6HMArsInAI+6FwBIM0WCBfKEoY3r0Pgcsq0C4EC1gvaDw5F4QllCGKMl+zQFJKqTgUOBe4nbAEgylUg3AuBhY0oDmYAxAhIaIv9qbfoO0nMi1QPboVFwK6BMMgyBjEBZQml4JzBCAGkgFsPJaLl61IMCBXOBjQHjgvwEgxElG3Qq4ARLQ7ea7kEcInRCWyDsBfvLwUCHkIt7WIEkQhNQhSJDa474e0BOq9UKErp4OuHDkUB3UtTAGUL0UykhJo

Mwo+sTXQIbE7CTUHK1Yroix6ht43uxvgHc2vc58tCNGMw4a8HMOGcTi4osO11grDlKwaw5lxBsOT0DjQtsONcT8AvXEcjqFiilAxAQlircOQOxlNpWwHZxLRpo6P8R7eK9Gh3i2JE4k0Ow8JIDGZdAFELY6rTokPvyktzrPOg86vzpcYiTGyWL/BGi6+6qbppq6UI76uhiOrc7U7HBwkc7BbvYCjrpTTuxOJ2xpioBw6mIGSlpiZGqo0LPOCCbzz

mgm4sYrnP0UrzrznK9ki5yugTRMS9x7jrRw8sZTzgsUM87E+KeqpPjrmGaw3gLhYvqMFxTicEliDPiPFFeq3eaNYqPOkQIUlJiO9ropApaUl2IazuOKzs7Mzq7OawK8ziWUPs4ecAnOxc487N2Cr2IZcO2CPOJtguaOQk6WjqxOkY4d0IWcy4rUTkeBHk4/7niY3k5rihFOG4qwzkTOBM5vTvbsYcZpThyOKYFR7F9wpVhp7AnGC+wnMsnGKrCYT

ohOqE5ZxkeOa46fjtvsncbCHpAcEEHtxusc88YzxvXGswziKJeKQihHHOIc6OKAnHCcWOIInI2osqjM4ktYb4pfiiycx8YynNZKiPjOSpqcSUrwsmHAsLKIauiyK7Y75GSy+9B7xlCoWHJYau6yD7LVspRqI7DUaviwrGogMG/GGKpWaipgNmozaq1qlXpMYqAmdzDIJiTaBYEVeuJIuZzceH1QBZxlnB/gNDAyMCcw9ZzyHiEwTZyeMO0wrZzLM

HYwelgTnMkg65zb3DOcS5y6MMWBFYFznKBcb5w/nMnEcFxvQEGcKVy1XEZc9Vy1nCjclNzZ0DLGudzVgb5BWPizMD8AIYGxEKuqoSheULUwVjpLGOFB0dwtDnXEQmD3sGogpw5xQZ0uydwFqOnge8ChlqlBXCi5ZFQ40dyDxFbuIUJ5QYz4BUFuiEVBy1glQVNcaUANsGxuT2BMcFVBGUahIq2K9UGlRo1BdUGAJDVBuFrJ3GZiNmLBpNHc3UHti

L1BXUFPeOZi3XZDQfYoI0GDQd5B/UEawHzGlkBWYjsIA0GzQVqYw0E9QUtB8L6lMEhY4lBZ3PPEm0EHcH1BBTC7QbncO0EI4FtB+0EbQSdBe0FdQQdBF0FHQddBUUa3QedB90HbQYtGY3Cp3qFYYepx0K9BOOx9QS9B1tAnUD9BK3hfQf9BXUG/QZkQwMFTQaDBb0EAwZ9Bf0GVgf5gkMHfQSDBgMGwwe9BNoFAwXDBH0GOcOjBqMEIweDB4Qhow

SjB0MFYwYTBSMEwwWDBGMEEweTBOMHIwVTBRMFQDLTBpMHEwQzBEME0wVDBjMH0wWzBLMFkwZzB+MG4wRTBfMHUwdzBiMFcwUzBPMG+3O+whwgmxsncEsFXFBEoOwZwBIECwUHywZcUisFywTLBqsHR3OrBPYGawacU2sHSwbrBUsHeQVrBhsHhCMbB5xT6wcbG5sFGwQbBVsGmwTbBdJZ2wZbBDsHiwfbBSsFmwc7Bc0HuwW7BrsFqwT7BOsFOw

d7BAcG+wUHBmsFOzraYocGMzs4oRV6ajuHB0sFhwQO24sHxwVHBBfjWxrHBRsFJwdHcevjbgfmwmcFNglHBWcFYgpZGvtwFwdqCucEfYkXBc0ElwbSCZcHzinOUNcGVgg6C9cEdgo3BydxVwS3B3kFtwXXBrcF5wU3B2cEVwe3mPcHdweXB+cGDwR3Bo8HhCJ3BOcFDwbXBU8FjwcPBvcGFwSPB88GtweFOvdAvDneQ14FrwRFBwU7ritvBq8HJW

JnB+8HG7IfBm8EHwSvBp8HHwefBhuw3gXvBF8HsUJnB344ETsXBj8F7jm2aWPAnjg/B+E6vwceOt46fwe/Bv8GtwS/BCUH7xmqoWdwgIXKoYCEvMoEokCF4nHAe4QjgIdAh0dwIIQUQMCGganAhvtzIITdgSCFucuceydxicsay2CGqsoQhQnLEIbpypCGScuQh4nKUIQQheCE4IZVB+CFMstQhjCG0IUQhLCEkIWwhZCEcIRQhXCFUITwhNCHeQ

QwhHLLR3AFqROzCIZ/GrmLeQSIhuPjJ3FIhEiHhCLIhTUEKIXVBSiFiIXWBkiHiIYohGiHKIVohqiHtapohaiHyITohMiFGIeohBiG+3CohxiFmIXNBFiGmIXoh2iFWIRTSJiGGIQ4hzeBOIeYhbiHWIR4h9/ysIaaUJFhxciHqOCYhLjvOFK4namm6Z2ou8BdqdK7lAEYA5wCGQlHw2wBwAEYAkiDKAH0AtvDOAB2AcAC1ABwA8djFLi9C+yZlL

ptgoMB9UEwgWlRiJmxEeDTtwDpgJWDgLhwyHNDNMAgQHwhdLtDCqmxRINU47FBmUATqGC7wQvomB3Imriu6J3IWrgQuJMJELjauToB2rmQuDq5QpjdKTiZc6g9KriaQAPRCDsJC6l6u+y54pr6uhKYcLgGuJKYg8jLCoSahrnAAEa6U8jEmNtqU2gkm0iavLsXYzCDIMGxeGa46Qvvi6MrO6mh6/y75rkKmXurArmKmoK5cpgfiEK5B6jKmtXwOG

MHmWBq1wJu+rrLIulVI/VCroIUIIBiEIAmYtepYEJ40dzSsNiNghQjuWi7Aa6CPeukaGlraWGQcixBW9PnCguBMICXaPdCU9BqwdtZl1ulgXBB6IPggPqBKet+a3Djh5gnS6sAgSEBIQNpJFPXQv5A76oyiZSxbnjoMnP5DoIFwSzbrtBXB0eoc5jUIikApYHih1RpYMEVos3Y04PChVfChxH9A3Yh5GlRgkQiUcMQ8aZBNVplQ7piq8NVW/7gmY

L+YjiAi1AXaqg5G0pEa9r5GGmWQDMTrsDdgwqF1IpUhBKC1YOBuxrjCoOhI2tAMelJkK0T8ytyhcdZiklNIJBrmINsCLwoebpwsKBhmUDVGUgh1RuyBpqAYYMfEtUDgYPOUC7BD0J4kK7D3sCwoKIYqYOwoTHC9sJLwOZjwJL+wf8SHeBDGP/4zoOyOk06qYt6wrrp47Kmw7oF1EA2KFYiPxGHAvJ4xxPecmYosIEHQQS4CAEEhi0JfIZEuSuJFc

pEhJXLCBH7w5wBsAO6AxACC6ggAygD7AB+oXQDtAA+AzADpIWMAuSFA6qUu14IfQj6M99BKHO+Q0mgyPHS0M0gf0PcgBLj9VLcmwELrquDew8gfVBweES6zSshokPS0oKgwNeTKnvquuiZx4j0hoy5k6sCmq7qDIcTCyAjmJnMuYyGkLrImkyEAYb0EJeLHupAAp7p0LrzqVeJLIUwuqyG+Jmwuxy5BJh+6Qa5furwu+yECLo9yLVTCLvrqcPLg4

MJgx4DQyt3Eia6uPFPi/pKtLGkmma4O6n48vy65rs8hBSYFrm8hRa6RPB8hpa7fLuWuJHrSpmR6yMjxiEGIp+qLKAOB/jDMhEbWCDKQ0MU856ENwJehmaaU9IDInUJh0JABd7gRGurAR1rnIFq+3f595NPAUcjLYKzUICTg0OuwIPxyvlzUocJDdF5GXKQRkCphmG6byi8KEdAPoXRgyIj4AUphFmGLQFZhuDg2YenAIzikvhDgEaFe0F0mSYrtD

jywnQ4IUIKBi0Z3wGt49jZLeC0OD4bPUI1GVmLzeCf8jUZwVBD2aG7GLiSu3aH4Jr2hVK7K4rEu4yag2Ieo6NgwANcARgAtgHeoIwD4CLUAPK76AHeoVYA5gFaAbACQQBeobABWgIKu+SHroY3w0OTaDqcezIQjcjiA+6H5EIPqdsAHgOAuqxqUsFDgR0D9cE0hbNiiNPPYOwiTciZUgy7zut0hi7rGrmMu/SGTLp5U0y5Wrge6tq5AYRBhZ0rbY

dMhKKYbLuXiWy7urjsunq57LrimiGF+rpsh1VSBrmSmGGEjgNHwhyGfuoB6TTZlUEsOA1S52Jqu4wSyLsmuu+j35E0k8Hp3IcdqDyHL4k8hrupr4qTygK6muO8hZSafIWWuxHqGLpWuxK761GesTo5UVjxg6RoowB7g0TQpiGiQhtoYwE/QfjaqSMdgcRSGavB4kGa0hIBGtRjlirqwInrTENKg01CTmCPgNVBawAM2J27cOFdo1dAudh1QBX7R6

k/4AHADwK6h/574ZMl+PCKQEBHe9aI0rPbmbpg76qx+ZBAGKkmIa/b/uLHA4YYu9AJmaZAfOuWYtPwIGp08t0Cs0nogJ57bHozgUxobELNhppDc0jJm6ThE0HcuqIRm4bWesh5fgD5hjEB+YRzCHAKAwK2oDWS9QDyBfZhIiGM897DS5FTitpAJYdUOp3DlsJNmYeHe7BHh0wRR4ZHGMeGjmkt4pZiCqFTUnuCNRhtG1Dzh0GgaASFpYQdqwSGZY

WEh0S4RITlhUSESANgA5VRDACeQQwB+8OoAuwD6AOjYTQAbAPQAGwC4AHeo2AAtYWuhtuKN8F5sj5wC9jtuYiZ9YUcgQYiDYWZqkACnoYIQ81YymvWOXhjqrrehwEKPIP7gPQpCYE+CvyZLYf8m2C59IUYmeC4mJr+h+tgHYQFUcKaXSo6uqy7OrpzqqKYnYYlU9C786gZo8GFXYYcuGyEnLmaA92FgynshT2FYYUimQi7XLnhhNECVQHDqe0DEY

XGupGEYpMXYit6dnv/htyG6wvchOa4u6nkmburr4kxhUchw4TouCOEcYUjhkK6o4QCKRCCq5LGuSqBCYbmksqhLcBtgEyAu4eQobuENRj0mgSF54T2hSi59oem6JCa0riVyJYANgEIA7QBQALUA0fBHABwAuwDCBJBAVYCVAPgIUAAI2E0AwhEd4XwmbWHgej+E2n7MhGigCgFSrk/4GHQjrqFGtRDgLpysFUCpNJd4wUCTYctKAaTlIJhw4Lyju

gjCC2EGrmvhWC4rYZ+hpq7foRthlq7DIdau2eI7YXniwGFH4VMhYGG3SnthUGFurgsh7iZwYSshd+HrIewuj+Gh2NshAMrkpm1Kf7q4YQB6ty7DYO7gisKhaD3wRQ4vLujyU+IK3GZuXy7ZrnRhMBGQAPkm8BGvIYgRLGGU8rouXyGcYcjh3GFVrs7CwQHBGoEgszCgPg7ySvjqwGIUGuBBpJgW6hFVETvq+2S1EXoRakBlUCQRO1RkET4u2tp/e

MJIJ5DjhjzWnaHBJNvO1BHfLrQR4SGZuvEuEAAbABeorCaSAFaAVYCaALUAuwCQQDAAVoDOAJgAR6h1Su6AzgB+8KIRb0LiESaI+44LIHhwokCUaHuhghggCgGQyUAgwj+CJcDywQ2Uyix4PHPh7OjIeE0gnnBLUP1Uq+HM6osk6+FmEYSk5OoTLtvhP6EZ4rYR10oH4fauThGgYeI84GE0LrMhLiaswh6u3hGXYSwufhHIYZwuqGEPYSGuI4CkA

O/hrGjUpn5oNEB95AsgA4FfYZMEn0YJEX9hxdgNIKkG2VZe8OkmNGHIejymOSZYyi8hnuq5ERoI2i7WwiyR4K6B6uykfyHI1HuqgXCVXh1QW3YODsPQ8264IF5Ap+LX9DwglRo0IL1+z9iUMLaoVRHzXPzhOuCEHmfApqSycN0avSAWYjkwhpBQ9g7UbojuyHFWiuCIWuVAiJozoMKYX2DqGvng+RAvbh/MpQhtuJ+ay4ipQMN+GcJuTAlaN3oih

KT41uowlobAXBCDGDp8T/iGKJSelz43PmfgzNSN7o5GJprHgBlBUZGdXn2cYgx1YCwqm2BX0H0ayl7O9GDAq1hUYOmgz14e0iu8XJiLxM8grtYm5LdaLnovCCw+lUxYUABwSyip3pKRMOYf5oaQJp4lBsKegHzODi7kbWAl+ksIGVBzTFZsGXoNwAWQmbAYDu76JVpA4JaiOGAOeLH2ovIp5lTAPHYweDQgicIUmnJmEfY4xACSFOBFNkgkUBCBU

LvACgoCAvlGBTLg0JHa10DtIbOwxR4Lwp3Ai0CX0AnBcyDDOL90hzQmkbjudXjgyILu5YqFihPmnMivUBREnuCKWgcghFDh4Hhu1rbsWIEQCnThwCGabJ5SNnagg0hG5mHgRr5eGBpIPe6XrNcoZKKxIv/qkzZ5tC20V+pMwBqKLLAmzLwgBLgwFkvS61CvEJZglB7uQF4QNLh1FnFgEWFaIPq4YepUEK38fB6nLGgwMjjGYJ+g99a08FzA13A5/

khszh6nmMHm16HvfNhsjvyDPjqQDnj81PWeXOCd0KVu9RGDepeM/OElyOBg3CDRuB36GJY8YM18xDQ2MJaq2wIIqp8MU4ZmFrcwhH77qiMBTJqpIIwwdKp9GsaIRNDTZiLaEpa1yMgiGxh0YngRouC2wJcQeUA1bNxeBgq8Ej/qfggKhmTAJWCLlkrWn+hIblb0cmD7PuwWoPr3ENNQlyAePo72W4ipqsOiUjBnlINQp8L9CGBw7yA8SE8i+gGk7

vV8sZCcDi3gOWQpMCqI0VAsKhmQi3DkkBsgk67ayKNAzzS4IEhIn4BASPIQKFqjkPggDFG2sFNItFonXviw8OhZVl9gygZEfrEwUGDmECE2GkhUUWIYINS9RAEQyUimDq1kN0CiQMwgqh7/uLgqBHCLlocyz9iK4E7iHDAYENbA+UKGMgdwPRgL6s6SYWA2UHWm3FaapggkeJiSGvvgp1FFtMoWeUjooWLUN7AmiCoe4SDCYPChI+bfINtIPHBUU

TjghZCQxhVW/mZR6uOI1rzgyCFYPXB0dAxQ9DAScAwwGdiYocIiw8CmDIRil/7lhPS0LLgkFrk41V6RFNyejDJdyKxwWpH+Ep7EUcxBeMdgGbDtUIgQfepl3psKY2yKQCPmo5Dn6kwG3MBAhMiyvIbxUql6BpgLvgzEFNGdEOCiY5AKpBtECkCrSmNRgMDHYJ3eDjB+wISoFMSFQE7WV6FJ4M/qHkj5sHCgTubtiAh0eqDX1vUKdIjM0Svgcop9B

rVAOG4BhEFAoMgjgqwUAV5boK6wIBqkorOICHSKYCpgwUAREP+gcKJ4Zs2gk3KP0gh0SciHcBQ0o6YTWvS08cDKGvca7gitCL3WBqQScL02G+CCcN3q/lZ7Brn84eAM0ft6raAS0RjqUtGRGM6h0EQgxPDI+DL/0HnQx2C1QOdIQiB5kujRFrSm4LO4XXbKFML2JMDI0QTRTmw5QBCKb1G2pI7g5nQReuxERBEnfEBsKlHbQHyU2hAMmm3sTqB6h

HogyprpOMXRxspLDFHIwCLW4NX2F1DisOC+V+K+3iFgXcTXyHIsIwjwoYEowbo81K/e2CpA0vn+faATQPFQYcA2ivQQRxik1gyQQhS5FrRwpgQxptBCBOSs5itR/OHy0vOeicABIsKh9ViJKPG2GAb4USRMkuamUYEogPirrhCy20g5QHl6zIH9qgHkDtDa5PYOkxBsKpnqTVFF/LhuImRtoHDeshDHzPeu08CJQVRRhZ4rwKR+q8DUDnJ47hJVQ

OngCcB1kacI7uSFQODCMlQhfhzgKRqoUODgG2ByZp0RapA5ZBGRW1DGYHoOzUC5TILgCgr4cEhkboi6rvRI08B96pFkDVqempJAaPBrCAqWsojpOHwQPB7I5nweOUyDEd5ggJREbrRQZb567A4gem7iti4obcD/mlzgj94Z1qkgOb6n4EgkIZqqoRRQQSADpKCWipAioKoxmAQHwpEQ2lCBUOLoIhboDOdI5RTvSG2MzfrCsJVAFow79lgwRhC4O

Bumfz4YdkeeVIzVYH0ghBY0/uNRuSjKrLqIByAYPqLAcDro5hukCO4vrthAHmYbIIvuiXCx9oiGE2BdkOa8OsAMxOfCK1FAUGuS8RGMUdgQvFGHLB+w/OG8iNbs/giQgbjRdVLVdBrulDAHyFA+vIhXEInQNorjEDuR7XiJwKTRI2D63kCGXuKk5rZGvTHPQFcOOWb8VmIi6ATehK7AdT5X5mUQnyBzXnwgVDLBwKQG+RD1IO3AnPaNIE2oWCD3a

GsxtsB+QINhCpDRtvlQrdBAwtDwuazpRJOGOphAOnbm2Br50TbKo96UCs90CpAwhN4QRd4REPqo7NHDhsYyMsRBiEOIkGZG5hC47ihqQOXg5z6sYH1AqcAjeOghLcIkgAS4yBrUcMyEiTJwsH2RrfbKEZM23zEsIu1QRwjPeuhonaa8UIEoV5bYsREQuLG+URKMzMgeFvpmWdGcNqpIqkhHQJeQlGBZvEpUMuhO4KGw6rZSYBoRMoG/4C8xkqy4F

pz6AkZSYST2UvwUUFQgXOBHZPiAHDHdTOBgnLEJZu2IRdS8sUT+qhI1WEns90xysXAgUCa5bie8POaAFL0QpnrZhk1I0N4Pou6Yn9HPZIQMvXpX2JAxskQsIj8xSkx4saRQ9tBq5L1cuXScNqCx93oF9LT+0RgL0Zo01LBYQIPIiTb2QO4BhqEf4MrmqPrfSDgQIQhottIRg8CBUKHoyubfIMQoNjDU0dc2chD6Hv+g4KLOfmb69hgfNOFAM9Ddb

vlEPsB9UFoQRfCXENssmCBtIFdebzbxbLOGBuSzeKkYb4JsELOYRpgCiCU+Y0iXhqZ6s8AW5h3AkZBNoLlSbbG8IB2xY6hdsS7mTOAMMG7AsMIJVrjonugTQAlSje4idPB4dRaTODva6MSJhHq+B3z63mkSUBAStNgwinrCBrVg1LazMPYgcQGOUIaWT+bN5p0sWj7A7MC4IUBF8H4sWUDnsdp4gOBXsaWEN7EQYH4+LIGdJr0y3SZ5DuHhg3Sx4

bhi88QEYuuITsRzcCOwAsyigftwEw5twBDsOLBQ7K86tGKIxuvBVBCfDkmwXjoHOtoCRzp6ApC6rHDwuqq6gI5JchGwtrq4jhmBIsYbIhmBOYHXAj0UUFTmQXDBn+TjQT1BlmI2Ib2YjByzFKBmvZj84mT4u5hhYvuYnYHrFJT4mxSvmP4CCsF6wekCgo6ZAlsCxs5M7IbO9c7BzrBUgILpcEFOecH6gqTOOk6hjmJOpk4GTuZOmnEZjtpxFqQMT

vmO9E6WTghUJE5IVPLsp4FfYsZxazJPqjSOhnHWTieBdk7HgeZxjnFmcVROLnFy7G5x1exOcZ5x9nHOcdXsBnFWTnxOXsbdcMpxmXDrgUCCm4F6jk7GbOymzitAS4GScfZw0nEccPHBZQIp+CKO/I6+Ic/4q2KjgXiOvWj9zvI+4QJDgc1iiJSTzqVifWLlYr1iv3oVcWVxVXENYuPOxWKlcXViDXHQlE1xNWKNcbawJXEtcR1xE85dcfVxbXG9c

VOuPXG+zp1xw3FDcdVi5XF1cYNxzXGjcdNx43G1ce1xfXETcQtxU3H9cTNxq3FzcTBYy3Fd0bNxFWLzcQNx23Hrcbtxm3H7cci6h3GVccdxa3FLcSdxI3EbcVViR3F3cedxD3E1cRdxt3H9Yo9xb3HPcU9xrXFXcZdxe3G/cS9x93Efcd9xf3GvcdVxwPEA8e9xYPGDgR1iPWJjYjDxE2JzYt3OC2JygcChSPHbYl3OynCdzkdipgJYjvtisYGHY

njx/YJxgdqUx2LE8aAEAARWlGKONpSijrTshQIx+Lr4jM6pcYMC9sbzgczx7M5RlFvOfSb54TQRWWEDoSXhJXL0QLbwguojADKAtQAPgMHwWSFDAAgAbAB+8M4AKuqXALbwRxE9chAAN4IlwKtkNsDcpFegVxE+gIO0okTkzJccY+Hm2DvkVZx/Wo7SgS6DJOO62hGEOKaBX8j7HPNhS0rGEf8RmMLLYb0hq2Fb4aCmO+EQkfvhIVSLLiBhoyEuE

TMh5+Hc6pfhMGEMLgLqt+EYkQSm/hEoYaSmL+HkpjkAVKbhEVGuaAA1bEnQOrqUkQpCiSZAERjyP6YHWnQIWkLUYUh6WSZskX8ukOECpgoIORHqHCUmxa5sYTbCISFFEegRqWHOwlyGn+gFmOJA5vGTENbxBlC28dva3RHJmL0RRK6pYQRU6WHkrgXhRCbUrjEuDBFZupIA+gBsEX7w+AAbJtHwPAAPgFWA+AB+8EW6zADo2ILq4SZK8V1Kt4Lq8

ZUgnfSkxgAu0Dz9wHrxJaD2IFsciq42BIeiocBJBg50yiZz4aTAo9DPNrhxycidIUMuJhEjLqskOC4U6mCRVhFDIX+hIyF2EYBhDhF7Yfu6Ky6HYS6uSJHQYdsusGFfchHxPq5R8ViRWyFcLriR4PK/oUSRSfEkkYVo6B6YwIyRaPKxEQLYotgXIXFoPwDxllRhIOEhIWDhvKZE8nmujGGV8f1Uoqbw4exhekIN8b8hPGHN8dqwaiDvIO3xBZpWC

F3xA5jvEApActTEUCVRuFx5ejvaS9g4DBmQyfQ8vggSTKKPDj6c69ASnuR0p8hyhqS+W8L8ek5MDRT6dtKg5si5WGFBrHDI2pASh+ZkjN6qlmB0bh46H4ABEOuwrWyQgdgCqWDPLDlkjxbCsCy4iNZM1kGkwZxg0J36jdo0Fh/AFxjcwIKoLBq6ZOBgWDH3wSr6czxEOuE2sxqdPBjg4FHWwNFmFZausFIQvwoloL7eReT5fOcIfXC3vs/6H3hnD

P6kTRBPIrAuR6BPQHcwQu7noaPmkaD+QEJ4VUAQ+k2+SO5h5tvm8OChnFEWWl7K0XXAGqxQhlB2EbyieKHgYUGjZvCgNUBmrOdIRf7TRHXgu+jxmKSgHmZZoXlAoxqk4aTec2ZvkH+uuFCUvFjeyfTYgR++sZhJRpFSPXBI7msxfRBtsIO+4natCBLSzAxSLCAxs5Dphiy4eh6mBOYGO0DK9vgg8GD/dqIYX0iQPnrguQnSPtNeyAJQhkYBb6ARO

EKw+FL0sXC+3LYlWj5g5DrPepNMUF5nCVKE5gZInmdwyh6d0P5uraDDkOM2L57OBrUqQvaQzBnMLLGyyOKsT/5KQH4Gy1ShsOaegDBM5qWg9xrIshyIPJjnPI4wVHB46N6RqX5TvMrhcNJeYDSJCeaP9JWW3aYcrPzMUoRkOhDRF9pTuqzRGCqxCRj+txDjQEDSEJjEvia4ZNroSM5WKB4JzL2SQtY6UIoId+7sRPImeQhC0aRQNiCdwMjErzbxb

sEijog8EMKg9Iz18lpsu3AqYeogdL6mIO2IM0h2oJjkVWDCYKjQDeDrXuy4i1C3kTIefwlDfN0Yd2j3Zhi+E4xdrjxQfsDSzCOsYcDqwPHK4yCFXo4IQ8BA7JXCROSkEv1QFcQ3ltOGbiDWvLZQw7peiaiYXODQeEsg7uAgodSIcdRvRD3gl9QB5gDwYxAeGqhgpr4HiOgxKmAD8l6JzFCsVo5go2DeQHiG6OQmwO+Q+bTK5mda6wqj/OzgqhIuW

HaJBb4S5vrMgjpNsQBgbQbV8MiyJPpfCmaJbPDaTENRlJ6nrN8E66DFZET+UNZISDGwLmYd8fCYtIwB5HcKjxg85qiUF/RgILSgi4mS5l5R2mD3ClNRcoTvMbmqOKQX2k8gKFGexFQMU1EwuLVuFDJKYHCJ6RiSJg0gLVFnkLCGTUaIEEtw6dZSrLSIs+j+XhQOSbxvCfOReBCi5vcJImFEUDecLwmajN2gxPpaUOoWz9qnCUIeT3BL6IkykyB6m

sAGfXAlPjsJ6hbusIRQO3pLUNZAKOYhznMgd3RkscC48LTs+qle6KDssLI2NR6GNt7y5SBWbgDMy1LIXplBOVZIIBiy6qzMgH6+tUijrm1gpu4lPvp0RpZHCHJwYiKzsN7grqBhhE/6k0iL0HkxTdDeYJS8ZjDxGqS+5HaEBnZsXyC6IJoG7TGwYMXaaElxjGm2jLDabpfxIFDtMWn8wkgUWM9UBBjbfogQ1TSvEFmwnoo1mM1s0pyy7t6aUei4M

P/+O0xHEMj4NOAmZkLus4y6QHyUzbR2MaHsjtDwZq7+HyCQ6vkKJohdSCGaP8yO0ef02Yb6mJMCH1GqQMV62lYSPjfAGwb1hug85qaqIGaxm4w0GHQScspl/jx2zMSe9vxhNQkBeHyq5SDtejj6NW7SoeaeEhhyZhYsedqAmu5RYSB6vo+CnWjJRp2qADA0SJQYa5IiFuaw5A4jImPgGXoOThVAYwrUPH7aIGb74I8O6qrFkSEGSPAU5PDyktZWQ

NYJmQjrboaq3UArURzeccT7SVjaD4Y/bpEIfB5cNIH2DYY6YHShMUiylKmqY3B+zipR6YYp9KBIODCehqwq4yCFmEXaNIZf0dCEoSg5cClJ165heIxwbTFsEJ4qDjT3EQiGvmZ4LIsgsglsUPIJKmwIEAlAKVpcDvUITQY6EJGg6vx3iFn8YxgBHmjAztBWbBAw/Ig81jRm70mMGomgkuKHEFow33rvkNX+/OHmLHgYUZYGUHdUbnDm1mLAEERE/

i7K00jd6lVALi7TsH9AVRESMlxgy0DysJzg/uihWl7AYMCe4G6kDcwn0bD0ADEJhMAxYNFxmJLeVmA7Ar7eKiKGoer6sEwIPkXgD1REotZI2bZapCghH5jfnDoEafYBoNLUNfQFegQUvt5lbNfIicIWyvRQMBBZuLSgD/rDooi0WcQHQFKgR3QtkQGg5rBoMBA4ooSpFoBE5zw4YNSw1mJbCYUY5DjGhnrJqERmrHTICCDX4MpmjLAMMBQU5FLJP

pr86+jF+mqYae4BoLQxDGBV8FhmG0RHBuWgocBx7rl6zliFqspQq1EBNPfIC0iZ4Jke8s7eQnjJYvp+5l7Wb1IDpJQ+WRLPSUVIRJBSiIjRWTD9ybV8yoxJ/NhUzaBp/oDRrsBO1pQSWlAn2KFwR76VwuFAfQFFSGKWwbz3IH/2VFH2NIfxbGAsIHKh1whmlPlRF3510WtRQxio5s6mIO7XCEPAbHqX0QOuXBAT1FAQXxTHkPsIr0k1dOdIGfhPy

phwewhz1lGReGBlpMEYdpi8NqxMS0BppC7ABkh5+DjoN7g1oE2mKTCqyRYKxuA4HsNyflpW/os8k0wQknC4+vSesCHA1d7EKBqIFMBJUCZY1ZAhtoCGsRDv1Ntw5EwaiAfIxsA3uLrKGDGrkOlgQhhjcADw00lRQKOQZxgrwCpRO8oRiMWoamz2yXcgTaCyGLdJ1oRcMR+RAOGiAUJu01LNiuHmDrB9eOweUFLmXgWxDfriCS7ARDp14IpaeypwS

OaeFeAf1u2Q4EkfQEaYXWZC2ESQ/Z6I/pXouShfYGVJePQHwueug65kGgXaeQkOcAUJN4hvkYi8xBbkBHaofdG9wnvA5insSFEg/N6x6ARhzmbp4PLJskQRSXFRDtClXnFmTmwtEkLoctp9NhD8hAzvsToQawnUOsNs01C27v6we7ZQEH30YiKyluGQ+kDmxIQGp7AKZPpAbnBVbkwKgFDiSQnQobTQBgZJcry2vkZmv8JHCAEQ2hC3nIQGTgkDr

lMJI5ZCvB1GxFE4dgQJtEmf2Ffk78Cprh02OjKwTM22+V65CSWEYUa7GpfS+t5hoJ0ar8jl4F9kU7EMUOI64p7rbokymYgFDqjQHDDCBhiwVRGs4LgQ0Po+HnnSbFAbBto489j2diNuLLEi0P7AxqEhQHC+70iAsQmYlqgssYlCEFiVhMHeO4mPiRCyraCLDkzmUmbEKCBIYsY7iWOQF4lmBMDJAqxOzKXYC2iiKdiYeojgMHgE4fw0jC6QQjDLd

s4wF9riFs8aRWYZsHL6qlR8GERQ8lCuiZOJbRRucHwYh4nyVtS+uIDH7os81Lg7UdZ22omd4F12k6YWYW0G9xDY0PdBqWD84ZY0djyxYBFIQ16IiNASyuChDkT+ZhQ3pqQQQDEhhjgYKlpZMQradQHzYFHWfUAgDJGeWnw4YHuQEKEH0YHMUshR0fb6n+46INF4JMjAUkAKa6CMgZFS28kv2hFCvIa7kODQ2yztulngt0iV0RKg7RCt8dS0dYnxi

Qe0NQLMhClB8B6zYc+u4wEfsasM7NAA8BwQHIrThotQ/BQ10IJ0AeY3OPcQjTAWENOGig5K4LMwYNAUsTzIIgyvjBmGaUBrhtpgg0A3juCMcuTKhIYy1lQqkZKeGcDK9N8wY7TPXmkSs5ifIAlogITwKU8eZNjS2PTYPsD3sYkJ3CBhbDPQIEbiofeR9gQumF2SnablmKtkgl4YcIy+0pqdtEXmM0F4GFZJ9cb4nijUbsRhBlrA89E5nsDsqgpGm

DXaNYjPYNLwhWarHtoURKqB4L5AyDCvnq6I3/wAyb/AUO4HiCV+s6AqOMlmGH5VfImE/nBQPsVQ4NDaMeDCrDIifgPmNhox0i3gKO5AMT7aJDBNyEeS/rBeMXk4bQloFCNQH/oOAftmM56ffFqWwRpkEM3kWsyVSM4wMDARHpZgnMjCbM1wQ1rlwqhk+LCDGDCctb53vmhpUSAYaQ2e28rk0MPe9ChFHjee71xZGkwgz15gTEC+JIm5ZCbhFkj0f

hfxuFybOFRRddTUAqkGVDByftdg+VDVNBjoje7GWql6DeDkkMCpEqDzYKs0SOQoUY3erNBJRFjaaIEDSp5+NdB8kPQsCLK+7lamHuBRQKp02X55pDRuPH6nYCbQ6yDe7k4o2pDZfmoRocDRTFjc4e6tyv1QtwbnSOzgpyyd0BHQN8zY0NTQfmkS6F584vrnUACYMv5NEDI4CSkfiDUehlSRoAUi+QYjNs0QBhRdSG+A5Ab2aZowY9EaNkLIc/b1m

mz24dAkaafRbIzFRsea9pD7fq/A2qkpiuMQz16LtI8BTmCdBteqT8Bt0kgeIaSPoNUWXDZlaU1wFWkRacQQ1+RLVrcIXomxGpggu0AssLXAf369kJSix1h/iQbSzjjcSOtA4MhCvkLIhWQANJVAcDCDbqfRCSD8tDzWlyD5BoRGK3TE+i/+BtLjZLPaZVDNQOMpFkg0RNbg5Nit9H+iE8CcOG4qdPSTaV4xt2msFL3uYyBriHkIWPqTaZgECdKva

A4QE+7g1OtJVNGscJNprZY1YFt6TrDrForMY+CPJkngSP6wEDtJ5WBimjDp3kCiwJXCGWaIhv6IO3DyOOwpkalbaeDU+KBRXu4SiOnfYOhwX5QdKQCW3sA2UBrA1G5EbmEBCfqwNPvgH2kMKLSYp2Ce4Yjp4hjilk8JEnBA6cJI5L7xoeawkv5lNC9gCRpueoToseg8fr1ACFCyNrWMS4p38cix+K6sgYmK7uGNRrc6EZC0DtURng5JYZXgKWETs

FFhGQrwAQ10evilsM4Otz7zsHbEJaDrGnX+XqDJxGlyacTZitTcuYrMoId4hASmgcWK18RaxFcOI8RvsGJwMlRrRtAksgKwJNSROiSWJCLi0MbAcEhx1Lregf06LTo4xuUU1Lp+gdDwLzqEur8O+Lp03hS6ArpUumCOIsjQjtiOOXFwcASOZPFKYgFxbBZloWvOnI6pgSjiK8akccvG5HF5gSgmskGg+BLGx76FgfYCZYG0ca8680ETQUxxXiHMc

DMUPmK5cfxw3/K8cWsUAFgbFPeYco6ncT9xcFijihqOms4zgVuBi8F1gsPBKnH0zlTO5oIBghvpZM6Uzrvp1M6/lBaOD5SXlHuBx+m+gnvp5+kH6RGCBYLFguTO++lb6dfpJYK36RfpNM436Zvp4YIPqjvpl+kP6Z/pb+nL6bWC3OIr6YAZABkwgqCCfOzQggsyYBlwghAZmoLhcYpxAIJwGf8CLwK10HVeWc6fAjnOanArgbbK8c5FztgZyc6ro

LHOBc69mFgZ9wJxcLgZpBmFzinOeBlkGVQZFBnEGeQZSc40GQQZ+c4lziQZjBlRcdFw4c7VlJ0Rtc6+cLJxvBncGUawDs6CGQ3OfBk2zjRJltBNzr7OBZT8ztXOPBnCGXIZQhkBztbO/s62zioZNc4KGYHO8hnKGaHO4hl1znoZfBmVzu2UjsacGVXOHBmcxsYZ5hllztcCHOzMGauB+BmJwiwZOBm0GewZxBnoGagZmBnuGQOUyBlPAmgZGc4YG

T4Zmc6DlIgZb2JuGf4ZHhmBGQEZz2Lv0D2CkXGwGS9iEXFKcW7G8IKQGZCC4BnLMrzs0BkZGWvpwBmdgt/pH+lZgk/p7+mxgrmCL+nb6X/p+RklGUaOdM4VGa/pRRn36QUZ1XAQkMJOQXFcTmpxok56ThZOtE4mcUeBrnG2Tl5xGzLBWOmuZ4HYVBeBiR4BxtLUvk5BTgFOkVjTGf9igU5x7EfBkU7+TnfBt4G5TqjOMM7rGfjOaM54zveBOxmpW

ClO76qPgRlORxk9TjFOW04LThdON07nTtdO/U4vTh1OE06V6W+B8+yDrovsycZIcphywXIosJ0Upe71oW/QKmq6avJqJmqWaugmYkFvMONq6moAJmGcTTAoxr/GQDDAJhJBZqxSQQiZkZySQeag4CZxnF8aUCYYmaAwWJkQMDiZt+YoOPiZwCYQJniZadxi3i2msCZpnC/GImoAsGh+DzDAmXJqokFfxo5qdiFrartqDzBQmbdS/8YhnHCZ4Zywm

YAm8Jm6MCAmSJnomXBynxm3xr5yAXIXxpRB8UrUQZCojEGZsIicdOInxtS6NekN6RQRueHjERlhPPGF4RPxxeFT8bMR1wB7goQAhAD0AE0AmADo2JoA1wC28BQAnYCVABkAQgDnACMA7oC78U26YcDbUIDAbqQnXmImklRJOjZaXcGngKehGnZYBpVIRjSdtFoRUwS4FhYQ4Pb59tseL6GGro5UrvHmEWth//G7JIAJe+GQCdCREyGwkf7x8JGuE

YiRQfFzISiR52FokTimkfFIYf6ud2FBEecuj2Gz8YSROGFf4RERNEDmFOCOoHpECbwAFwCsptB67uA0INEpoNjMkUXx3KZO6uDhfKZl8QCuCBFV8cwJyBGsCcTKaBEcCaURS3QFEALwgCibypzehxAE5IC0vIZEUFRRQmSvwOCJ50hovrrR/pCK8D3+n7yZElQwYbBQkKhQx2CZSP+EjFhQPlc4jDAGaWCE7rAU0b1AO255MQJmVEgrQGcMBn6cP

l1AJ5l/eHw0rxBcEFyYsEQ2wL7pweAWOmx6rbo3QDT0oCA52gtgMKExpr38+Aql9CwqGHCcvn36LgmHEKkGEcBk8D7AtJBIbpuanrinHnX+RUjo6cUxwKC9DPrJLcz36A5JtUnGimEyme6pUl6xqyqCmYWYwJDZmDMIYeo6DIAGacAZeqHsYMD1IhNkLDEiILzenwi1Hg54VF6oUL90pdGJiIRc6j63SXJmEVah4Di+w6lXiE8pHUb2EqeuTiJt0

EtaJ0Ecbsiy45w1QCTIxZGRDBzKhaqjLDvaGzQpQJRkzf5mINtmkwybyMPIwRgS+uLSBmm49BfuCZovmlA2WhClHir6nlhu2gDgGBB1KfCI+6SO5uUggDAFXir64J4l0ATkXPQWKcQ8wrAttG0OQfrSoCyw1DDVQO1+m6D/BFqSnSTu4I/2DmGBIOTYQaB9eCGwFGyVSDc4c/4rRJq+51blUSpRKyzaTErQZTrY6eeaB+Z5hvCgilqQYJ0GlDB8k

EjJjgjpGFbMnki5WdiI8UCHCIlBFlQ8+rVI2Q4OGFx2B6wfYOomEkhJWFIJeoj1sZgg6CTnIB5m4zZbRkZuEYHm2jIg+bDt6sLo9l7lSMHWgDDW0O5RUMgbWZOsSxRDMa4ULhBKoAuQroFFSPuw5pgY3n5AQzE3GhwSZtLc0f/iKoiK5sq+TICI5jyQ0jY3adLwz9o3WcQgm1lJFMdpVwn/7kE639QY4Er0R1lCMGugI67GMv4gN2kRlhtgMwho2

RH+ompUARoYu8LL1FWSd4r/4p0QH1lbWfDZWTh/ZHIKhtDBpod6xuAiYLOs4Xq7cM96ZanVKaogr1k44O9ZhRQ02esphBgKsGAp7341Lkh4lGA+puoWgYgJUMiJHPpUcGcJWsn//JqiGM5YyHLZGASH6NO2weDK2ZzY/VnEKH3xTkID8Udsw6incDKBrRTZoeG6Dul2XJGwbbBbquc6pmIrQQNB7Oycca2BvZixYi+QxxSA8VDxFJRDzijxevh3E

lRYOo4ycQYZkRkRGaAZaRlZGQLs1RlWjtJOGnH6cVpO7E70joFxvRkecf0Zzk4OTq5OwxnKsDMZgOIJWKsZyzJQzsTOeXCvgRWhU8b/qvBBJBxkcfQcfxzfHFCcWEGI8kmoTOK1qKTixEEM4rBKwEowahpKaUrkmLRBV8aEsoLgerJecskobrK+soSwRGqksHJBkSh0nItYbcTFoTpQpaGamcPxVBE6mZMRvPEZuoOhWbr4CO6A1wAPQkIAiQDMJ

vwR+AhNAEMAs6g7Ee6ALYAtgBsAbpllLlbg6CkWyYPI/4i+mfryGBak+kXB1/HSkhrAwGLF5Bg2FvGvJtMBzETqQop4zNh/EfhCAJGmEcmZwJFfoQMhAAm74f+heZlO8edKjhEIOd7xxeIFmesukGGbLiHxcAlh8TfhPhEVmTdhAREa6nHxdZlCAC9haGExJhemdKC/YUymUmj0uhnxGPImwDRZUeipEY5CNAnskfQJ2RFckVOZvJEbVHXxhRHzm

UKRnAlLdDlmZpCeYrPiC+ruRGWghsQkMje+9i5eQLLAIVFkKTS2f2DMoA16pKDVCq7JCJgkEH1EAnDi2cZICJASehgECRpeiXzZdRrBybhgBphoiEKaOLgLeCFABtlRoT+xng4Z4UuMG+R6xBuwRnqEYo1G85z8gcPWoxGkrllKybpj8cMm+pkzEXlh5QAXqEIAfQAIAH0AnYA5gBsAMADBQCMAzgD0AMHwkgDugEVUpDkroXsmneG9cmzYvSRRZ

I38n9AKrjRCz9li7p/ob9mnod/OLPgfXo6Gs+GW8agAEIBXhvVE3WF0oQmZX/FGrhA5+kIgkWauHlTpmbA5wAlQkT7xh+HIOVmZ+ZmB8cdhwfHnumdh8AmMLng5SAmVmbdhejzP4aDy5KZCAA2Zn+GRrjgJPfDTvJDgCSbXofQ5U+IpIDhcfp5MkYXxUBHpERDhsBFQ4Zh6MOHckX3YPDn4enw5iOE/IYI5i5nTyWxI2phyifLUd1T0MNzkc9L8y

I3ufNlj4DtAHBocOFHqlgqAhFkJBHi5vvx0OrghyYWEUtDM2cyECLCF1pt8+D7JNKTEc6SK4eHAt2izrMGsBbDVRne47Zb6IJLZvCASOfuOT9r5oNUifB5BMi1G61DRULl6PaTNoBhZ/7jnrPoBTEx4EarQLHQ3wKLIbFDw6Nh2DMToAcKhykae4COQZJ6HIJAqnTLumMzgptFpkJO2flLCsFkprEy8UG8K5hDMTBYaCX5AwmdgbDTRyasqnVrqI

N1aOLCXwHZEhwjSuR2JXokPQEnQvkAekhQ02OFV0AvISmA3PkOuglG0Ml+pXjECYOe2qp6IWPV8ilr+ppEQU0DoqYvqIgbTwB+21hghmncOFGgloKWgRbj3PsvAqlqcyPZePczcwLxQpOBLkd0iIFD8Bo5uSb52ih64R6AlCUGxqtIYcBwQZKCH2kMxat6fURjOq+Ds0hIqmVKARq/A6TFMqiUg7ZoTWkGsAZj6jI4wPlmr6FlA5SlqoZBaEXoXU

CVRsZBpppuWJYyGkQA4KIgbGG0KJobZ5phwnwCEvIK4r+gUFBhIK9Jq5qpIKJDBrJS8yUDlkasG49GfUriEtVFpWs1AYiL5fFt6JUZ5YJih42ToMaDMBhhrMQnSIV7SICHkc1KrON4BS2neYWeQmhBH2DDeuvRqDGlEhGkW2pdYVm7JQEIplSBghnIyJrmnOJakgPjGMuDiZGhmkAjwLjKtynyQobBsXH6++njUcB/QaO6hoPaEDejMZvlI/OFN8

NhaLMjBhno5b6CHKsZMAXR21LiJbiCCoD8A1JZcIiDEwpCKvtSgnP4CCZrpQKD9UI4edlImuA4IP4Z14OFZGFB59EDaL5H3tKYSDQiyYMi8NlA85q8QvBK/QNDaGUCwYJb8H+LIiC3+VQirwAIxjtEFmq281XhSWDJeIqn6fJgg4vy4mOka55DIXCjZu3wSQG1uLLCRICHo/EkJCt+SjkAElpbKyub+6Bm5dUyBWYC4chCqARxM3VlXGEwMQSkMg

YBgTuQY4NygS+hsRu3yn7AAudN+jTHfVv6wAdwtiq6w2ywYMlIw48zsmtdkYXRrPl8Qe9Zf8s8GXrxcFIBSZ1FGNulE+swW5hdRMa5ZCCZB12T5SIXRBz6SeaOxPUAMSO1Qo7AIZn7gVSAXBq1AjvqWRNusK6kwga0Ying5Fug2gUmRmMzI5eCX8e/gC+qC2PKQkrAWIL/QS6nUWGK5htF2Ir1oVvSrZOVwnbmhFELAw7HjeiZiyuSd4AJECm64E

FQp1Jj2dKiJ8hDSEQhm2GDJASS5DLjXpKWk51qdSLkUr1lS5BiqQnC7cKJez8giDDNIDTaBKJyhRkwcMLC2sdCxadvKoqxS+n+WpJp1ohnYyyi6gdUQOBZr/LD6LSzbie5gMlqpYNgOdRBdUMVgVDimkMSY6GpjysWItwhwENNQeamrUIbeZaRnFKoBXgrndNVAOPixelX6+rzqZj9IUeojDETRSXQWecoQZ/QDNhY2AV4aUL2xiSBXegLgdVDpU

CA47dogJPABDUDYuDz5XjIiEEP6yMmYwNtSEzadYMPmXBSzoKeJSNBXOFNCt/Ip2ijgBaqQYGc0TKkW7gzEEGDNZoSJsdT3yKogBQH8khZRH4g7mn+pmFa8UIHAS7wUkCEiofp2aaHo0+Cf0LWgDPmv0jFZiGSiMcFpXTzB9glMrQbhZKT0aBDQ3rek/HmC0CM2JAZEiMLp4WRK/MIpGOCM4ZlphBHoiHPa5yBOCowggoTebqrwnWld6AMIaGAbE

IHAPUTNcARpcRgmXm8WwyJ4qUU5OhqqGEggCdDssbGQNxZWSMPE8WiqCWgBIHrNTDiWkEntFt2MHZDkaYv6z7wa9NDJkGDv6rMWJuQsqUyAJ3xR6j+ppLDy1JFJw2lofG+W8yqa2pVgxna4BnkGg8CHFnOqXkDriM6JBYzOoHHKWSAjpMNpwzgaDgZQe2jFwCjAhP4MYP0kUJbw5lZ84nAwgZIRckhUwMGkmUJA6QSoozxSYekaP4RoVqwUItDse

jBi3UDied9k00KoCtrkW/jWSAV2hOi5eJxsOpzmIKgKiWYkeDSgD6nQBZTuTP7pRAtWlWDTGPQsM3SZ/vre5zam4K6eqeG0GnuMQB5MKZsQtUB77vzSWW4CIpP2w0BUWnPSEMDpPvgFKmSlyH4kiB6kCvwqzyDJ/uhIL+5KSb2+824R0e1k8yyA2QGav5DQOI0G9RTbmDDZyUx8mJVEnODUMJSWtFA1cO96vVljwMHQ66Spcuqwtgb7+aXI7HqcG
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

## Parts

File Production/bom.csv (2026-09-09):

Designator | Footprint | Quantity | Value | LCSC Part #
C1, C10, C11, C17, C2, C3, C4, C5, C6, C7, C8 | 0201 | 11 | 0.1uf
C12, C9 | 0201 | 2 | 1uf
C13, C14 | 0201 | 2 | 10uf
C15, C16 | 0201 | 2 | 33uf
C18, C20, C21 | 0201 | 3 | 10μf
C19 | 0201 | 1 | 0.1μf
J1 | USB_C_Receptacle_HRO_TYPE-C-31-M-12 | 1 | USB_C_Receptacle_USB2.0_14P
J2, J3 | PinHeader_1x20_P1.00mm_Vertical | 2 | Conn_01x20
J4 | PinHeader_1x03_P1.00mm_Vertical | 1 | Conn_01x03
L1 | L_6.3x6.3_H3 | 1 | 2.2μH
R1, R2 | 0402 | 2 | 5.1KΩ
R3, R4 | 0402 | 2 | 27Ω
R5 | 0402 | 1 | 1K
R6 | 0402 | 1 | 1KΩ
R7 | 0402 | 1 | 10KΩ
R8 | 0201 | 1 | 100Ω
SW1, SW2 | SW_SPST_TS-1088-xR020 | 2 | SW_Push
U1 | QFN-56-1EP_7x7mm_P0.4mm_EP3.2x3.2mm | 1 | RP2040
U2 | SOT-89-3 | 1 | MCP1700x-120xxMB
U3 | SOIC-8_5.3x5.3mm_P1.27mm | 1 | W25Q128JVS
U4 | ER_OLEDM0.91_1x-I2C | 1 | ER_OLEDM0.91_1x-I2C
U5 | Texas_DRC0010J_ThermalVias | 1 | TPS63000
XT1 | JST-PH-2 | 1 | ~
Y2 | Crystal_SMD_3225-4Pin_3.2x2.5mm | 1 | Crystal_GND24

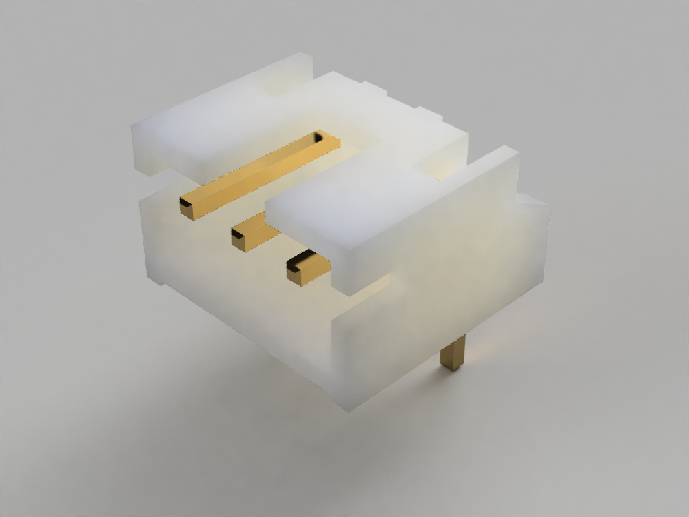
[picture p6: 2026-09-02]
DevboardArt/renders/Component3dmodels/jst-sh-through-hole-right-angle-connectors-1.snapshot.1/S3B-PH-KL.png

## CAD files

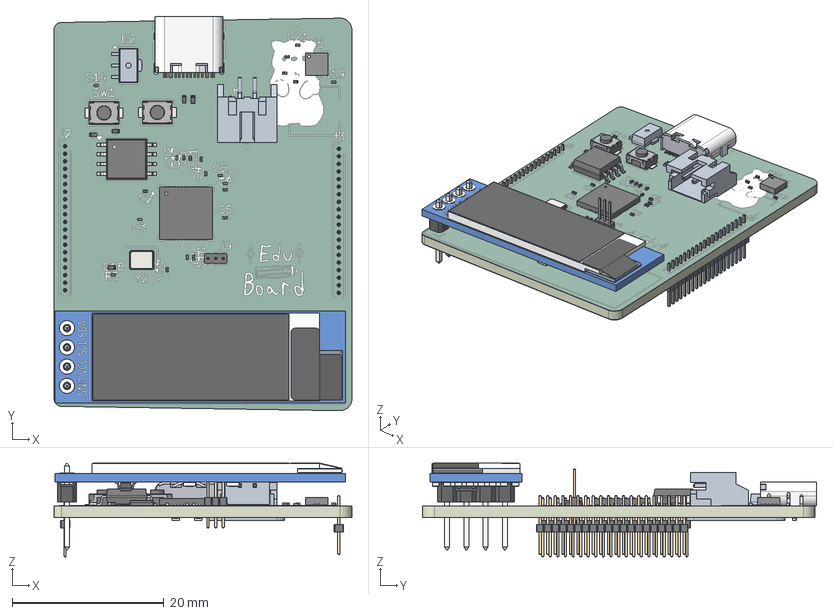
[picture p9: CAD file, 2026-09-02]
Devboard-PCB/Eduboard.step
39.3 x 52.0 x 12.4 mm
C_0201_0603Metric x 21
OLED_0.91_128x32
Pin Header 4 x 1 TH 2.54mm Pitch
RESC-0603 x 13
2SD0601A
=>[0:1:1:2]
=>[0:1:1:4]
R_0402_1005Metric x 7
PinHeader_1x03_P1.00mm_Vertical
PinHeader_1x20_P1.00mm_Vertical x 2
Crystal_SMD_3225-4Pin_3.2x2.5mm
SW_SPST_TS-1088-xR020 x 2
TPS63000DRCR
R_0201_0603Metric
Eduboard 1.30.1
tongue
shield
contact_001
contact_002
contact_003
contact_004
contact_court_001
contact_court_002
contact_court_003
contact_court_004
contact_005
contact_006
contact_007
contact_008
contact_court_005
contact_court_006
contact_court_007
contact_court_008
pin_001
pin_002
pin_003
pin_004
pin_005
pin_006
pin_007
pin_008
pin_009
pin_010
pin_011
pin_012
pin_013
pin_014
pin_015
pin_016
SOIC-8_5.3x5.3mm_P1.27mm
QFN-56-1EP_7x7mm_P0.4mm_EP3.2x3.2mm
Devboard_copper
Devboard_via
Devboard_silkscreen x 2
Devboard_soldermask x 2
Devboard_PCB

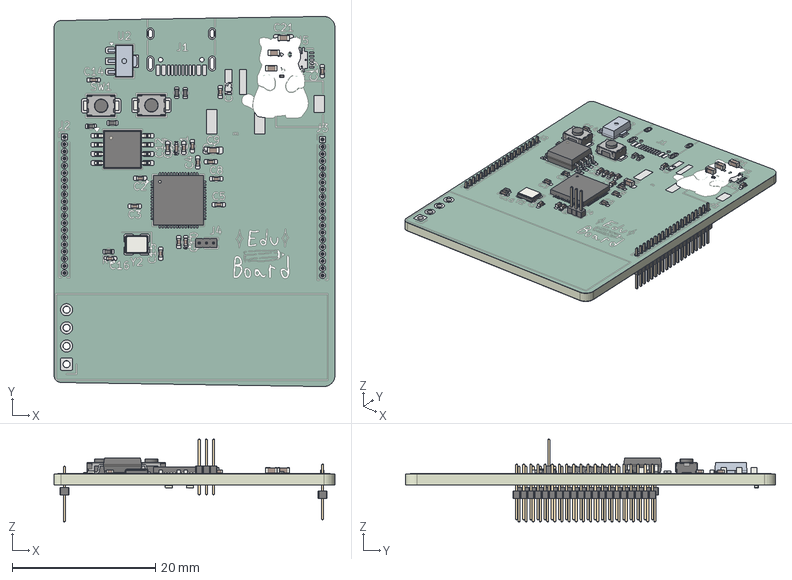
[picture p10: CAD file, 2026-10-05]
DevboardArt/Component 3d models/Eduboard.step
39.3 x 51.7 x 11.6 mm
C_0402_1005Metric x 17
C_0603_1608Metric x 4
R_0402_1005Metric x 7
PinHeader_1x03_P1.00mm_Vertical
PinHeader_1x20_P1.00mm_Vertical x 2
Crystal_SMD_3225-4Pin_3.2x2.5mm
SW_SPST_TS-1088-xR020 x 2
R_0201_0603Metric
Eduboard 1.27.1
SOIC-8_5.3x5.3mm_P1.27mm
QFN-56-1EP_7x7mm_P0.4mm_EP3.2x3.2mm
Devboard_copper
Devboard_pad
Devboard_via
Devboard_silkscreen x 2
Devboard_soldermask x 2
Devboard_PCB

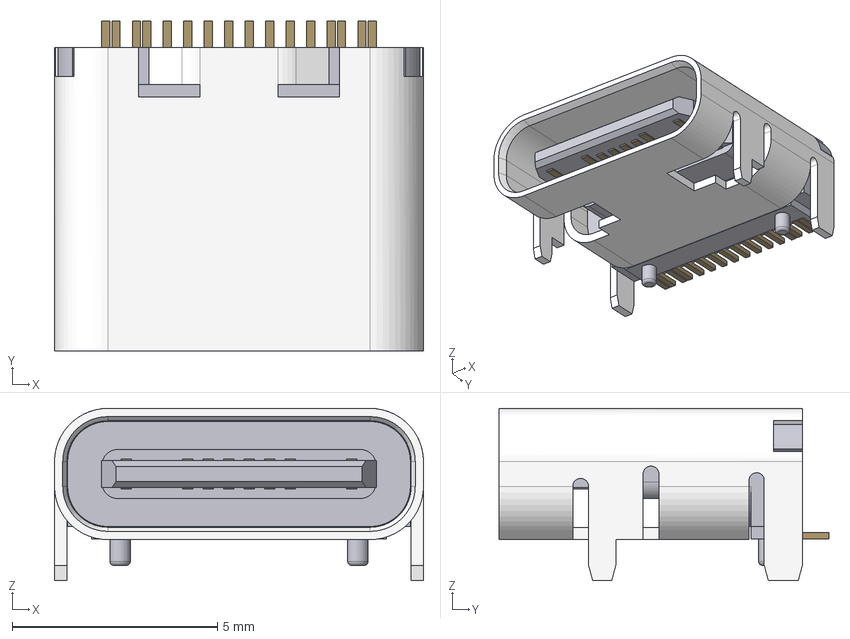
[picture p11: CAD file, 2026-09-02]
DevboardArt/renders/Component3dmodels/16-pin-smd-usb-c-connector-through-holes-1.snapshot.7/usb-c_16pins_vertical.step
9.00 x 8.05 x 4.20 mm
tongue
shield
contact_001
contact_002
contact_003
contact_004
contact_court_001
contact_court_002
contact_court_003
contact_court_004
contact_005
contact_006
contact_007
contact_008
contact_court_005
contact_court_006
contact_court_007
contact_court_008
pin_001
pin_002
pin_003
pin_004
pin_005
pin_006
pin_007
pin_008
pin_009
pin_010
pin_011
pin_012
pin_013
pin_014
pin_015
pin_016

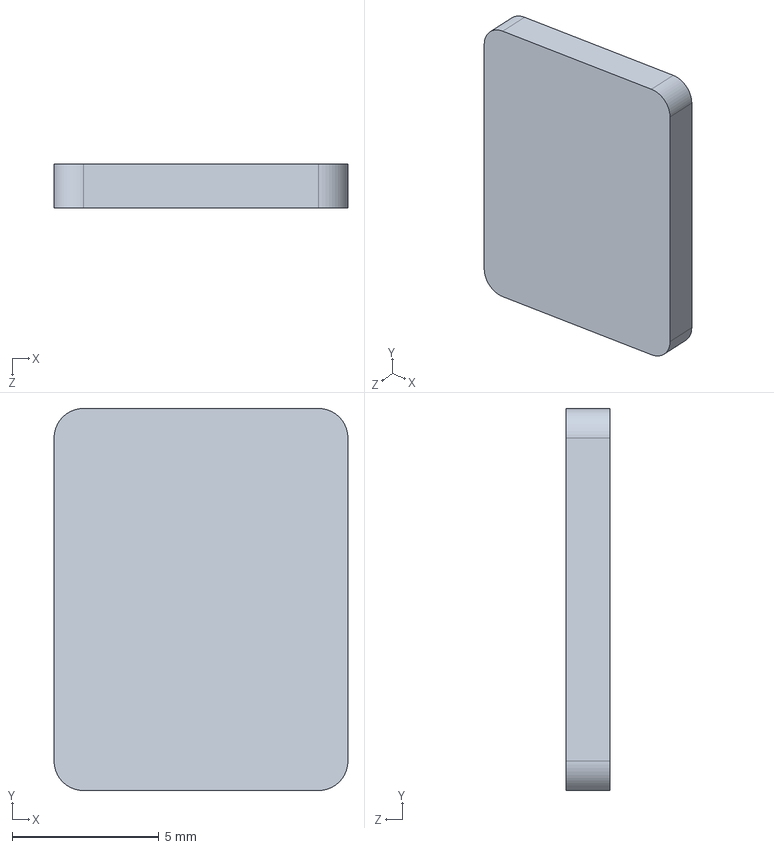
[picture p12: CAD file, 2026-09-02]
DevboardArt/renders/Component3dmodels/adafruit-jst-ph-2-pin-smt-right-angle-breakout-board-1.snapshot.1/JST-PH 2-Pin Breakout Board.STEP
10.0 x 13.0 x 1.50 mm

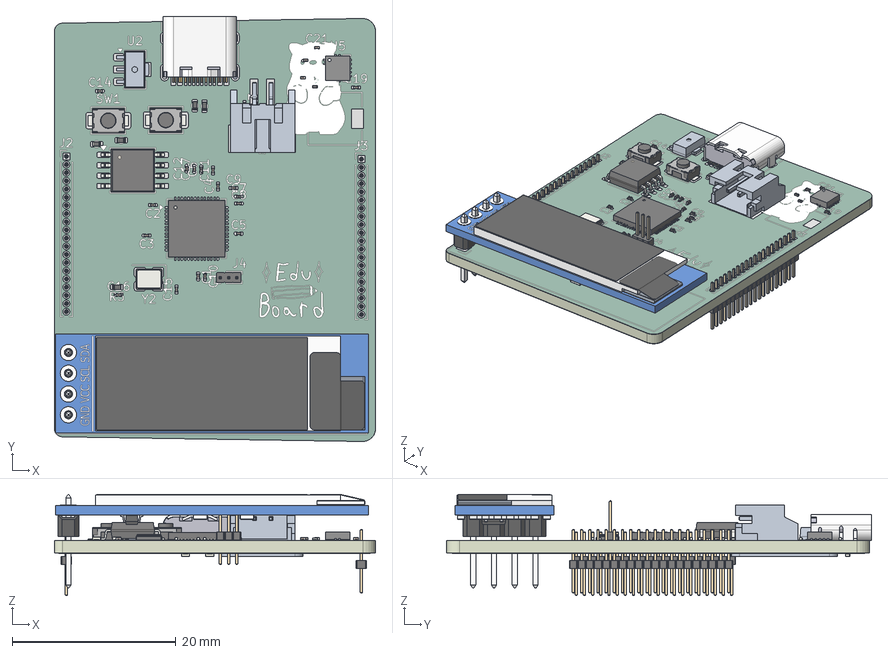
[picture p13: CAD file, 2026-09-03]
DevboardArt/renders/Component3dmodels/Eduboard.step
39.3 x 52.0 x 12.4 mm
C_0201_0603Metric x 21
OLED_0.91_128x32
Pin Header 4 x 1 TH 2.54mm Pitch
RESC-0603 x 13
2SD0601A
=>[0:1:1:2]
=>[0:1:1:4]
R_0402_1005Metric x 7
PinHeader_1x03_P1.00mm_Vertical
PinHeader_1x20_P1.00mm_Vertical x 2
Crystal_SMD_3225-4Pin_3.2x2.5mm
SW_SPST_TS-1088-xR020 x 2
TPS63000DRCR
R_0201_0603Metric
Eduboard 1.30.1
tongue
shield
contact_001
contact_002
contact_003
contact_004
contact_court_001
contact_court_002
contact_court_003
contact_court_004
contact_005
contact_006
contact_007
contact_008
contact_court_005
contact_court_006
contact_court_007
contact_court_008
pin_001
pin_002
pin_003
pin_004
pin_005
pin_006
pin_007
pin_008
pin_009
pin_010
pin_011
pin_012
pin_013
pin_014
pin_015
pin_016
SOIC-8_5.3x5.3mm_P1.27mm
QFN-56-1EP_7x7mm_P0.4mm_EP3.2x3.2mm
Devboard_copper
Devboard_pad
Devboard_via
Devboard_silkscreen x 2
Devboard_soldermask x 2
Devboard_PCB

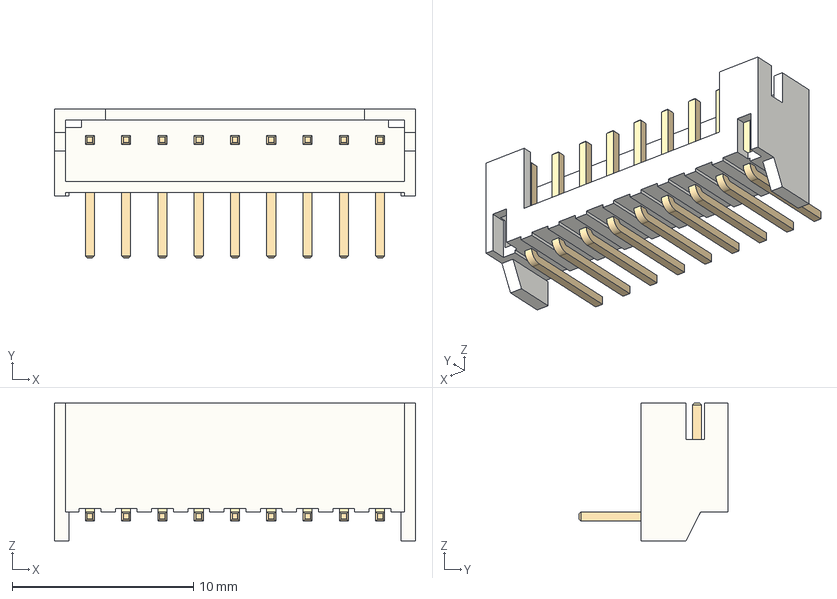
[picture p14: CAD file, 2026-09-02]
DevboardArt/renders/Component3dmodels/jst-sh-through-hole-right-angle-connectors-1.snapshot.1/S9B-PH-KL.stp
19.9 x 8.20 x 7.60 mm

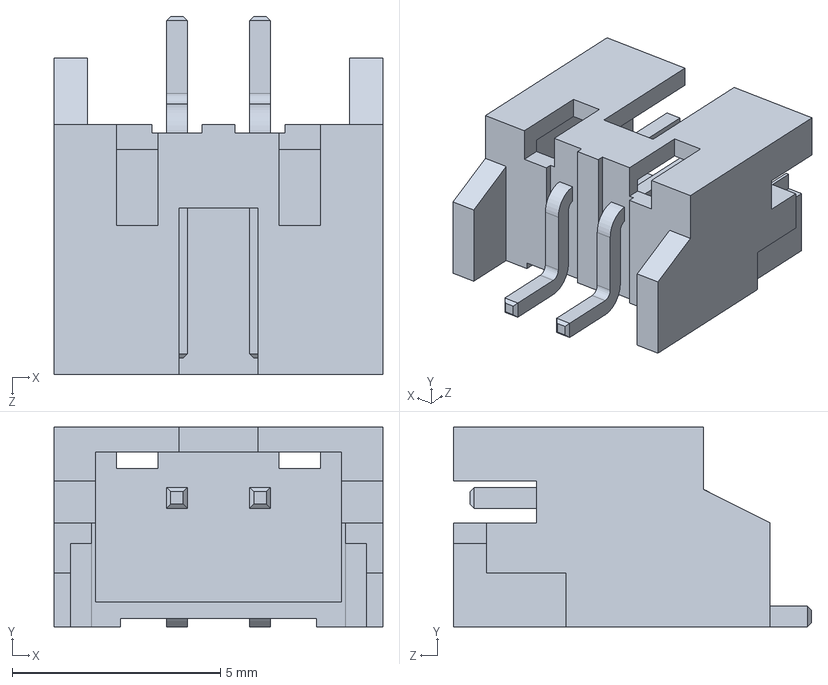
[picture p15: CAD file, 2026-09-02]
DevboardArt/renders/Component3dmodels/adafruit-jst-ph-2-pin-smt-right-angle-breakout-board-1.snapshot.1/S2B-PH-SM4-TB.SLDPRT
7.90 x 4.80 x 8.60 mm

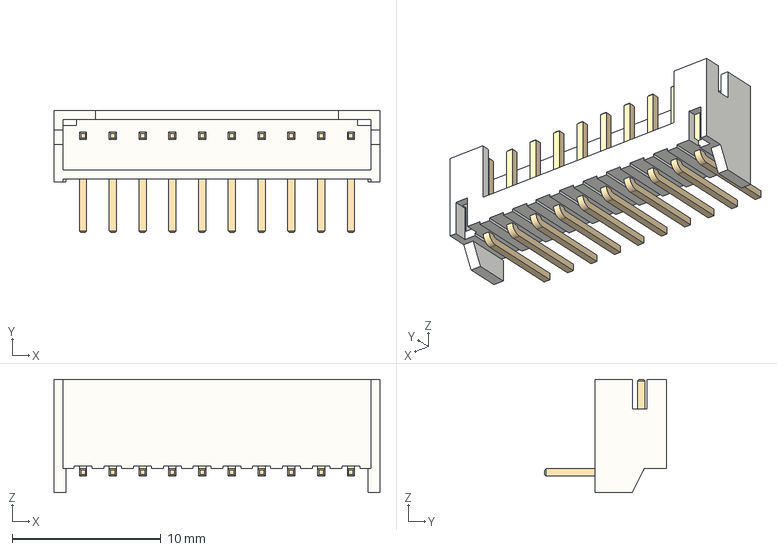
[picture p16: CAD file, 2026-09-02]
DevboardArt/renders/Component3dmodels/jst-sh-through-hole-right-angle-connectors-1.snapshot.1/S10B-PH-KL.stp
21.9 x 8.20 x 7.60 mm

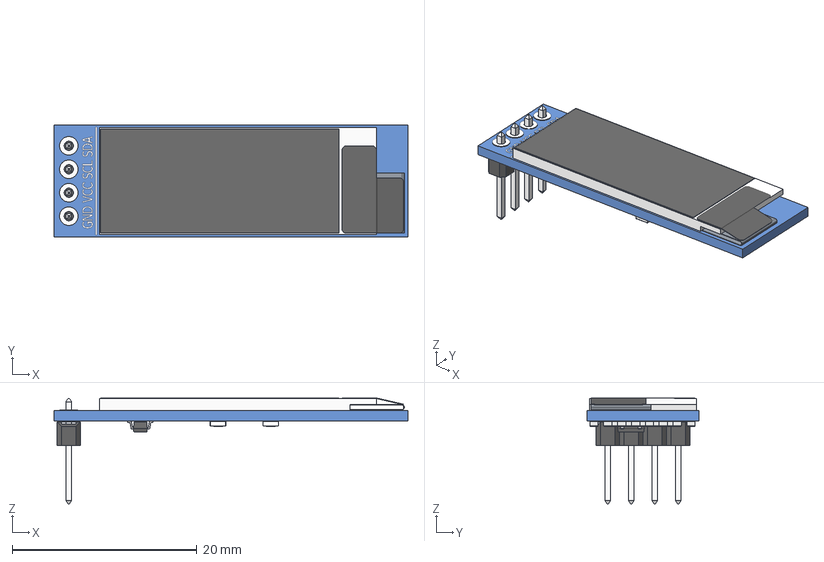
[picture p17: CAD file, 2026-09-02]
DevboardArt/renders/Component3dmodels/OLED_0.91_128x32.stp
38.3 x 12.1 x 11.5 mm
OLED_0.91_128x32
Pin Header 4 x 1 TH 2.54mm Pitch
RESC-0603 x 13
2SD0601A

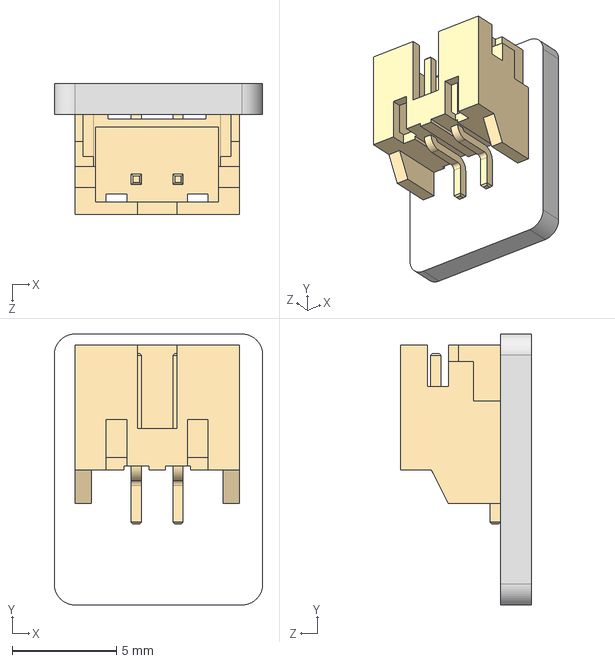
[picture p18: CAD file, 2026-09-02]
DevboardArt/renders/Component3dmodels/JST-PH 2-Pin Breakout Board.IGS
10.0 x 13.0 x 6.30 mm

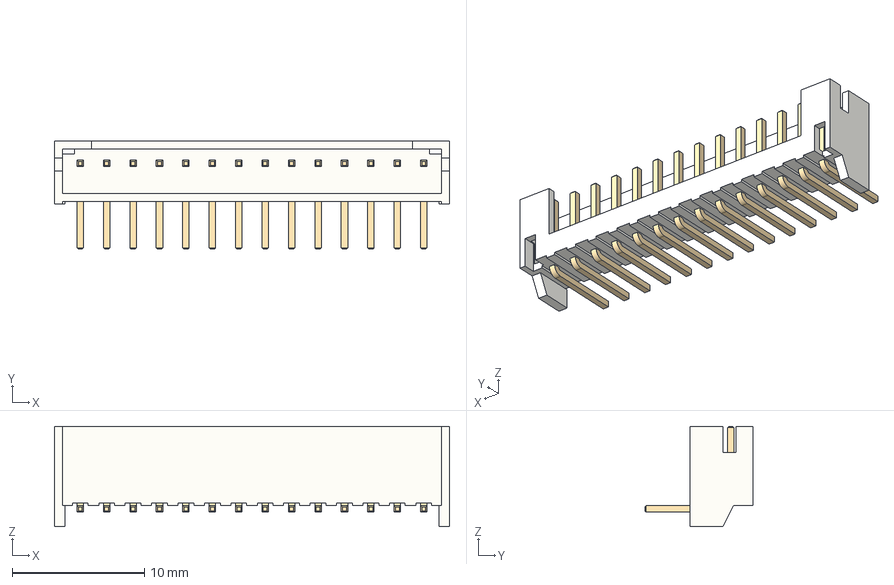
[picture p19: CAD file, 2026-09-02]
DevboardArt/renders/Component3dmodels/jst-sh-through-hole-right-angle-connectors-1.snapshot.1/S14B-PH-KL.stp
29.9 x 8.20 x 7.60 mm

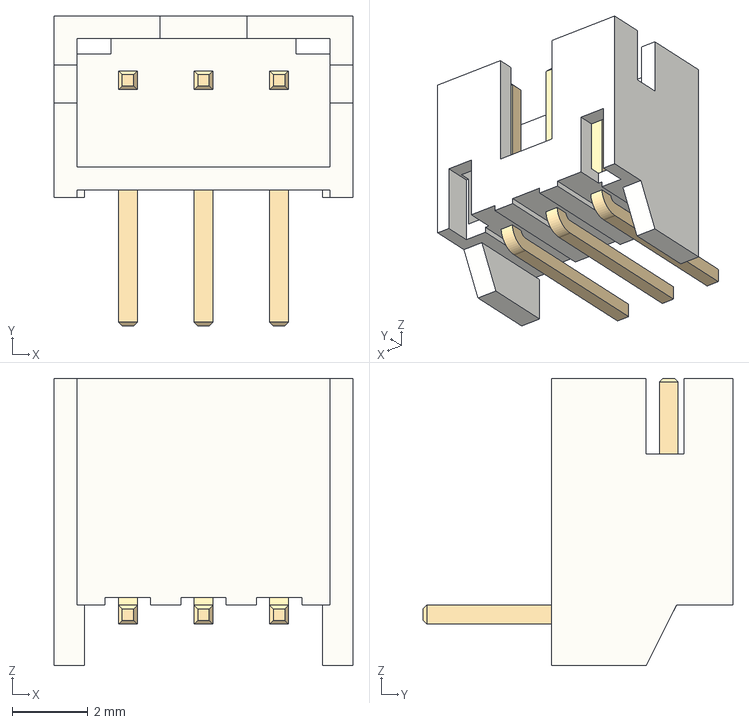
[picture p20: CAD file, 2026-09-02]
DevboardArt/renders/Component3dmodels/jst-sh-through-hole-right-angle-connectors-1.snapshot.1/S3B-PH-KL.stp
7.90 x 8.20 x 7.60 mm

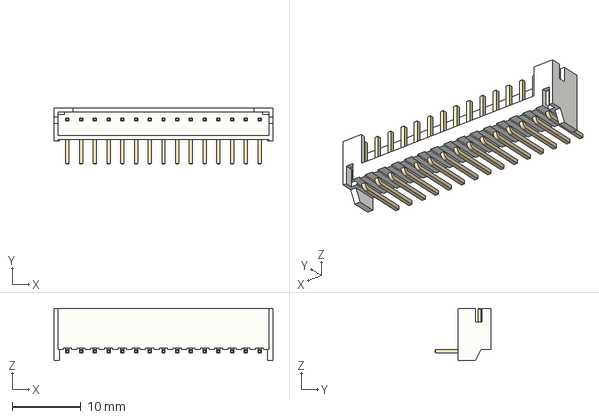
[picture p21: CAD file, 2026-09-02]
DevboardArt/renders/Component3dmodels/jst-sh-through-hole-right-angle-connectors-1.snapshot.1/S15B-PH-KL.stp
31.9 x 8.20 x 7.60 mm

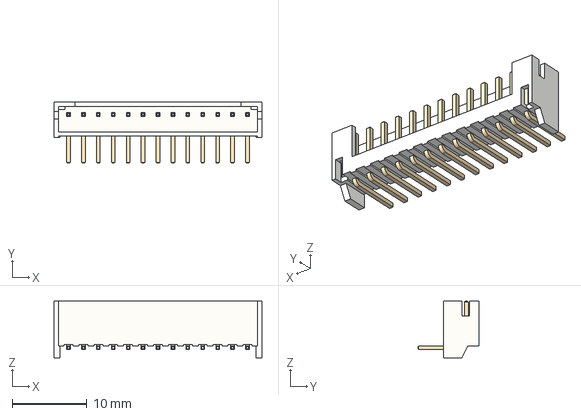
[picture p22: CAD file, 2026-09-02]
DevboardArt/renders/Component3dmodels/jst-sh-through-hole-right-angle-connectors-1.snapshot.1/S13B-PH-KL.stp
27.9 x 8.20 x 7.60 mm

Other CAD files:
DevboardArt/renders/Component3dmodels/jst-sh-through-hole-right-angle-connectors-1.snapshot.1/S2B-PH-KL.stp
DevboardArt/renders/Component3dmodels/jst-sh-through-hole-right-angle-connectors-1.snapshot.1/S5B-PH-KL.stp
DevboardArt/renders/Component3dmodels/jst-sh-through-hole-right-angle-connectors-1.snapshot.1/S7B-PH-KL.stp
DevboardArt/renders/Component3dmodels/jst-sh-through-hole-right-angle-connectors-1.snapshot.1/S11B-PH-KL.stp
DevboardArt/renders/Component3dmodels/TPS63000DRCR.STEP
DevboardArt/renders/Component3dmodels/adafruit-jst-ph-2-pin-smt-right-angle-breakout-board-1.snapshot.1/JST-PH 2-Pin Breakout Board.SLDASM
DevboardArt/renders/Component3dmodels/adafruit-jst-ph-2-pin-smt-right-angle-breakout-board-1.snapshot.1/JST-PH 2-Pin Breakout Board.SLDPRT
DevboardArt/renders/Component3dmodels/jst-sh-through-hole-right-angle-connectors-1.snapshot.1/S12B-PH-KL.stp
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

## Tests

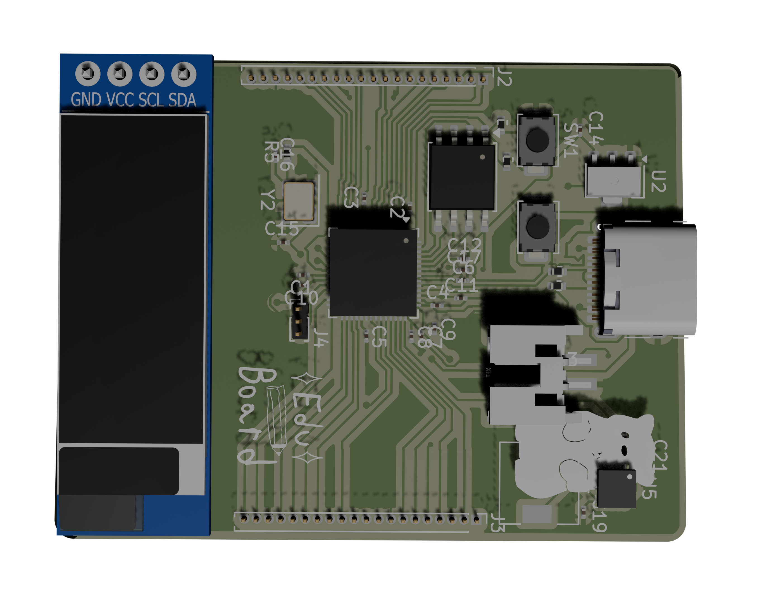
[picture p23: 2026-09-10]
DevboardArt/renders/Straight down test2.png

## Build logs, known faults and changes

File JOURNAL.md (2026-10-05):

---
title: "Devboard"
author: "bobis"
description: "This is a devboard with a constructor with it."
created_at: "2024-03-20"
---

# May 3: Started the schematic and thought about the direction.

Today I worked on the schematic of the devboard. I got to the point where I have to start adding pin headers.
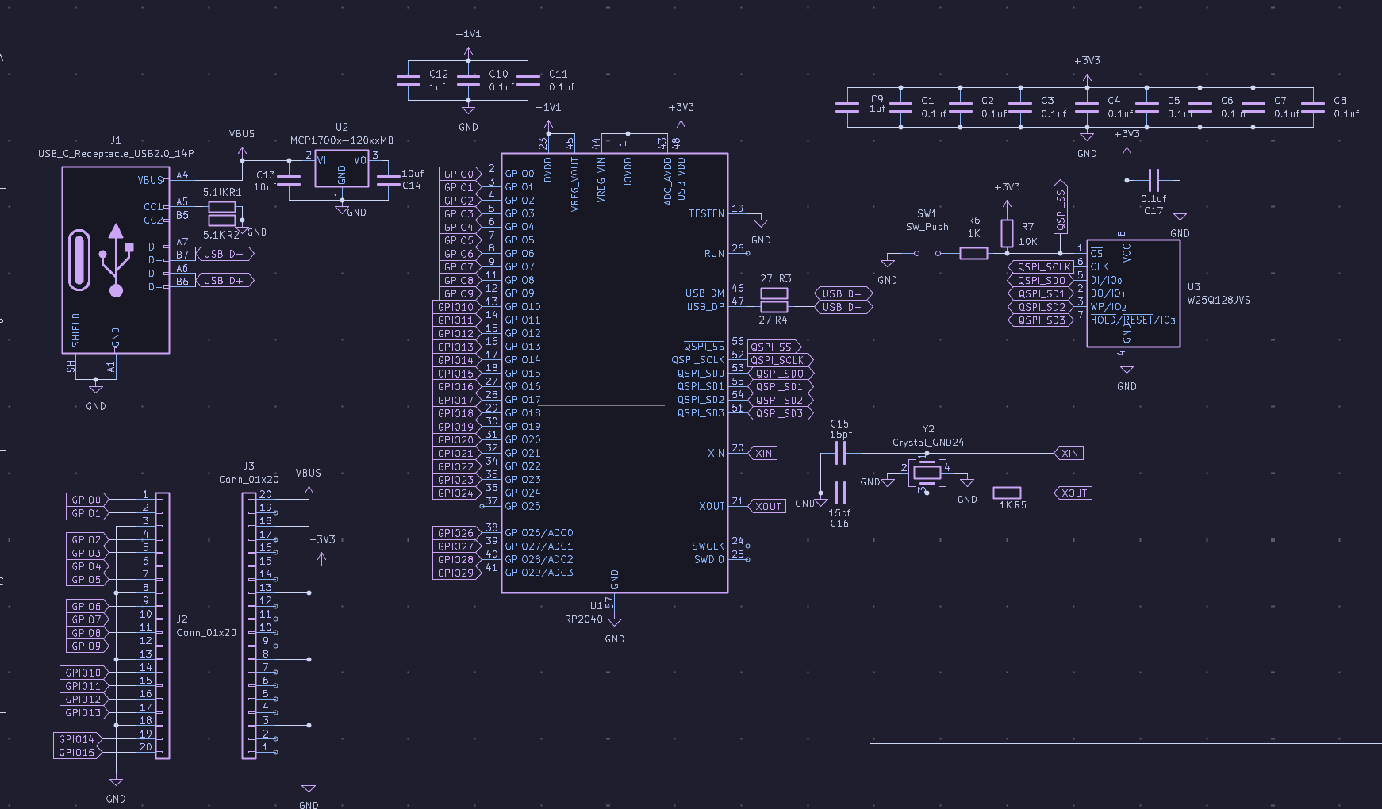
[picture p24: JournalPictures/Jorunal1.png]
Screenshot 2026-05-02 at 7.35.12 PM.png

There is not much to say. I am mostly just setting things up until I can come up with an idea of what exactly I want this to be. There are three ideas that I am interested in: a devboard that has onboard sensors like temperature sensors, moisture sensors, etc., and solar panels and a battery. If I do this, I would have to create a case for this since it would be intended for outdoor use. Another way that this could go is I could make a slightly gaming-oriented dev board where you can easily create games using software that I would create as part of this project. With this idea, you would create breadboards/PCBs with different types of input to control the games. The last idea that I had was an education-centered dev board that comes with some software that would allow you to create programs very easily, so that younger children can get an introduction to STEM. I am leaning towards the first two ideas.

Recording links:
- https://public.lapse-hackclub.link/timelapses/DGkcKer8LFst/timelapse-DGkcKer8LFst.mp4

**Total time spent: 0.933 hours**

# May 4: Chose a direction, added an OLED display and button

Today I worked on continuing the tutorial. I felt really tired and really not aware today, so progress was slower than I would have liked. I decided to go the route of gaming and education. I plan on making a tool so that people can get into STEM. I decided to add a general input button along with an OLED display(SSD1306). I overall think that I made ok progress. I also laid out the general placement of the components for the PCB.
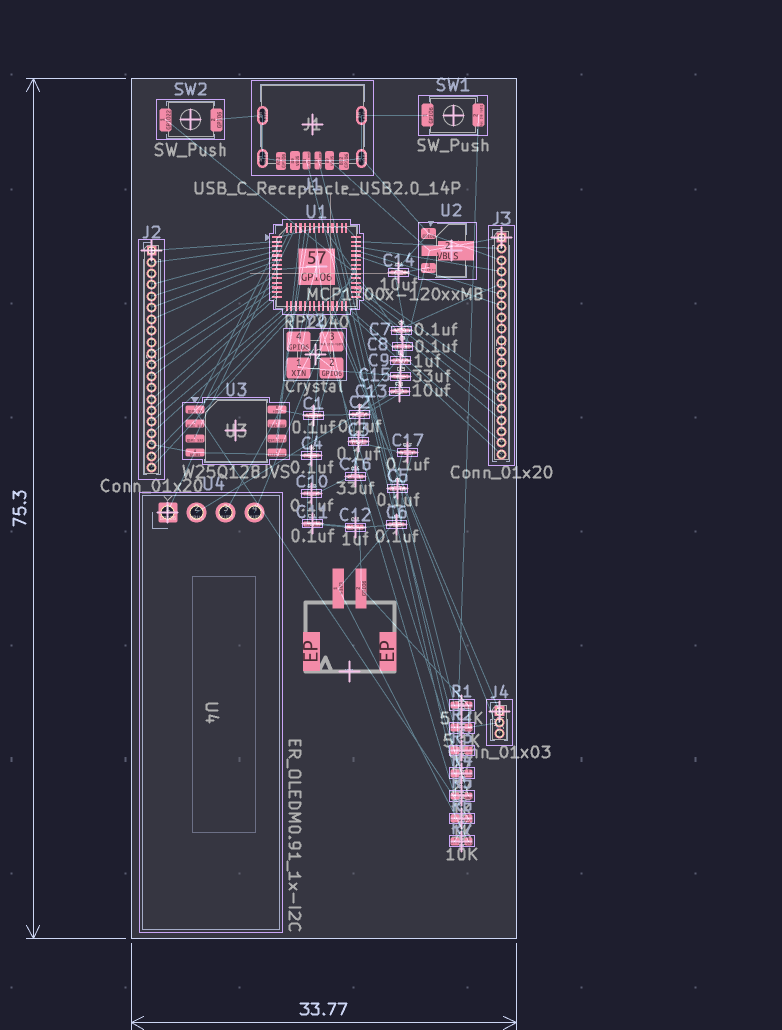
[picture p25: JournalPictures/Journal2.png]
Screenshot 2026-05-03 at 10.50.35 PM.png

I think that having the OLED screen on the outer reaches away from the pins is a bad design choice. I will probably make the devboard wider, not longer, to accommodate this. Honestly, I am not even sure if this can qualify as a devboard, considering it is becoming more like Sprig.

Recording links:
- https://public.lapse-hackclub.link/timelapses/7_ZJfe8KnYUe/timelapse-7_ZJfe8KnYUe.mp4

**Total time spent: 1.1 hours**

# May 5: Routed the flash memory and USB port

Today, I worked mostly on getting some of the routing done. I followed the advice outlined in the custom devboard guide by doing the flash memory first instead of doing anything else. I took a lot of time to make sure that I could do everything in that area without using vias.
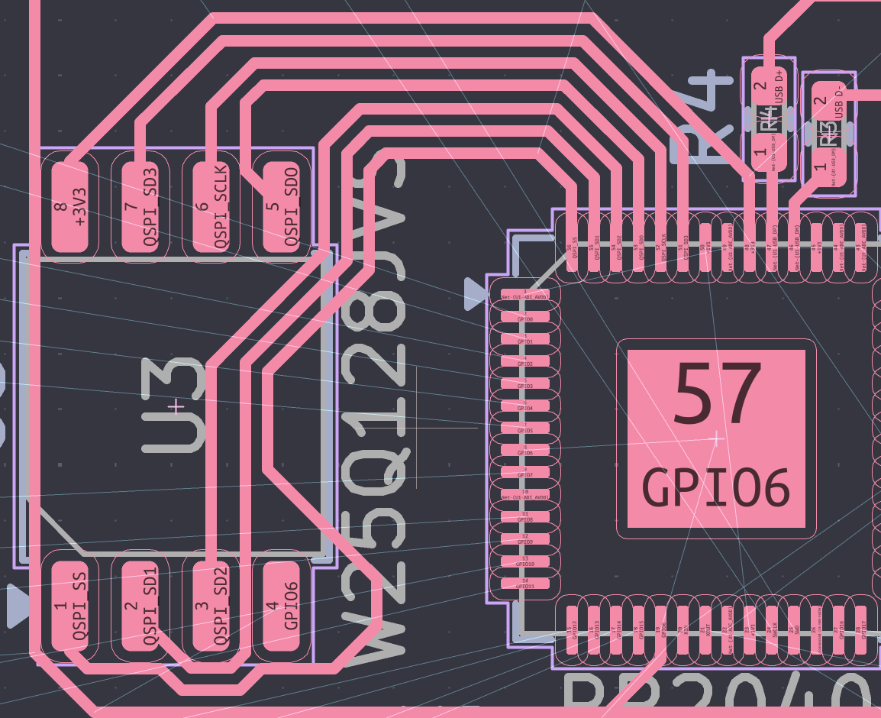
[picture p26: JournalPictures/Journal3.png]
Screenshot 2026-05-04 at 8.39.04 PM.png

I did have issues with this, and I had to restart on this a couple of times. I also decided to try to work on trying to route the USB port. About halfway through doing this, I realized that I had used the wrong footprint. I changed it, but I had to kind of restart. Routing this was not as bad as routing the flash memory, though.

Aside from this, I am still not sure if the direction that I am going with the devboard is necessarily good. The screen is nice, but it feels too large, and the fact that it will take up a GPIO pin that cannot be used by whoever will end up using the devboard is kinda upsetting, but also it is something that makes sense. I will have to go on and see whether this is actually worth it or not.

Recording links:
- https://public.lapse-hackclub.link/timelapses/LOK1z_V-Vksl/timelapse-LOK1z_V-Vksl.mp4
- https://public.lapse-hackclub.link/timelapses/FhLKLNGlcSYP/timelapse-FhLKLNGlcSYP.mp4

**Total time spent: 1.15 hours**

# May 6: More routing and via struggles

Today was another day of routing things. I feel like today was less productive than normal, though. I spend a lot of time trying to figure out "tune length of single track". I also spend a fair bit of time trying to get the component placement right. I ended up having to move the decoupling capacitors slightly above the RP2040 footprint to avoid having the route around them when it came time to route the pinheaders. Overall, my main struggles today were trying to route around the flash memory module. I ended up having to use lots and lots of vias, which I am not super proud of. I really do not feel like restarting the process though. Tomorrow I need to wrap up some of the routing and make sure that I do not have any 90-degree traces or anything.
Screenshot 2026-05-05 at 10.00.54 PM.png
As a bit of a side note, here is my progress. As you can see, the traces on the left have lots of very messy vias scattered around. I also got stuck researching a bit about whether vias could be used when routing the crystal oscillator. I found out that I could but I decided against it.

Recording links:
- https://public.lapse-hackclub.link/timelapses/aq-a-650iFIS/timelapse-aq-a-650iFIS.mp4

**Total time spent: 1.45 hours**

# May 7: Finished GPIO routing, added GND fill

Today was a fairly productive day. Pretty much just routed more of the PCB today. I first finished up all the GPIO pin routing. I struggled a lot with this since the flash memory module blocked off a lot of the RP2040. I had to use very many vias for this.
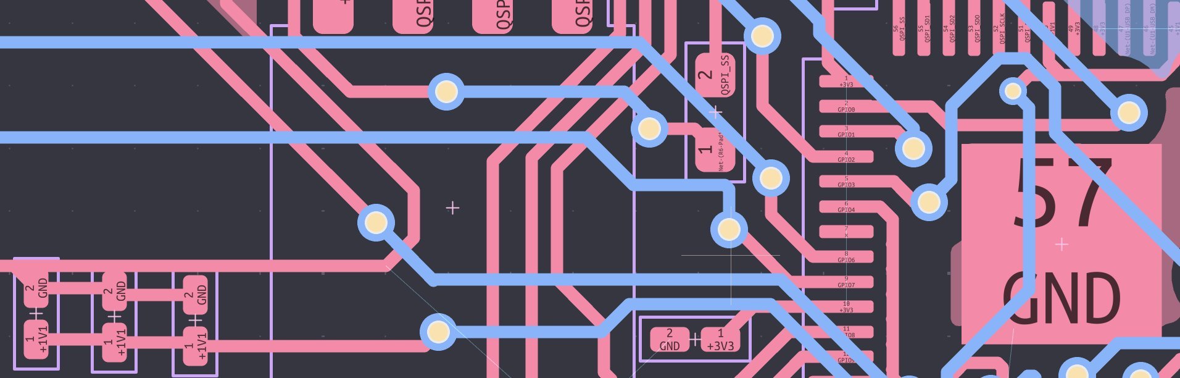
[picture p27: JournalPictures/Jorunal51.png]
Screenshot 2026-05-06 at 10.28.24 PM.png

Here is a screenshot of the general area that was affected by this. The next thing that I did was add GND fill to the board. This did not cover all of the GND connections, so I will need to work on making sure that all the GNDs are connected. The next thing that I did was try to connect the 1V1 to the decoupling capacitors.
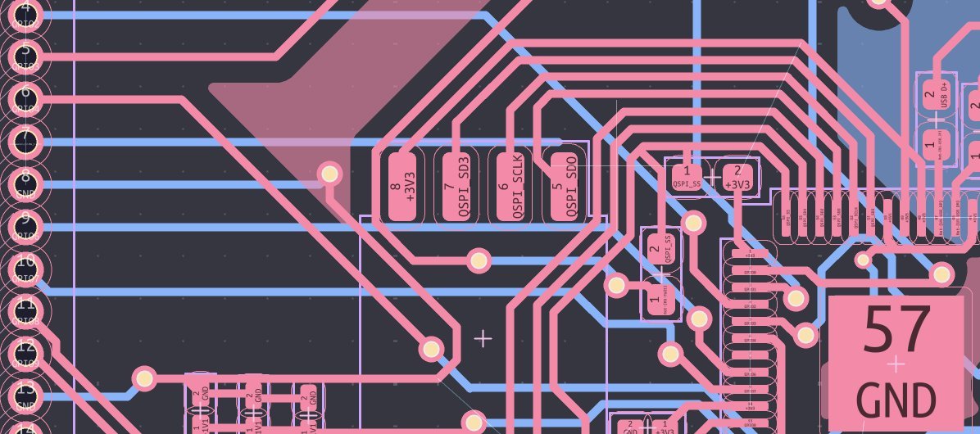
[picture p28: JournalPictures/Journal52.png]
Screenshot 2026-05-06 at 10.21.14 PM.png

It is probably hard to tell from the picture, but the trace connecting the 1v1s with the decoupling capacitors is very very very very very very very very very long. I don't really know how much this will affect the pcb nor how much it will be effected but I will work to make the length shorter

**Todo**
- FInish routing the GNDs
- Shorten the 1v1 trace
- Finish the 3v3 trace from the decoupling capacitors.

Recording links:
- https://public.lapse-hackclub.link/timelapses/nqFdDxovM8Hh/timelapse-nqFdDxovM8Hh.mp4

**Total time spent: 1.28 Hours**

# May 13: Wrapped up more routing

Today I did more routing. Like with barrel roll, there isn't much to talk about. However, for the time I was trying to work, I felt like I worked a lot more. I had some struggles trying to make sure that nothing was really terribly routed or had really difficult trace lengths. The one thing that I am not super sure about is that I put one of the resistors for the USB port on the other side of the USB port. I am not sure if this will affect it. I do not think so, since it is not a signal-carrying wire. The next steps for me would be to wrap up the routing and work on the software platform.
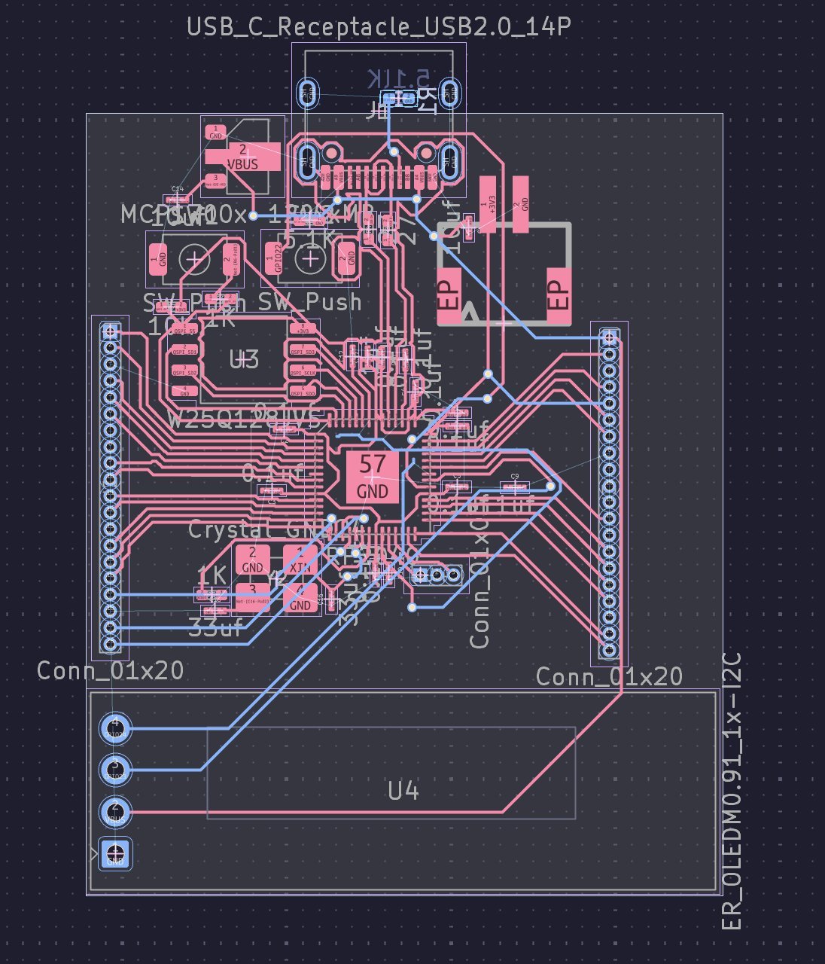
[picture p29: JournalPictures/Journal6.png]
Screenshot 2026-05-12 at 11.27.56 PM.png

Here is a picture of progress so far.

Recording links:
- https://public.lapse-hackclub.link/timelapses/pCT4w-ZVqyHo/timelapse-pCT4w-ZVqyHo.mp4
- https://public.lapse-hackclub.link/timelapses/vtBHhhoqcy5y/timelapse-vtBHhhoqcy5y.mp4
- https://public.lapse-hackclub.link/timelapses/U8BlEgYKHTOK/timelapse-U8BlEgYKHTOK.mp4
- https://public.lapse-hackclub.link/timelapses/r_VSW0o6QzoZ/timelapse-r_VSW0o6QzoZ.mp4

**Total time spent: 0.61 hours**

# May 14: Redid the routing around the decoupling capacitors

In this devlog, I set up the basic layout and routing for the devboard. I decided to redo the routing that I had already done because the trace length on the 1v1 trace was too long for it to work properly. So it was mostly a repeat of what happened earlier, but I did the decoupling capacitors first. The difference was that I simply placed everything with respect to the capacitors.
Screenshot 2026-05-12 at 11.27.56 PM.png
This is what I have right now. The next thing that I have to do is I have to route everything else and work on the software platform for the project. In hindsight, I probably should have created a planning doc for larger projects like this.
Note to reviewers: I made the original version of this devlog on May 12.

Recording links:
- https://public.lapse-hackclub.link/timelapses/Pfab0-hPdquu/timelapse-Pfab0-hPdquu.mp4
- https://public.lapse-hackclub.link/timelapses/LPbBbGXVQzN0/timelapse-LPbBbGXVQzN0.mp4

**Total time spent: 0.75 hours**

# May 18: Finished up the PCB

Today I worked on finishing up the PCB. I almost had to restart for the second time because I thought that I had messed up the placement of the decoupling capacitors. I really didn't struggle too much with this, as it did not take up that much time.
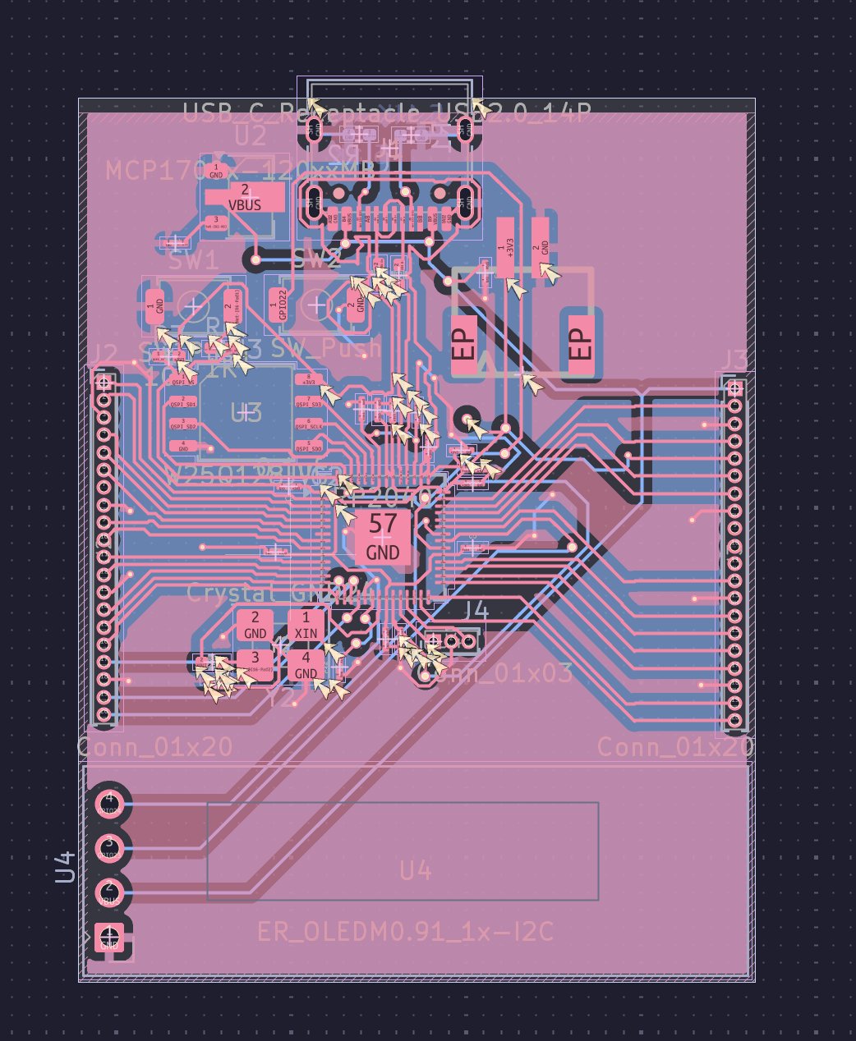
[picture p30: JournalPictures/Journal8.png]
Screenshot 2026-05-17 at 9.39.35 PM.png

This is what the almost finished PCB looks like. One thing that did trip me up during all of this is that I did not set up the DRC correctly according to the JLCPCB capabilities. Yeah, I really can't say much more. The next steps for me would be to get the silk screen art done. I want to work on the basic firmware that all the education features would work on top of.

Recording links:
- https://public.lapse-hackclub.link/timelapses/dfIe_jsVfIqO/timelapse-dfIe_jsVfIqO.mp4

**Total time spent: 1.05 hours**

# May 21: Silkscreen art and naming the board

Today, I mostly worked on the art of the devboard. I also decided on a name while making the art. I decided to go with a cartoony theme with handwritten letters in Excalidraw. I also opted for some hand-drawn graphics. I really think that they don't look the greatest. The first thing that I did to try to do this was to have a draft. I basically got the layout of each part of the PCB silkscreen.

This is the draft image that I got. The next thing I tried was to export all the different parts as a graphic in KiCad. One challenge that I had during this was that I had an error that said "No graphic items found in file." The problem was that I had used vert.sh to change my existing .png files to .svg files instead of exporting them separately. According to a KiCad forms thread, the issue was caused by having the .svg not in Unix (FL) format. The next thing that I did was I got everything arranged.
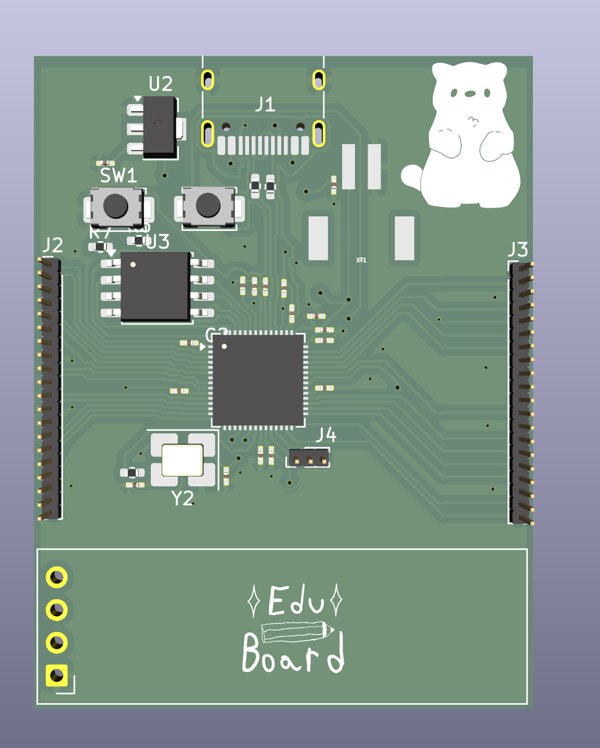
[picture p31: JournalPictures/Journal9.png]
Screenshot 2026-05-20 at 10.21.36 PM.png

Here is what the pcb looks like right now.

Recording links:
- https://public.lapse-hackclub.link/timelapses/pjo93tp7kQIv/timelapse-pjo93tp7kQIv.mp4

**Total time spent: 1.13 Hours**

# May 22: Splash screen firmware and starting the software platform

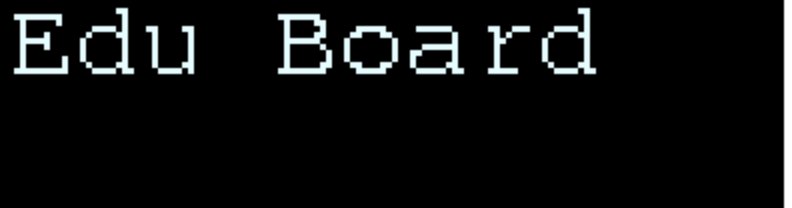
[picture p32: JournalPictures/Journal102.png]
Screenshot 2026-05-22 at 11.25.17 AM.png
Today I worked on creating some of the firmware and the software platform. The first thing that I did was create a real quick splash screen for the OLED screen. I just used an online tool for this The next thing that I tried to do was work on the software platform. I will probably make a desktop/web app using Godot. One thing that I struggled with was figuring out how exactly to communicate with the devboard over USB. Apparently, the way to do it is that you have to use C# and use System.IO.Ports to use a serial port that is named something. There was not as much struggle since this was mostly just setting up boilerplate code.

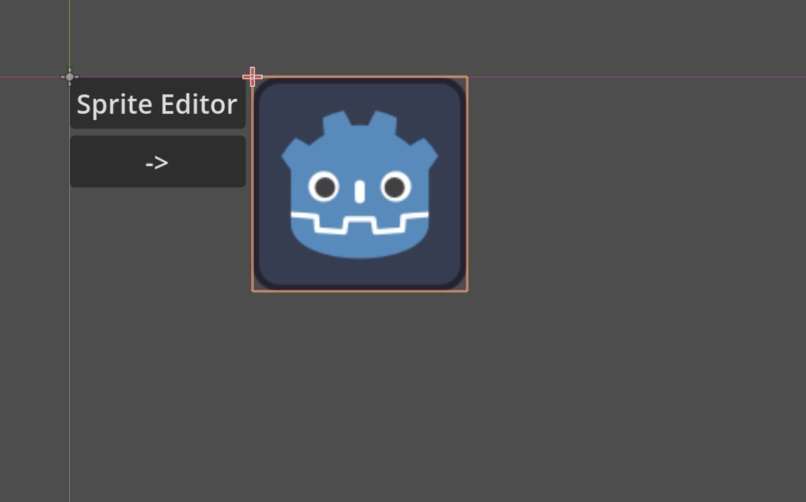
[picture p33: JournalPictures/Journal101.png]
Screenshot 2026-05-22 at 11.42.45 AM.png

This is what I am trying to set up right now.

Recording links:
- https://public.lapse-hackclub.link/timelapses/RL9jTkZymbQ6/timelapse-RL9jTkZymbQ6.mp4

**Total time spent: 1.13 hours**

# May 27: Godot constructor blocks and sprite editor

Today was not the best day in terms of productivity. The main thing that I worked on was the Godot constructor part of the project. I tried to come up with some of the blocks that would be used in the constructor. I decided to use something like Scratch to create the blocks.
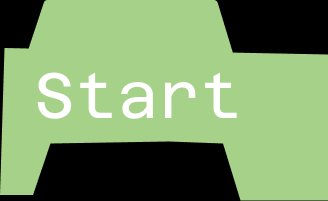
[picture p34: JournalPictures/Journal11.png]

Right now, this is what they look like. In addition to creating the blocks themselves. I also worked on getting the snapping logic to work. I know that it doesn't work, but I think that it should be fine enough. Another thing that I tried to do during this time was to get a sprite editor working. The main struggle with this was how I was going to integrate the sprite editor into the current project(I just stole on from my fantasy console project). THe next thing that I will do is I will work on getting the constructor bricks working.

Recording links:
- https://public.lapse-hackclub.link/timelapses/THLCydzMLRA7/timelapse-THLCydzMLRA7.mp4

**Total time spent: 0.916 hours**

# May 28: Getting the UI set up

Today, I worked on trying to get the UI set up for the devboard. The main thing that I worked on was trying to get the Hboxes to work. The main struggle today was trying to find the correct settings to make the textured rects that represented the constructors actually resize properly. I don't have a lot of time to finish this devlog, and honestly, I might just export this to Horizons.
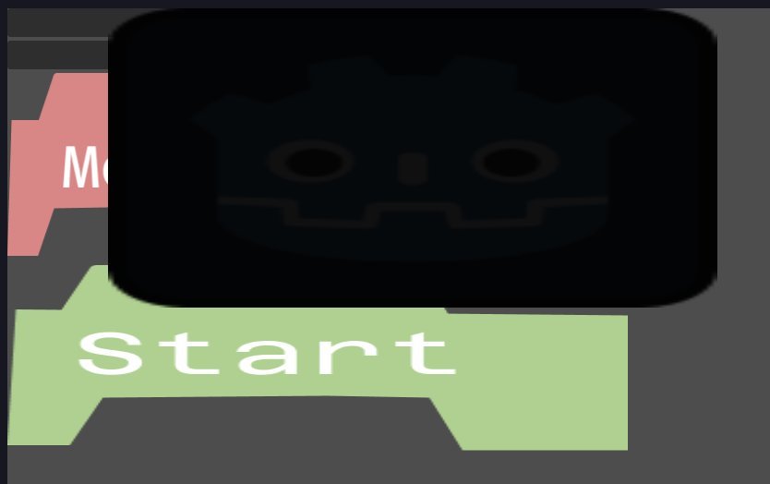
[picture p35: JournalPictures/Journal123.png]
Screenshot 2026-05-27 at 8.52.39 PM.png

This is what the first iteration looked like. In this one I simply forgot to make the workspace a part of a vbox. The second iteration is here
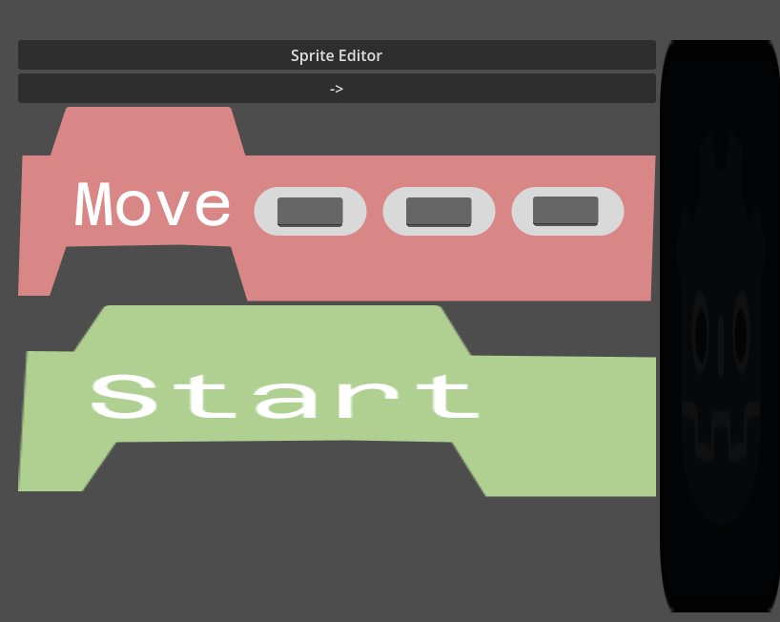
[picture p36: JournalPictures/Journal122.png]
Screenshot 2026-05-27 at 8.54.11 PM.png
 Here is pretty much where I fixed it. This is what it looks like now.
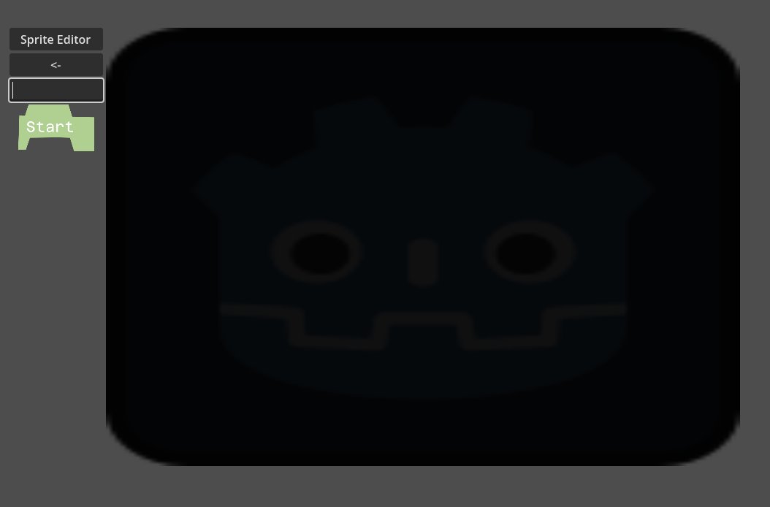
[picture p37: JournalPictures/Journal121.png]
Screenshot 2026-05-27 at 9.49.08 PM.png

I think that I messed up the display for the first one somehow. I really don't know how much time this is going to take. These concepts lowk should feel easy to remember since the other Godot projects that I worked on. The next things that I need to do are I need to: ~~Fix the first constructor's display(something to do with the text box)~~. Fix the drag detection (should be pretty simple, tbh). In addition, I need to work on the snapping logic. The thing with it is that I just got the logic off of my tower plinko prototype thing. The main concern is that I don't think that everything translated properly.(Yea it doesn't work) I think that there is an issue with the way I reimplemented the code from towerplinko. The time is an estimate, I believe it is at minimum '

**Total time spent: 0.5 hours**

# August 22: Getting the drag and drop logic working.

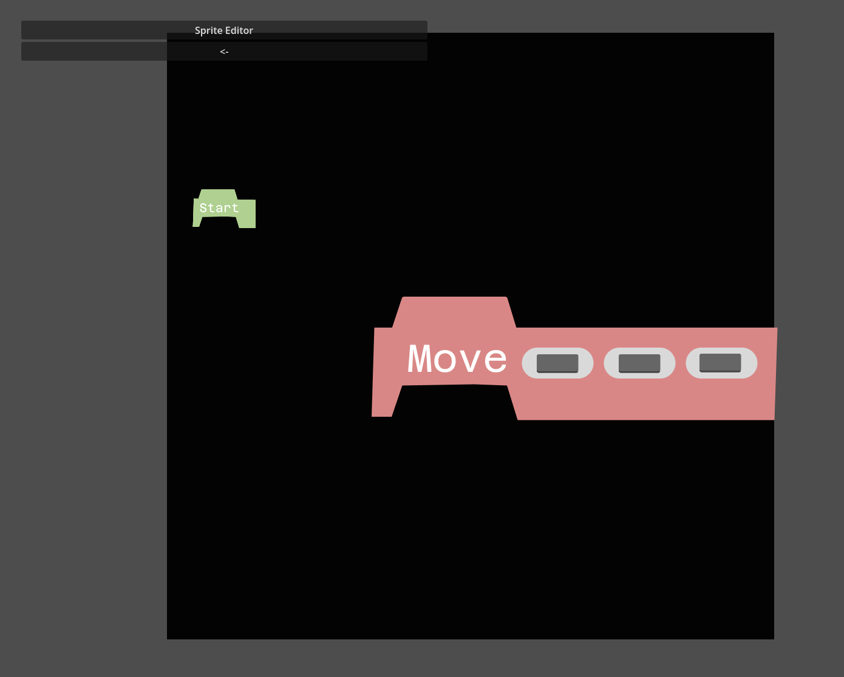
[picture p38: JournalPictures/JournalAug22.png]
JournalAug22
It has been a while, In this devlog I tried to reform the drag and drop logic. I found out that there is a way to do this with built in stuff from godot. Yea, this isn't the greatest. It took a embarringly long to get used to what I did earlier and to do this. The next thing I need to do is I need to make it so that the block dragging works like scratch. I also need to make the UI actually look good. . This is what it looks like right now. I also tried to use opencode to reformat the journal.md that was exported from fallout a long time ago.

**Total time spent: 3.2 hours**

# September 1: BOM and wrapping up the pcb

I really think that I should be more focused on the BOM and finishing up the PCB. I think I will work on the software parts after(I am still not super sure if I can even really do it since it is very heavy in terms of software). Besides finishing up the BOM, I got some advice in #electronics and found that trying to power the RP2040 with a battery exceeds the maximum amount of voltage you are supposed to use to power the RP2040. I decided to use the TPS63000DRCR Buck-Boost converter to solve this. 
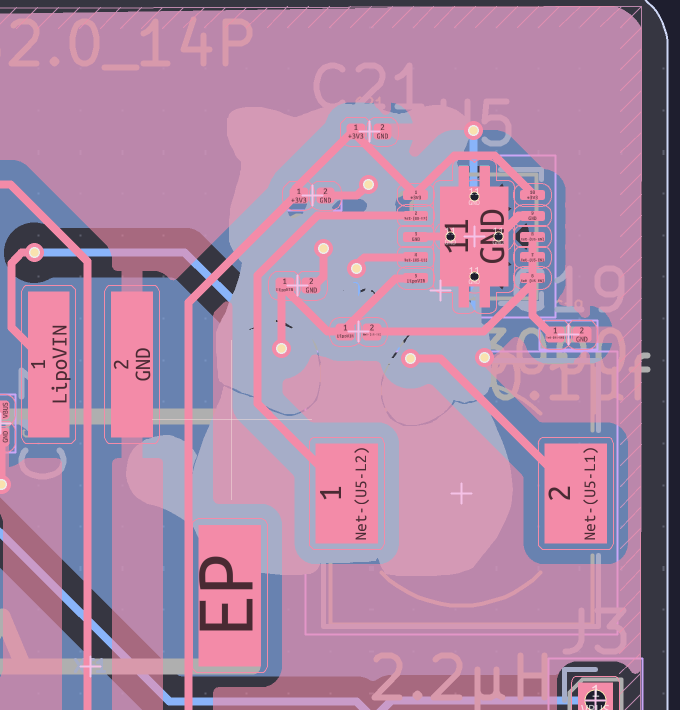
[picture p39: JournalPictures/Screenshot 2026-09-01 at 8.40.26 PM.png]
TPS63000DRCRScreenshot

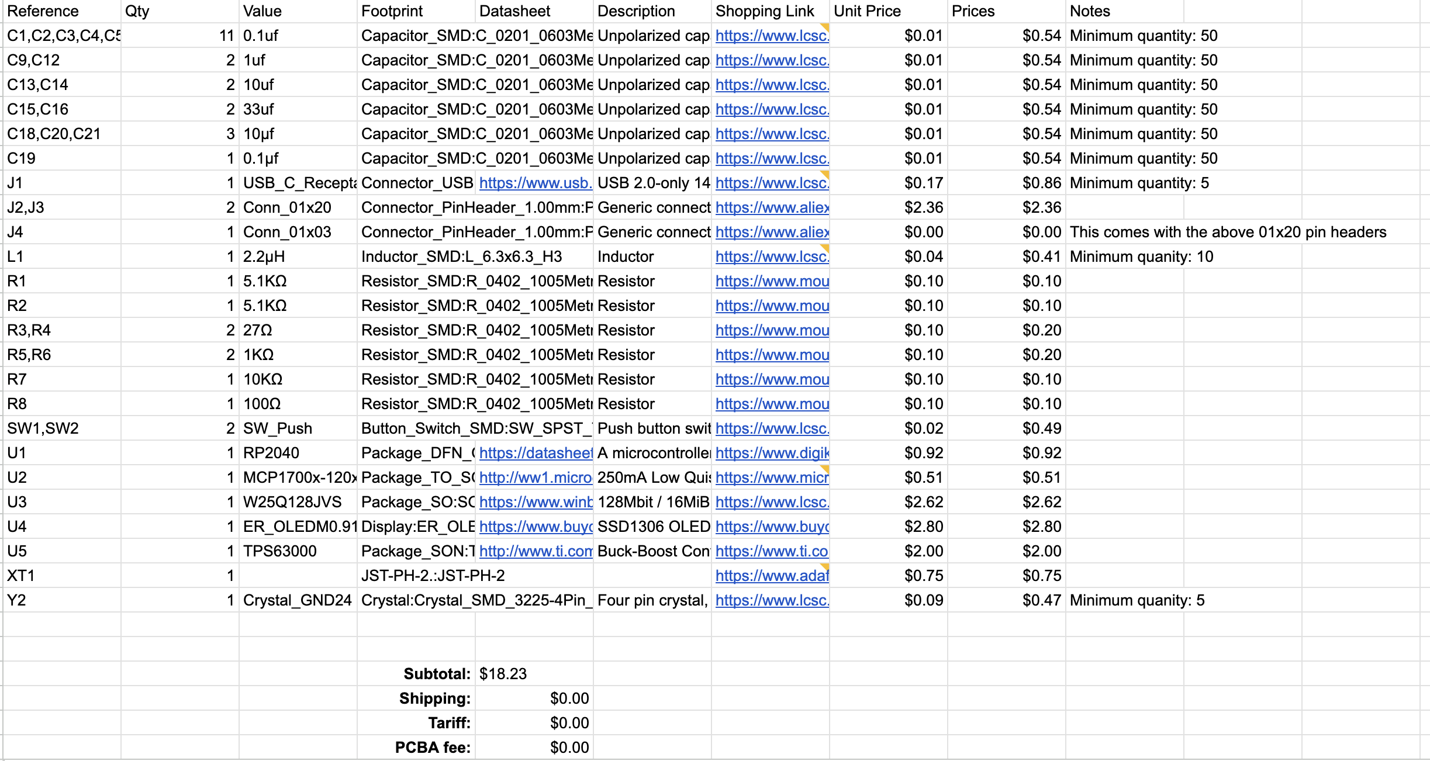
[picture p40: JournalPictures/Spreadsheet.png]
Spreadsheets
This is what it looks like on the pcb at the moment. I also got some work done on the BOM, There is not really anything I have to say about it. The main thing I still need to do from it is I need to check some of the footprints and I need to figure out how much it will cost for a partial PCBA since I cannot properly do surface mount sodering. . Is it weird that I am somewhat proud of how much more organized it is compared to my last hardware projects??? I also need check the footprints. I also did some searching for parts. The next thing I will do is I will be trying to is to try to get 3d models for the components and try to render it.

Recording links:
https://lapse.hackclub.com/timelapse/1ukHRfGwRLbr (53 mins)
https://lapse.hackclub.com/timelapse/UjBjIMcLNt3x (47 mins)
https://lapse.hackclub.com/timelapse/hDr_HyoGHTTv (25 mins)

**Total time spent: 2.08 hours**

# September 2: 
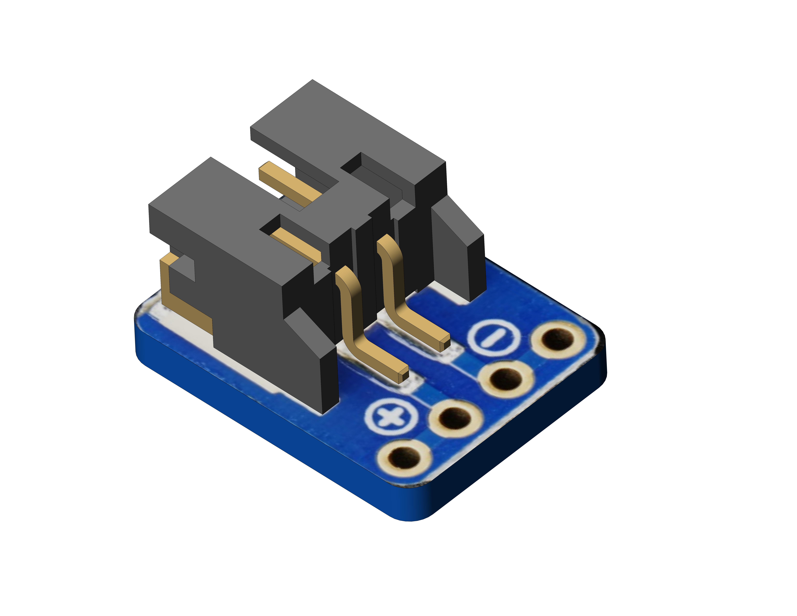
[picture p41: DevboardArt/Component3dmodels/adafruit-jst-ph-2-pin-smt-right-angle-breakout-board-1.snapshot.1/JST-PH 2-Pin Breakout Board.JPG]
PictureOfBatteryPlugHolder
This devlog I worked on several things. Yesterday I got a start on finding the 3d models for the components so that the render actually looked good. I don't have alot to say other than for one of the components(The battery connector), the breakout board was attached in the CAD model. .
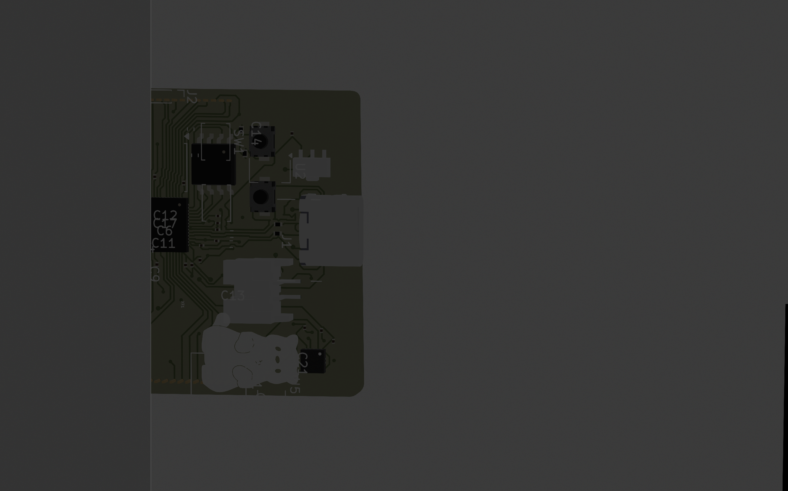
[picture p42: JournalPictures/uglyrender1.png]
uglyrender1
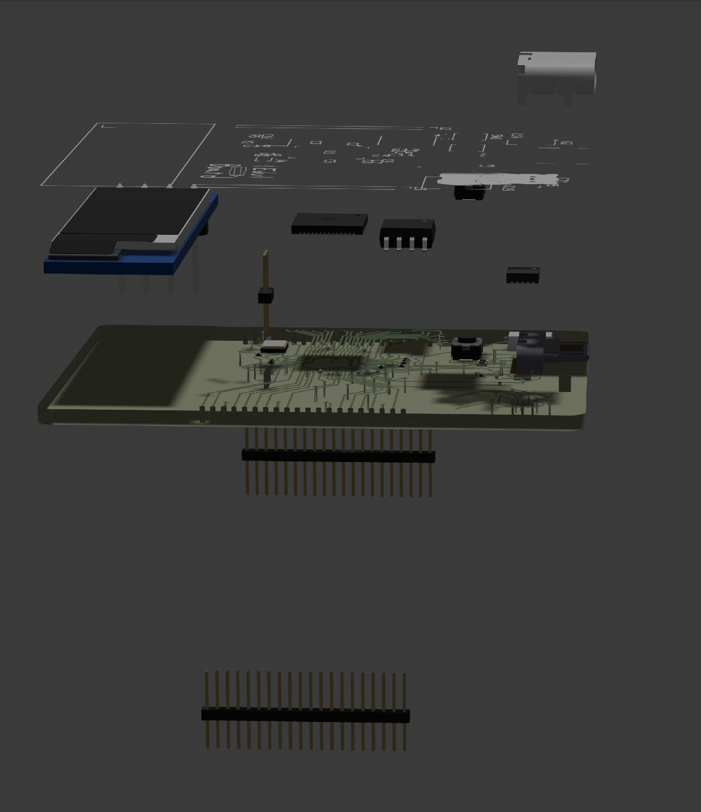
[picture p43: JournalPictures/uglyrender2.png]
uglyrender2
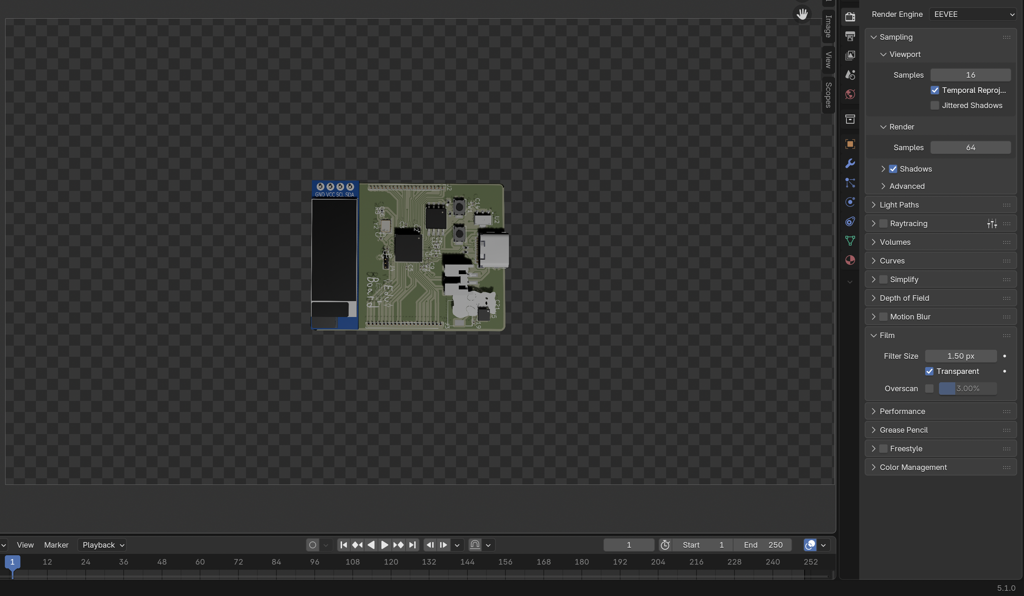
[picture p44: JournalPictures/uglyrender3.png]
uglyrender3
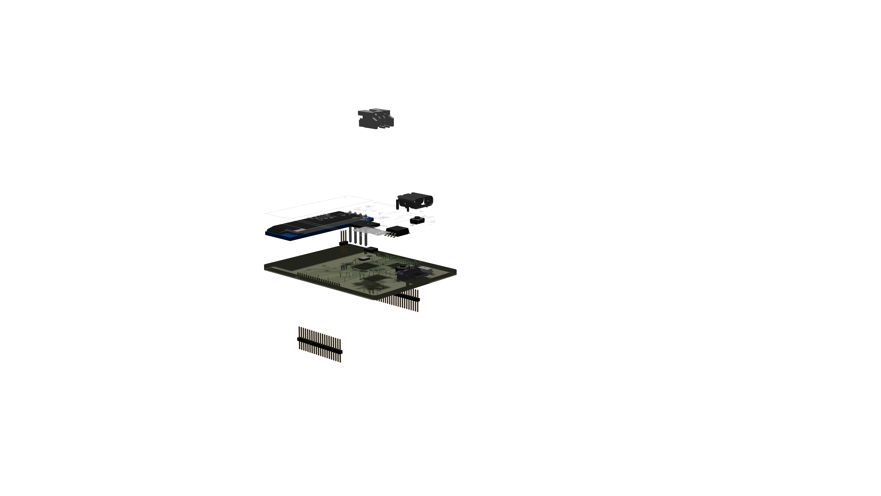
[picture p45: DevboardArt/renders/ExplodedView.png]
Exploded
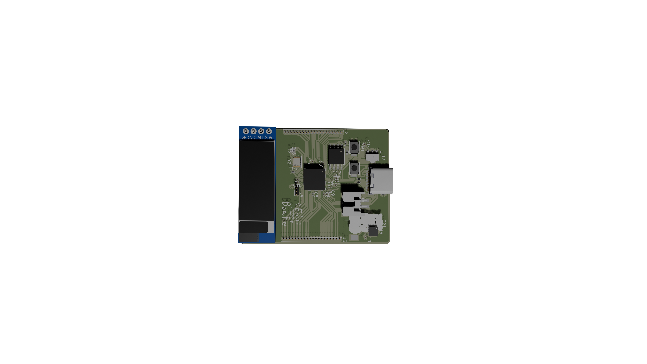
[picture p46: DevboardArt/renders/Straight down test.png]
Straight
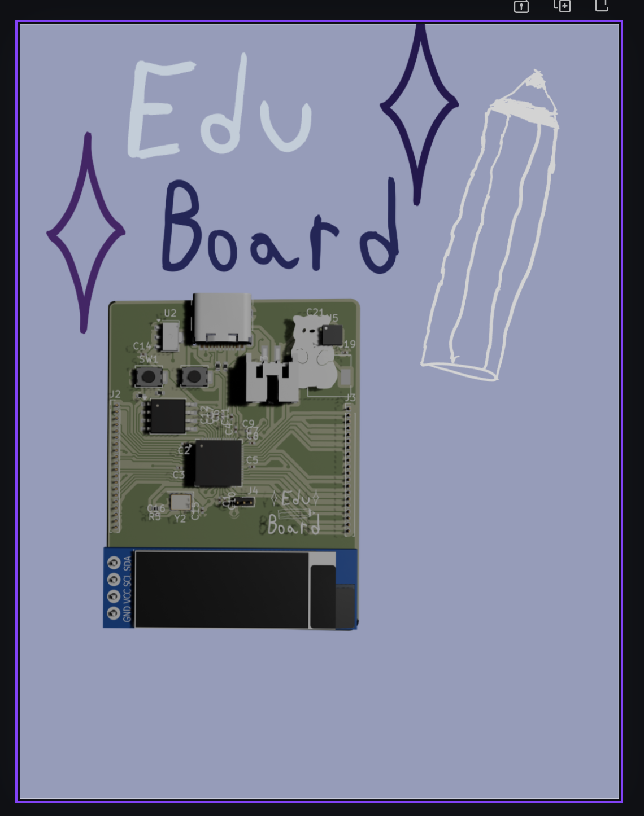
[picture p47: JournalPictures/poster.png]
Poster
Here it is. Next I worked on trying to make the actual render. This was harder than I thought because I originally thought. This is mostly because I was trying to figure out how to make it look good. Most of the previous ones did not look good to me at all.    . Here are some of the failed ones. As you can probably tell. I decided to go with two different rendering styles, one of the styles would be the exploded view and the straight down view.  and  . I also decided to work on the poster. . This is what it looks like right now. I might deviate from my usual use of pastel colors though. I am not super sure about what I will do next. I do really need to work on the software platform though. I am not super sure if I can get that done in time before forge ends. I will realistically use AI to accelerate this process.

Recording links:
https://lapse.hackclub.com/timelapse/PKU9Cg7YqvJJ
https://lapse.hackclub.com/timelapse/CI43GkyVtSil
They are both 1:12-11 lol

**Total Time spent: 2.38 hours**

# September 3

prejournal: I havent got off school yet but I am starting to decide what I need to do. I will be trying to finish up the renders, wrap up the BOM.
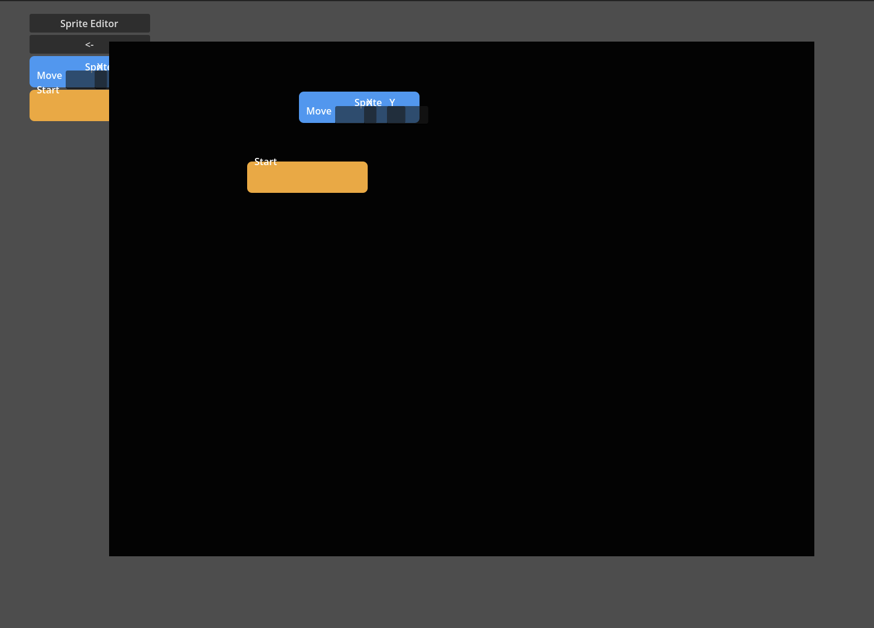
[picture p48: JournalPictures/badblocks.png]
badblocks
Journal: I did not get alot done today. I had a bunch of school work. I mostly worked on the software platform. I also worked a tiny bit on the render. I think that it is basically complete now. The software platform on godot is really messed up imo. I might scrap the entire thing and just restart it. In additon, I was doing the screen share thing(It helps me stay focused for some reason) and I found out that Lookout blacks that part out because technically it is slack I think. I am not completely sure though. I was pretty much just messing around with the settings in godot like the viewport size. With this it should be slightly more reasonable. At this point I am not enjoying this project but I really want to finish this. Most of the time was tracked with hackatime today.  This is what it looks like rn :(

Recording Link:
https://lapse.hackclub.com/timelapse/V_etvXt_qXq-
The rest is hackatimed.

**Total Time spent: 1.25 hours**

# September 4

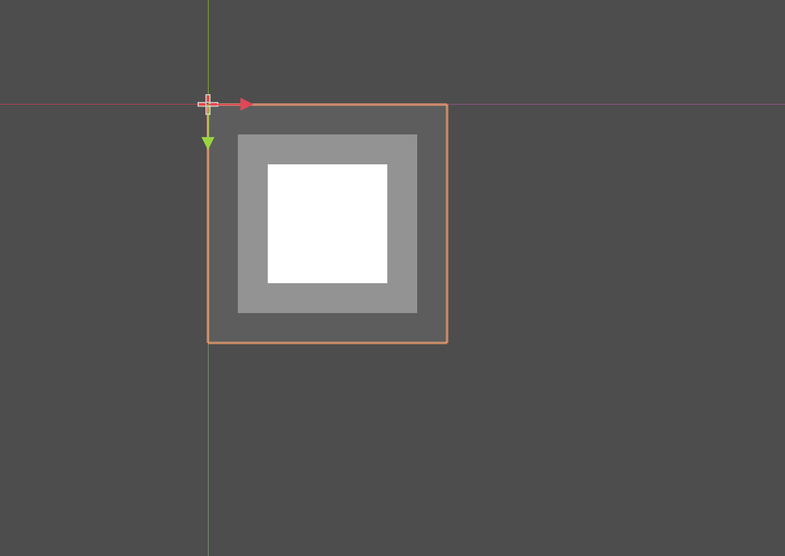
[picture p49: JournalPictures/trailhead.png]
CableHead
I was working on replacing the block system. I was mostly planning on using a system like cables to connect everything, . This is what the trailhead looks like right now. I struggled unreasonably with thsi because I was trying to figure out why the cable was not appearing. I think that I have something wrong with the way I am trying to instantiate the trailhead. I will also check on the line2d that is connecting the trailhead to the actual block.
(Time tracked with hackatime.)

**Total Time spent: 1.03 hours**

# September 6

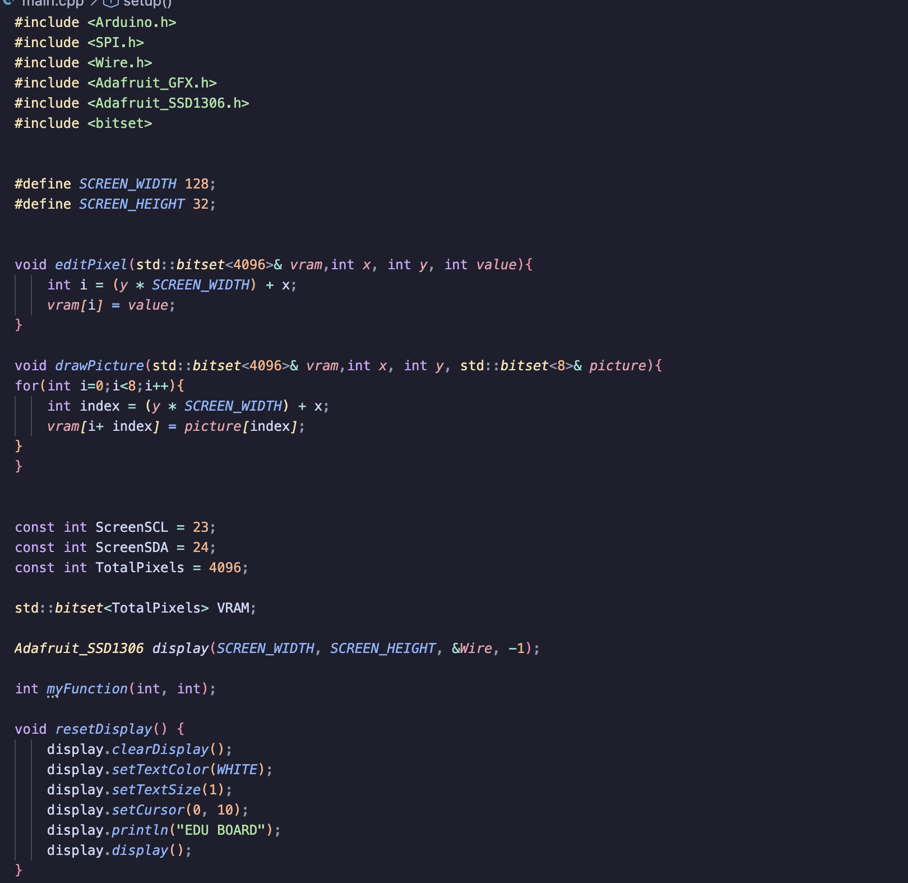
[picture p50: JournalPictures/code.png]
Today, I am going to pivot from doing the godot stuff to doing the firmware in pio. The first thing I want to do is that I want to emulate a system that I made for my godot fantasy console. It was simplier since it does not need to be colored as the display I am using is black and white. I also need to basically provide basic helper functions to do certain operations. This is more for convenience when I get to the godot part of it. For now this will probably be relegated to doing basic stuff like editting specific pixels and drawing specific images at a certain position. I think that the scope creeped up on me too much and now I will be trying to finish the actual firmware of the board. At the moment I need to focus on th3 firmware. Honestly alot of the time I spent today was either spent on ghe journal or screwing around trying to implement the very basics of it all donthsy it would be easier to do stuff later. If it wasn't clear I am not really experienced in arduino c++ so it took me longer. I am go8ng to be hoenst I think that this part will for sure be a struggle. 

**Total Time spent: 1.3 hours**

# September 7

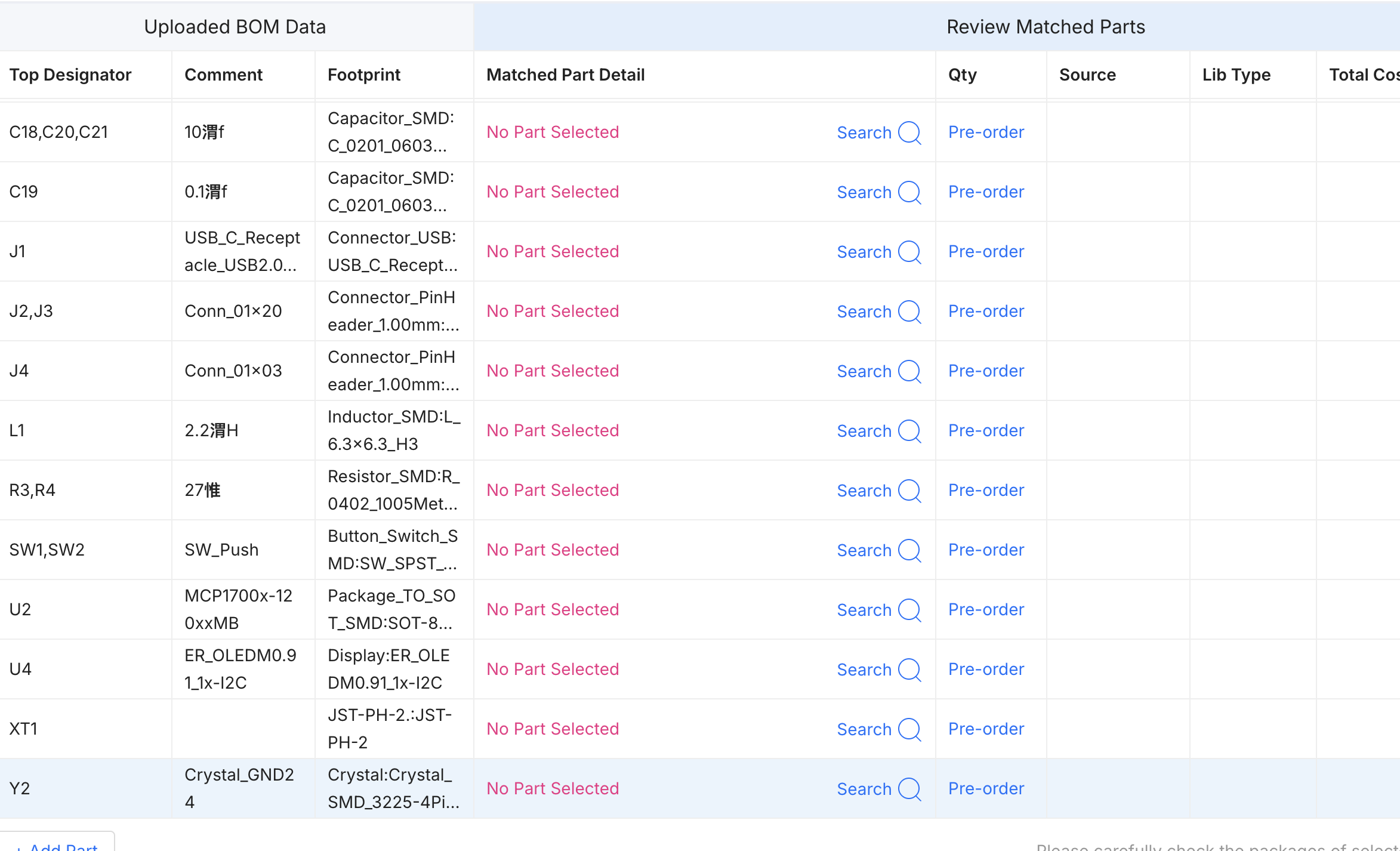
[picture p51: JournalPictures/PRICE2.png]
PRICE2
Today, I am going to continue working on the firmware. I spent alot of time just trying to figure out how to turn on syntax highlighting. Honestly probably too much time doing that. I spent lots of time just digging through the settings to try to find the  There is not much left to do at this point to be honest. I have made all of the helper functions that I can think of immediately. To be honest. there is nothing more for me to do. At this point I am just trying to organize the repo and get the actual final prices down. There are a lot of components that do not have inventory in jlcpcb it seems. The problem is that I will have to do alot of it myself. I don't have anything I can SMD soder with. I intend this to be the last for a while though. After, looking at the prices I think that it would literally be cheaper to get some cheap hotplate off of aliexpress and some soder paste and buy the components indivisually. PRICE  Here are some of the prices.

Recording links
https://lapse.hackclub.com/timelapse/o3eyBZ5dNFtC
And hackatime.

**Total Time Spent: 1.31 hours**

# September 9
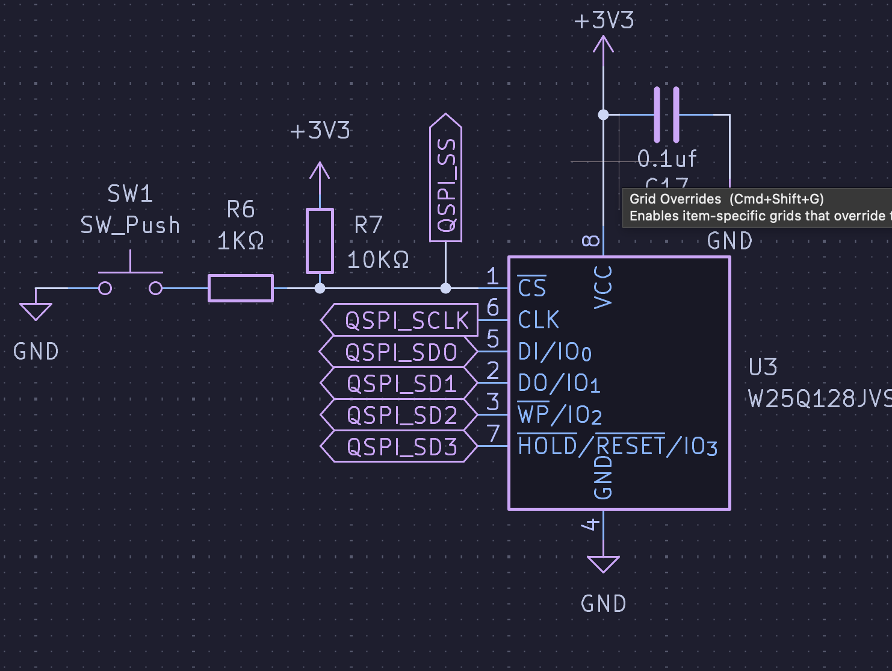
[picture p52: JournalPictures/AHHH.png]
AHH moment
For this devlog I was just working on finsihing up the BOM. I found out that getting a hotplate and some solder paste off of aliepxress is somehow cheaper than doing PCBA. Considering that my footprints are relatively large I think that I will be able to do it. I also worked on my readme. The prices are frankly absurd for PCBA. I think that this is sufficient for the design check. I will need to work abit more on the firmware. I think that there was too much scope creep about the godot part. I just don't feel like it is really worth doing it there are is another project I would rather do at this point.  I nearly forgot that I added a way to flash the mcu. That was kinda startling.

Recording links
https://lapse.hackclub.com/timelapse/BIKCxWAkMjNI
And hackatime

**Total Time Spent: 1.11 hours**

# September 26

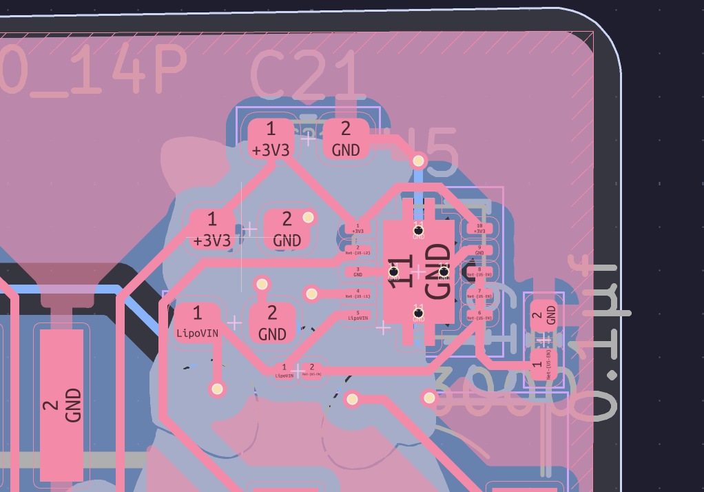
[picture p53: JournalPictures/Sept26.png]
Caps
I haven't got a lot of time to work on hack club projects but I did manage to chagne the size of the capacitors. I had alot of DRC errors from it. There is not alot to say besides that. It took abit with just finding other components that matched the symbol that I needed to use but that was pretty much it. 

**Total Time Spent: 0.716 hours**

# October 4

I really didn't do too much in the time of this journal. I just replaced the model in the current renders. explody render and NormalRender are what it looks like right now. I also got rid of the random floating file. Hopefully I didn't miss anything else.

Recording links
https://lapse.hackclub.com/timelapse/-3xxdbGD38pL

**Total Time spent: 0.5 hours**

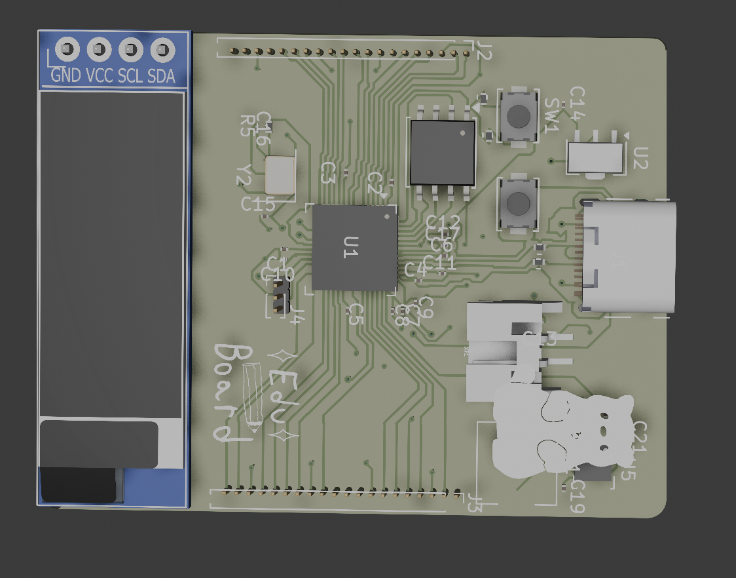
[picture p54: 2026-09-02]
JournalPictures/Screenshot 2026-09-01 at 10.16.42 PM.png

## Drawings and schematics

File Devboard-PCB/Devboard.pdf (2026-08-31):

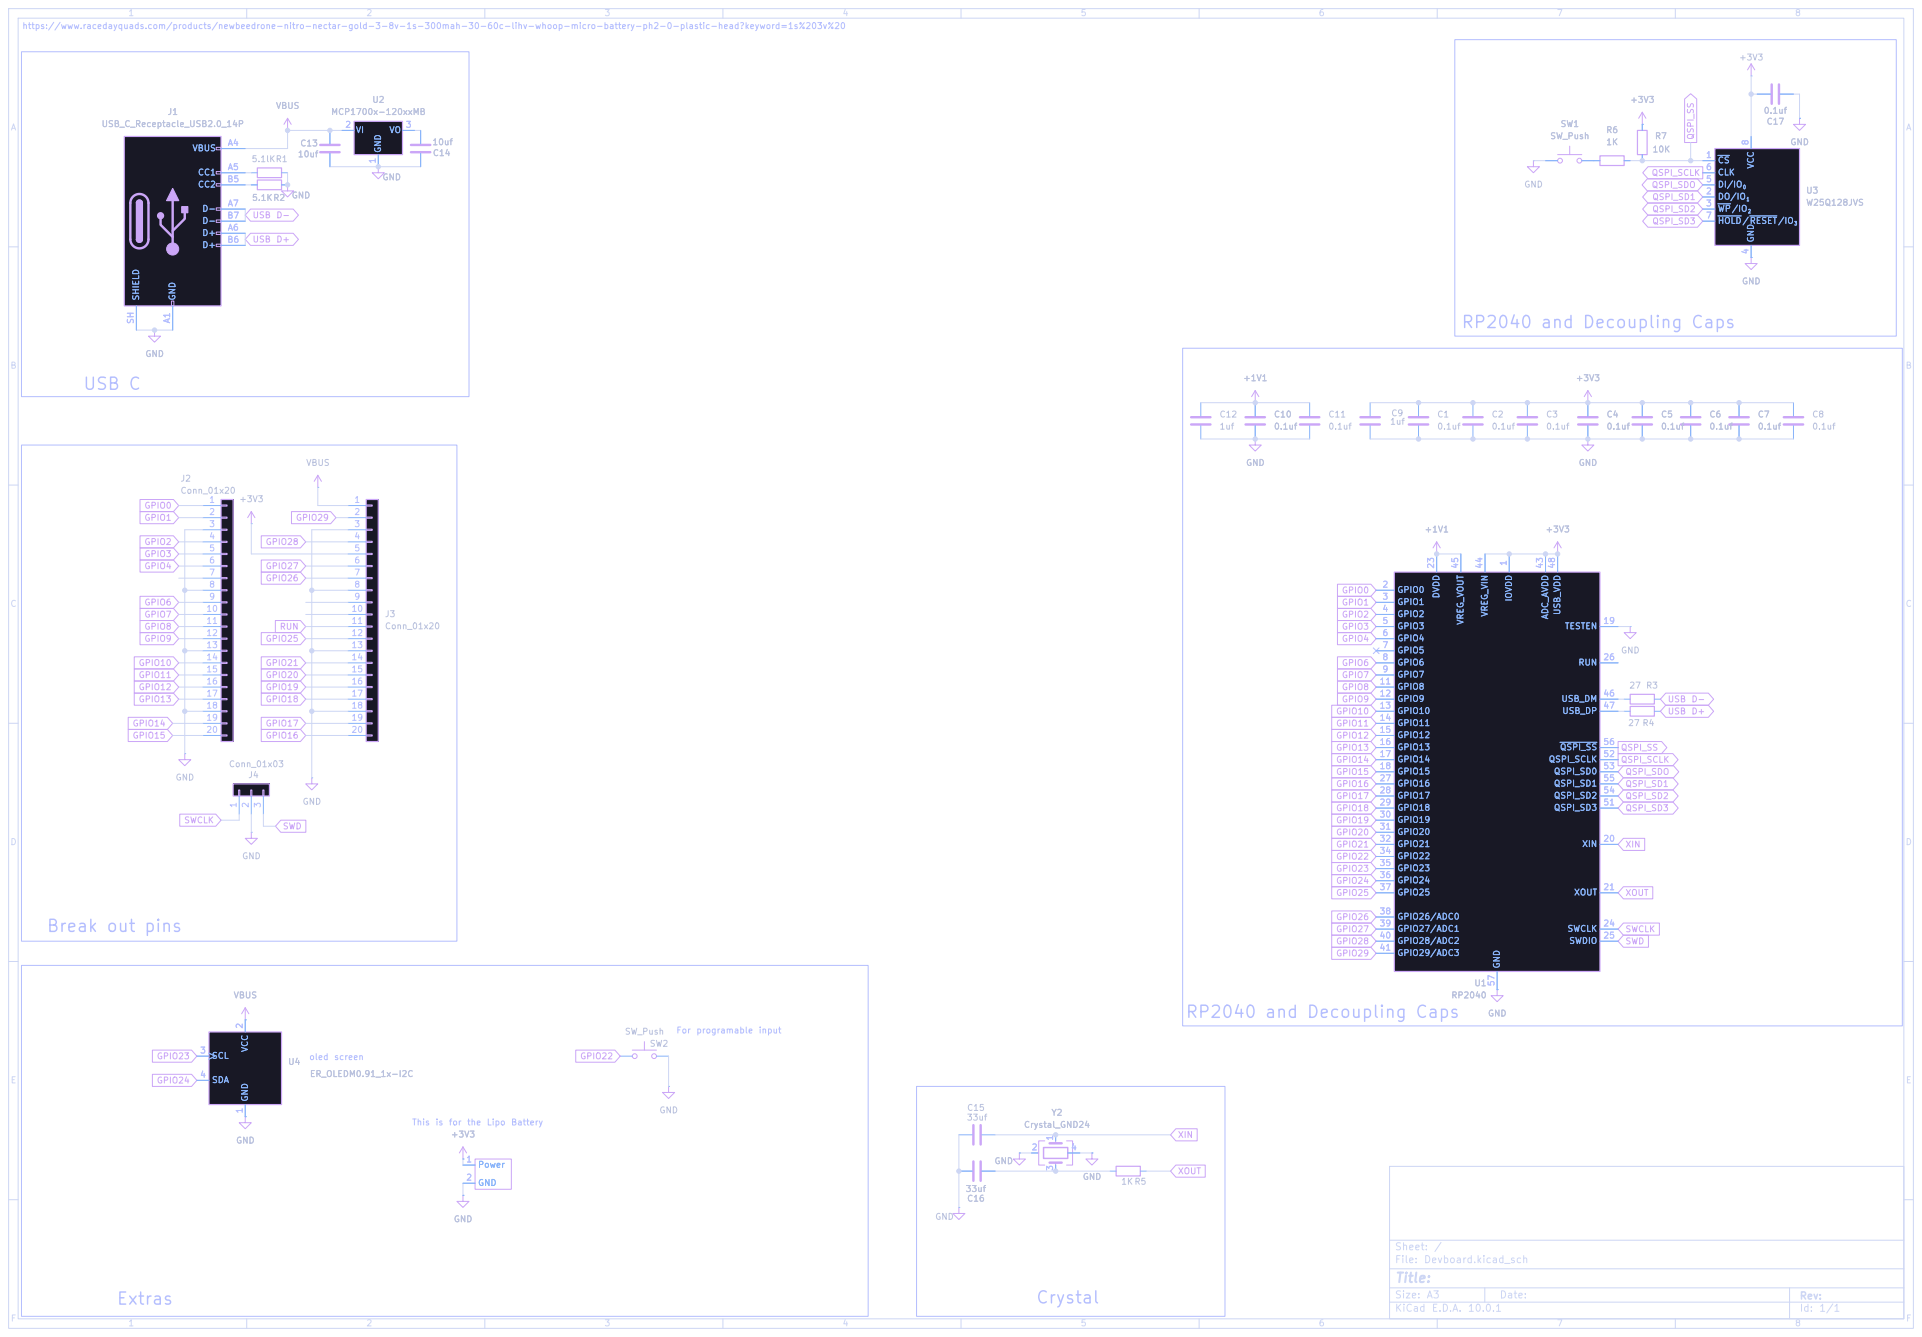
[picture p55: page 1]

https://www.racedayquads.com/products/newbeedrone-nitro-nectar-gold-3-8v-1s-300mah-30-60c-lihv-whoop-micro-battery-ph2-0-plastic-head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

XIN Break out pins

For programable input This is for the Lipo Battery

C15 Y2 Crystal_GND24 33uf

Size: A3 | Rev: | F Date:
KiCad E.D.A. 10.0.1 | Id: 1/1

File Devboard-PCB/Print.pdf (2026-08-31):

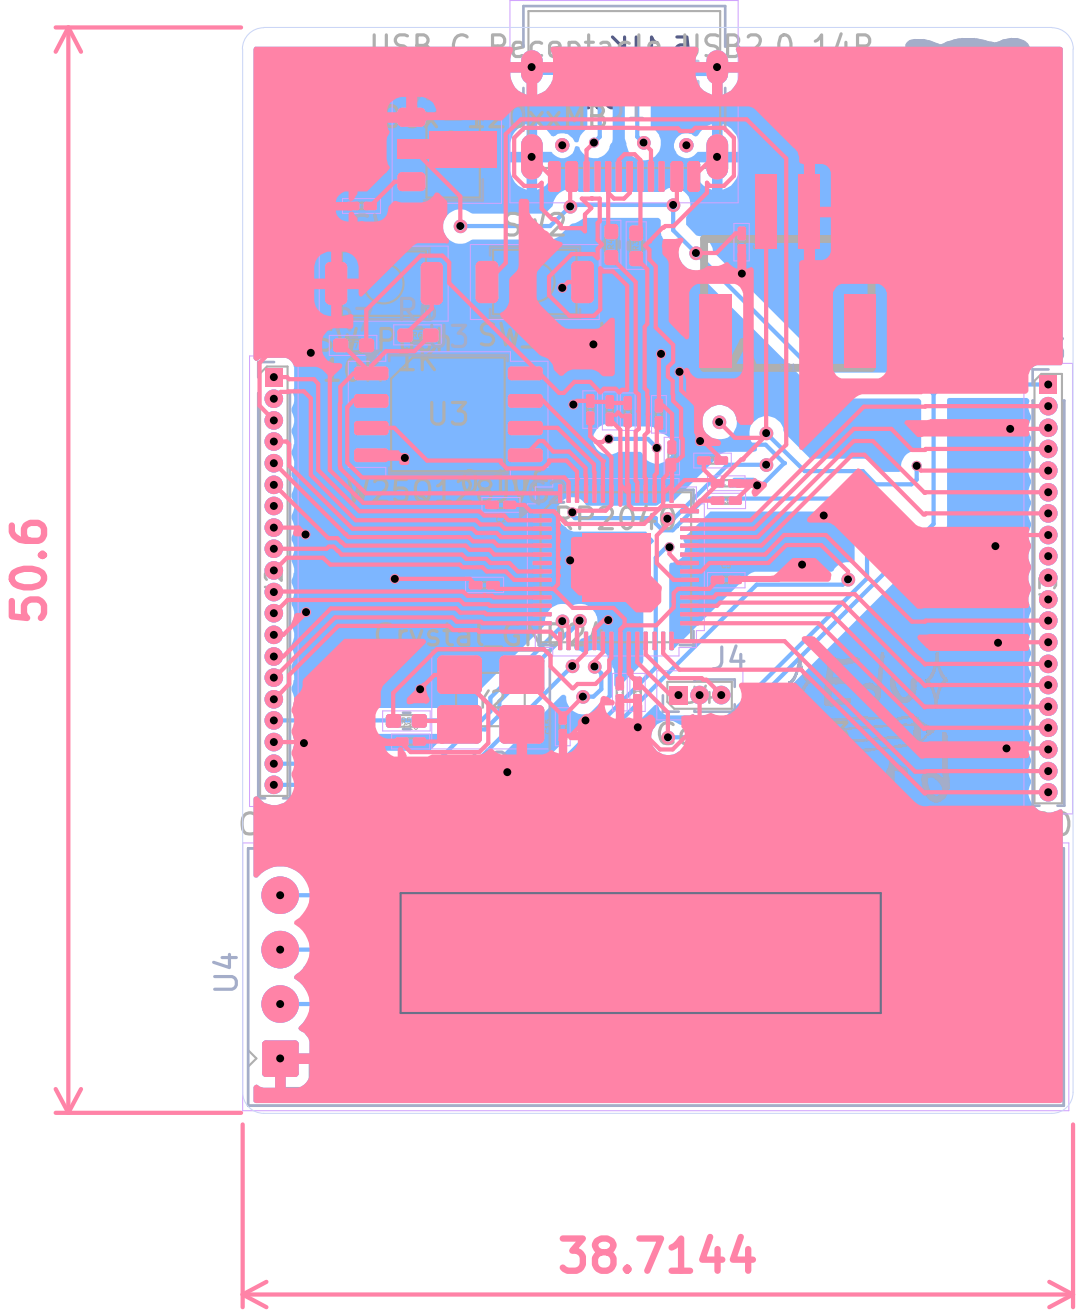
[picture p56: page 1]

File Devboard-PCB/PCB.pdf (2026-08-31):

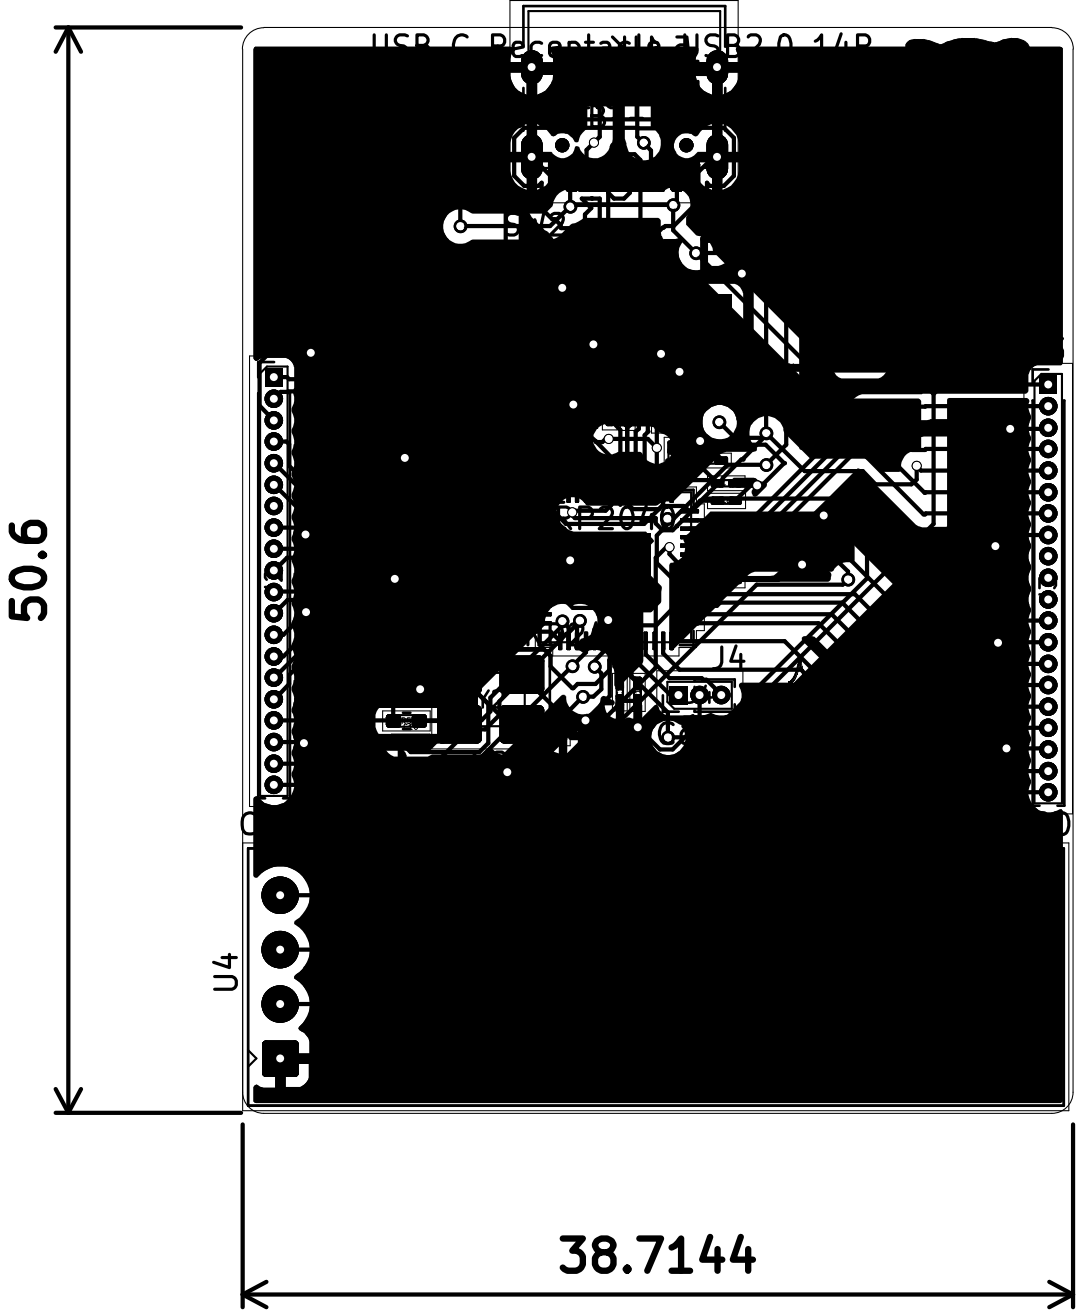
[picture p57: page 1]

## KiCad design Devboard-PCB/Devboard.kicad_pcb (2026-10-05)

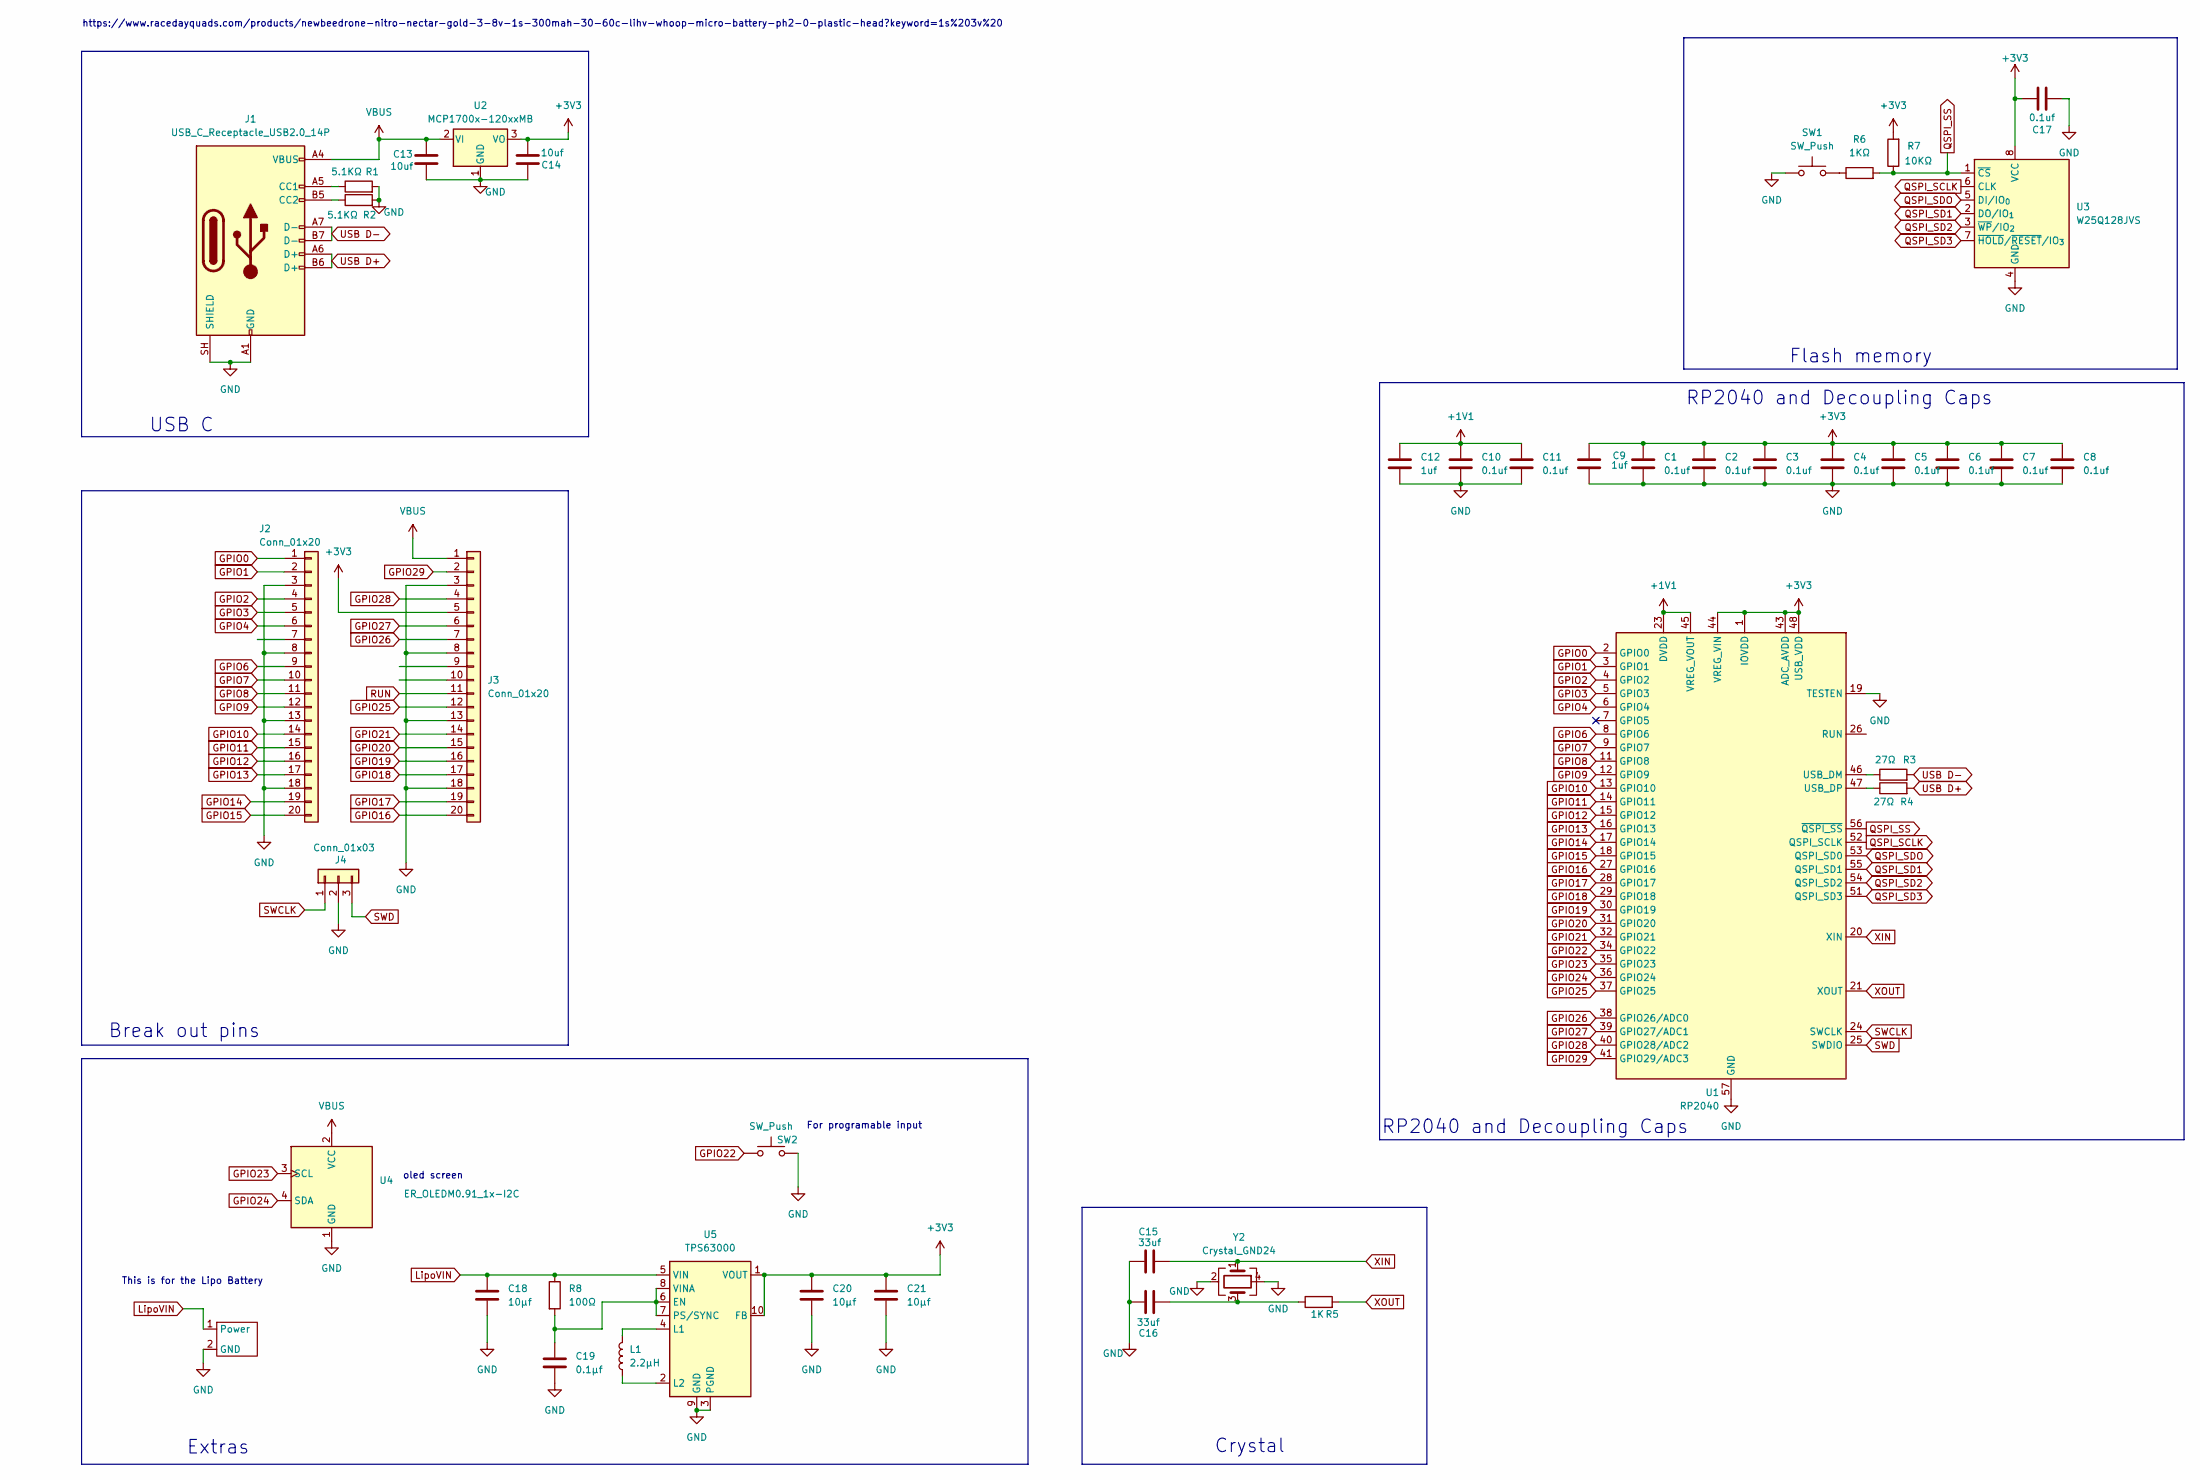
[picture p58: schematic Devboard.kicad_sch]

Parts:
C1, C2, C3, C4, C5, C6, C7, C8, C10, C11, C17: 0.1uf; C_0402_1005Metric_Pad0.74x0.62mm_HandSolder
C9: 1uf; C_0603_1608Metric_Pad1.08x0.95mm_HandSolder
C12: 1uf; C_0402_1005Metric_Pad0.74x0.62mm_HandSolder
C13, C14: 10uf; C_0402_1005Metric_Pad0.74x0.62mm_HandSolder
C15, C16: 33uf; C_0402_1005Metric_Pad0.74x0.62mm_HandSolder
C18, C20, C21: 10μf; C_0603_1608Metric_Pad1.08x0.95mm_HandSolder
C19: 0.1μf; C_0402_1005Metric_Pad0.74x0.62mm_HandSolder
J1: USB_C_Receptacle_USB2.0_14P; USB_C_Receptacle_HRO_TYPE-C-31-M-12
J2, J3: Conn_01x20; PinHeader_1x20_P1.00mm_Vertical
J4: Conn_01x03; PinHeader_1x03_P1.00mm_Vertical
L1: 2.2μH; L_6.3x6.3_H3
R1, R2: 5.1KΩ; R_0402_1005Metric
R3, R4: 27Ω; R_0402_1005Metric
R5: 1K; R_0402_1005Metric
R6: 1KΩ; R_0402_1005Metric
R7: 10KΩ; R_0402_1005Metric
R8: 100Ω; R_0201_0603Metric
SW1, SW2: SW_Push; SW_SPST_TS-1088-xR020
U1: RP2040; QFN-56-1EP_7x7mm_P0.4mm_EP3.2x3.2mm
U2: MCP1700x-120xxMB; SOT-89-3
U3: W25Q128JVS; SOIC-8_5.3x5.3mm_P1.27mm
U4: ER_OLEDM0.91_1x-I2C
U5: TPS63000; Texas_DRC0010J_ThermalVias
XT1: JST-PH-2
Y2: Crystal_GND24; Crystal_SMD_3225-4Pin_3.2x2.5mm

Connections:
+1V1: C10.1, C11.1, C12.1, U1.23 (DVDD), U1.45 (VREG_VOUT), U1.50 (DVDD)
+3V3: C1.1, C2.1, C3.1, C4.1, C5.1, C6.1, C7.1, C8.1, C9.1, C14.2, C17.1, C20.1, C21.1, J3.5, R7.2, U1.1 (IOVDD), U1.10 (IOVDD), U1.22 (IOVDD), U1.33 (IOVDD), U1.42 (IOVDD), U1.43 (ADC_AVDD), U1.44 (VREG_VIN), U1.48 (USB_VDD), U1.49 (IOVDD), U2.3 (VO), U3.8 (VCC), U5.1 (VOUT), U5.10 (FB)
GND: C1.2, C2.2, C3.2, C4.2, C5.2, C6.2, C7.2, C8.2, C9.2, C10.2, C11.2, C12.2, C13.2, C14.1, C15.1, C16.1, C17.2, C18.2, C19.2, C20.2, C21.2, J1.A1 (GND), J1.A12 (GND), J1.B1 (GND), J1.B12 (GND), J1.SH (SHIELD), J2.3, J2.8, J2.13, J2.18, J3.3, J3.8, J3.13, J3.18, J4.2, R1.2, R2.2, SW1.1, SW2.2, U1.19 (TESTEN), U1.57 (GND), U2.1 (GND), U3.4 (GND), U4.1 (GND), U5.3 (PGND), U5.9 (GND), U5.11 (PGND), XT1.2 (GND), Y2.2 (G), Y2.4 (G)
GPIO0: J2.1, U1.2 (GPIO0)
GPIO1: J2.2, U1.3 (GPIO1)
GPIO2: J2.4, U1.4 (GPIO2)
GPIO3: J2.5, U1.5 (GPIO3)
GPIO4: J2.6, U1.6 (GPIO4)
GPIO6: J2.9, U1.8 (GPIO6)
GPIO7: J2.10, U1.9 (GPIO7)
GPIO8: J2.11, U1.11 (GPIO8)
GPIO9: J2.12, U1.12 (GPIO9)
GPIO10: J2.14, U1.13 (GPIO10)
GPIO11: J2.15, U1.14 (GPIO11)
GPIO12: J2.16, U1.15 (GPIO12)
GPIO13: J2.17, U1.16 (GPIO13)
GPIO14: J2.19, U1.17 (GPIO14)
GPIO15: J2.20, U1.18 (GPIO15)
GPIO16: J3.20, U1.27 (GPIO16)
GPIO17: J3.19, U1.28 (GPIO17)
GPIO18: J3.17, U1.29 (GPIO18)
GPIO19: J3.16, U1.30 (GPIO19)
GPIO20: J3.15, U1.31 (GPIO20)
GPIO21: J3.14, U1.32 (GPIO21)
GPIO22: SW2.1, U1.34 (GPIO22)
GPIO23: U1.35 (GPIO23), U4.3 (SCL)
GPIO24: U1.36 (GPIO24), U4.4 (SDA)
GPIO25: J3.12, U1.37 (GPIO25)
GPIO26: J3.7, U1.38 (GPIO26/ADC0)
GPIO27: J3.6, U1.39 (GPIO27/ADC1)
GPIO28: J3.4, U1.40 (GPIO28/ADC2)
GPIO29: J3.2, U1.41 (GPIO29/ADC3)
LipoVIN: C18.1, R8.1, U5.5 (VIN), XT1.1 (Power)
unnamed: C16.2, R5.1, Y2.3
unnamed: J1.A5 (CC1), R1.1
unnamed: J1.B5 (CC2), R2.1
unnamed: R6.1, SW1.2
unnamed: R3.1, U1.46 (USB_DM)
unnamed: R4.1, U1.47 (USB_DP)
unnamed: C19.1, R8.2, U5.6 (EN), U5.7 (PS/SYNC), U5.8 (VINA)
unnamed: L1.2, U5.4 (L1)
unnamed: L1.1, U5.2 (L2)
QSPI_SCLK: U1.52 (QSPI_SCLK), U3.6 (CLK)
QSPI_SD1: U1.55 (QSPI_SD1), U3.2 (DO/IO_{1})
QSPI_SD2: U1.54 (QSPI_SD2), U3.3 (~WP/IO_{2})
QSPI_SD3: U1.51 (QSPI_SD3), U3.7 (~HOLD/~RESET/IO_{3})
QSPI_SDO: U1.53 (QSPI_SD0), U3.5 (DI/IO_{0})
QSPI_SS: R6.2, R7.1, U1.56 (~QSPI_SS), U3.1 (~CS)
RUN: J3.11
SWCLK: J4.1, U1.24 (SWCLK)
SWD: J4.3, U1.25 (SWDIO)
USB D+: J1.A6 (D+), J1.B6 (D+), R4.2
USB D-: J1.A7 (D-), J1.B7 (D-), R3.2
VBUS: C13.1, J1.A4 (VBUS), J1.A9 (VBUS), J1.B4 (VBUS), J1.B9 (VBUS), J3.1, U2.2 (VI), U4.2 (VCC)
XIN: C15.2, U1.20 (XIN), Y2.1
XOUT: R5.2, U1.21 (XOUT)

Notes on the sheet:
Break out pins
https://www.racedayquads.com/products/newbeedrone-nitro-nectar-gold-3-8v-1s-300mah-30-60c-lihv-whoop-micro-battery-ph2-0-plastic-head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
Flash memory
USB C
RP2040 and Decoupling Caps
Extras
Crystal
oled screen
This is for the Lipo Battery
For programable input

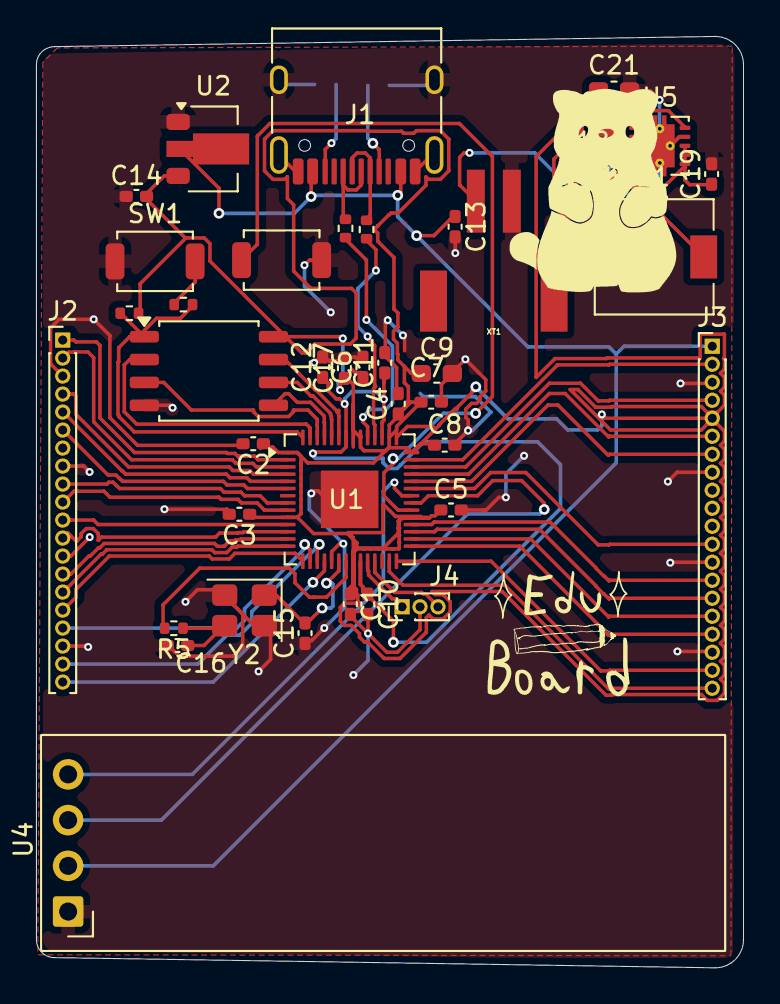
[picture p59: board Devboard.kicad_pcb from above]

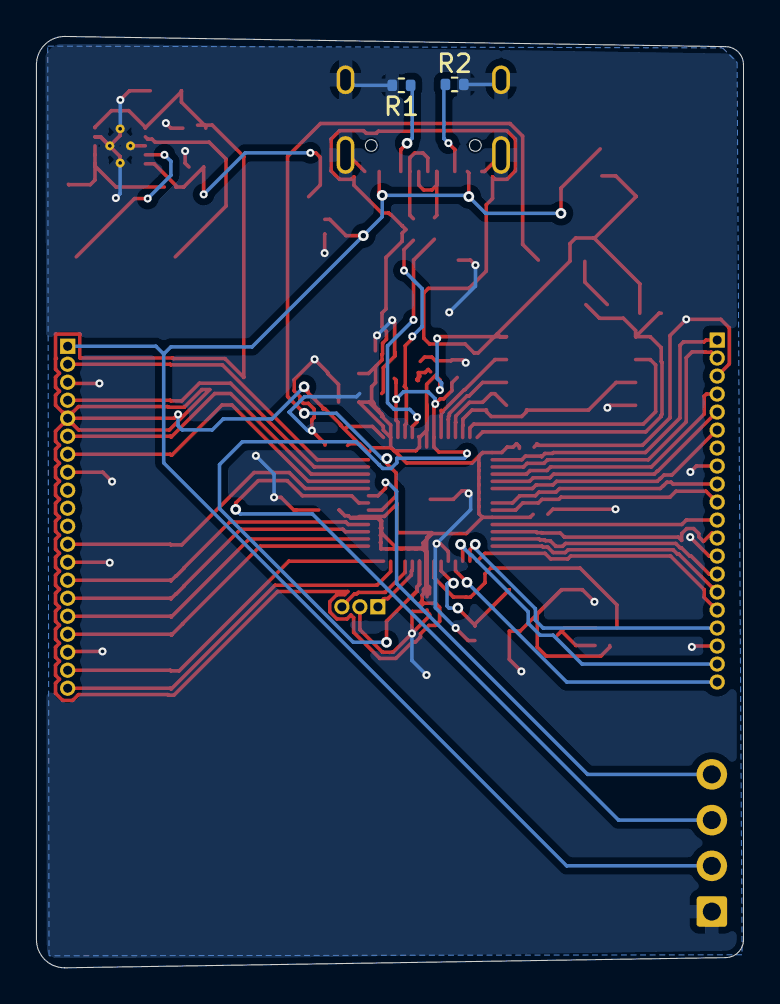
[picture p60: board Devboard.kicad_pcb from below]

Board: 2 copper layers, 39.3 x 51.7 mm, 43 parts (2 on the bottom side), 55 nets.

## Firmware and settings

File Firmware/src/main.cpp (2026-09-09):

#include <Arduino.h>
#include <SPI.h>
#include <Wire.h>
#include <Adafruit_GFX.h>
#include <Adafruit_SSD1306.h>
#include <bitset>


#define SCREEN_WIDTH 128;
#define SCREEN_HEIGHT 32;


void editPixel(std::bitset<4096>& vram,int x, int y, int value){
    int i =	(y * SCREEN_WIDTH) + x;
    vram[i] = value;
}

void drawPicture(std::bitset<4096>& vram,int x, int y, std::bitset<8>& picture){
for(int i=0;i<8;i++){
    int index =	(y * SCREEN_WIDTH) + x;
    vram[i+ index] = picture[index];
}
}


const int ScreenSCL = 23;
const int ScreenSDA = 24;
const int TotalPixels = 4096;

std::bitset<TotalPixels> VRAM;

Adafruit_SSD1306 display(SCREEN_WIDTH, SCREEN_HEIGHT, &Wire, -1);

int myFunction(int, int);

void resetDisplay() {
    display.clearDisplay();
    display.setTextColor(WHITE);
    display.setTextSize(1);
    display.setCursor(0, 10);
    display.println("EDU BOARD");
    display.display();
}


void setup() {
  resetDisplay();
  delay(1);
  display.println("EDU BOARD");
  display.println("WELCOME");
}

void loop() {
  for(int i=0; i < TotalPixels; i++){
    int x = i % SCREEN_WIDTH;
    int y = i / SCREEN_WIDTH;
    if (VRAM[i] == 1) {
      display.drawPixel(x,y, WHITE);
    } else{
     display.drawPixel(x,y, BLACK);
    }
  }
  display.display();
}

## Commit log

2026-05-03 Worked on schematic
    [Devboard.kicad_pcb, Devboard.kicad_sch]
2026-05-04 Worked on adding batteries and an oled screen.
    [Devboard.kicad_pcb, Devboard.kicad_sch]
2026-05-05 Worked on routing
    [Devboard.kicad_pcb, Devboard.kicad_sch]
2026-05-06 Routed the pins more.
    [Devboard.kicad_pcb, Devboard.kicad_sch]
2026-05-07 Worked on routing the PCB more
    [Devboard.kicad_pcb]
2026-05-11 Worked on more routing
    [Devboard.kicad_pcb]
2026-05-12 Routing part 2 electric boogalooo
    [Devboard.kicad_pcb, Devboard.kicad_sch]
2026-05-15 Lowk forgot to push yesterday but did more routing
    yesterday I made ok progress. I need to move the pins tho
    [Devboard.kicad_pcb]
2026-05-18 Finished routing
    A pretty productive day so far
    [Devboard.kicad_pcb]
2026-05-21 Worked on the art of devboard
    Got the assets made and started to implement them.
    [Devboard.kicad_pcb]
2026-05-22 Worked on the firmware and the godot app
    ok progress
    [Devboard.kicad_pcb]
2026-05-30 Updated Journal
    [plugin.cfg]
2026-08-31 Added the TPS63000 buck-boost converter
    Next, I need to route everything again. I also need to finish the BOM. The silkscreen could also use some work imo. I also had to change some of the symbols. I will likely be doing pcba.
    https://lapse.hackclub.com/timelapse/hDr_HyoGHTTv
    https://lapse.hackclub.com/timelapse/UjBjIMcLNt3x
    [Devboard.csv, Devboard.kicad_pcb, Devboard.kicad_sch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]
2026-09-02 Journaled and worked on getting a render done.
    I got a basic render working with the silkscreen. Orignally I had trouble trying to make the silscreen show up. The solution was to raise the silkscreen above the rest of the pcb 3d model.
    [Devboard.kicad_pcb, Devboard.kicad_sch, Eduboard.step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]
2026-09-03 Worked on the render
    Next I need to finish up a basic version of the software portion and finish the poster.
    [Devboard Straight On.blend, Devboard.kicad_pcb, Eduboard.step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]
2026-09-04 aghiwaohugrwahugqh9b I am starting to hate this
    Worked on the godot portion. I need to make the snapping work and I need to make the other blocks.
    [Devboard.kicad_pcb, devboard.blend]
2026-09-05 Worked on cable version of connecting
    [devboard.blend]
2026-09-09 Found out how much pcba costs
    [Devboard - Devboard.csv, bom.csv, designators.csv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]
2026-09-10 Need to wrap the readme up
    [BOM-PCBA.csv, BOM.csv]
2026-09-15 Organized the repo a little bit
    [Devboard - Devboard.csv, Devboard.csv, Devboard.kicad_pcb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]
2026-09-27 Worked on replacing the 0201 capacitors with 0402 and 0603 caps
    [BOM.csv, Devboard-new.csv, Devboard.kicad_pcb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]
2026-10-05 Got rid of excess files and switched the capacitors off of 0201
    [Devboard Straight On copy.blend, Devboard.kicad_pcb, Eduboard.step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]
2026-10-06 Fixed renders not showing up
    [Devboard Straight On copy.blend]
